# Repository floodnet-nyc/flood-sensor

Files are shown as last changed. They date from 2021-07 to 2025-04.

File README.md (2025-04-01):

<p align="center">
    <a href="https://www.floodnet.nyc/">
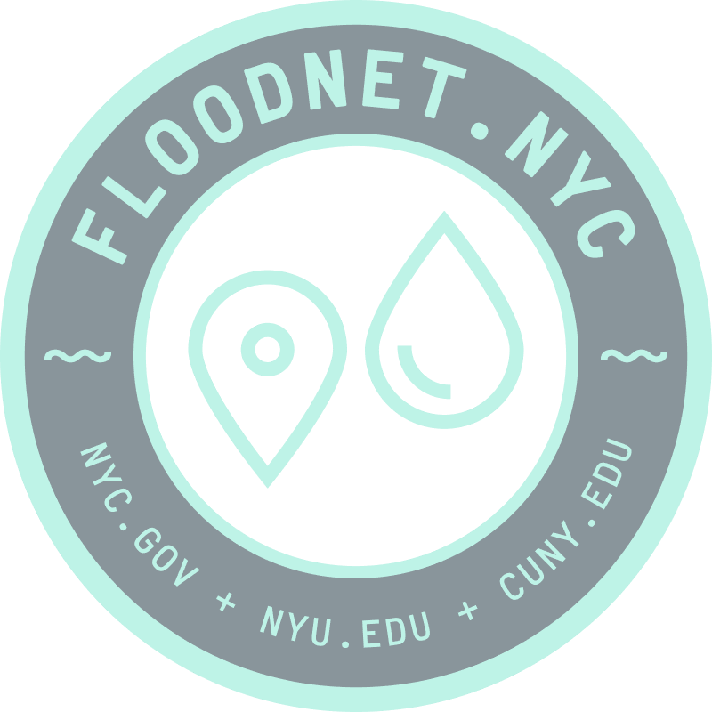
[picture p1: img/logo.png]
        
    </a>
</p>
<br>

<table class="center">
<thead>
  <tr>
    <td><a href="https://docs.google.com/forms/d/e/1FAIpQLScIM4Nu0z6l5HO8uzl9k4RGRSzU549LakNMNijnjGAHodFg9w/viewform" target="_blank" rel="noopener noreferrer">Suggest a sensor location</a><br></td>
    <td><a href="mailto:info@floodnet.nyc" target="_blank" rel="noopener noreferrer">@ Contact us</a></td>
  </tr>
</thead>
</table>

<br>
This repository houses information regarding the build, deployment, and maintenance of the FloodnNet project's flood sensor.

- [About FloodNet](#about-floodnet)
- [How to build a flood sensor](#how-to-build-a-flood-sensor)
- [How to deploy a flood sensor](#how-to-deploy-a-flood-sensor)
- [How to maintain a flood sensor](#how-to-maintain-a-flood-sensor)
- [How to submit an issue](#how-to-submit-an-issue)
- [Additional resources](#additional-resources)

If you make use of the hardware designs and firmware in this repository for any purpose, the project should be listed as “FloodNet (New York University and The City University of New York)”, and cited as the following:

Mydlarz, C., Sai Venkat Challagonda, P., Steers, B., Rucker, J., Brain, T., Branco, B., Burnett, H.E., Kaur, A., Fischman, R., Graziano, K., Krueger, K., Henaff, E., Ignace, V., Jozwiak, E., Palchuri, J., Pierone, P., Rothman, P., Toledo-Crow, R., Silverman, A.I. (2024) FloodNet: Low-cost ultrasonic sensors for real-time measurement of hyperlocal, street-level floods in New York City. Water Resources Research, 60, e2023WR036806. https://doi.org/10.1029/2023WR036806

Please note that the contents of this repository are subject to the Creative Commons Attribution-NonCommercial-ShareAlike 4.0 International License (see footer of page).

# About FloodNet
FloodNet is a partnership between academic researchers at New York University and the City University of New York, and NYC municipal agencies (NYC Mayor’s Office of Climate & Environmental Justice and Mayor’s Office of the Chief Technology Officer), working in consultation with community organizations.



**note:** This repository is relevant only to the flood sensors, i.e., the end-device sensing component within a larger sensor network infrastructure. For more details about the complete network infrastructure(figure below) refer to the FloodNet [documentation website](https://floodnet-nyc.github.io//real-time-data-pipeline/#31-data-flow-pipeline-overview). 

Further, [Gateway](https://github.com/floodnet-nyc/floodnet-gateway) and [NodeRED](https://github.com/floodnet-nyc/floodnet-nodered) repositiories are linked in the additional resources section for reference. 

<br>
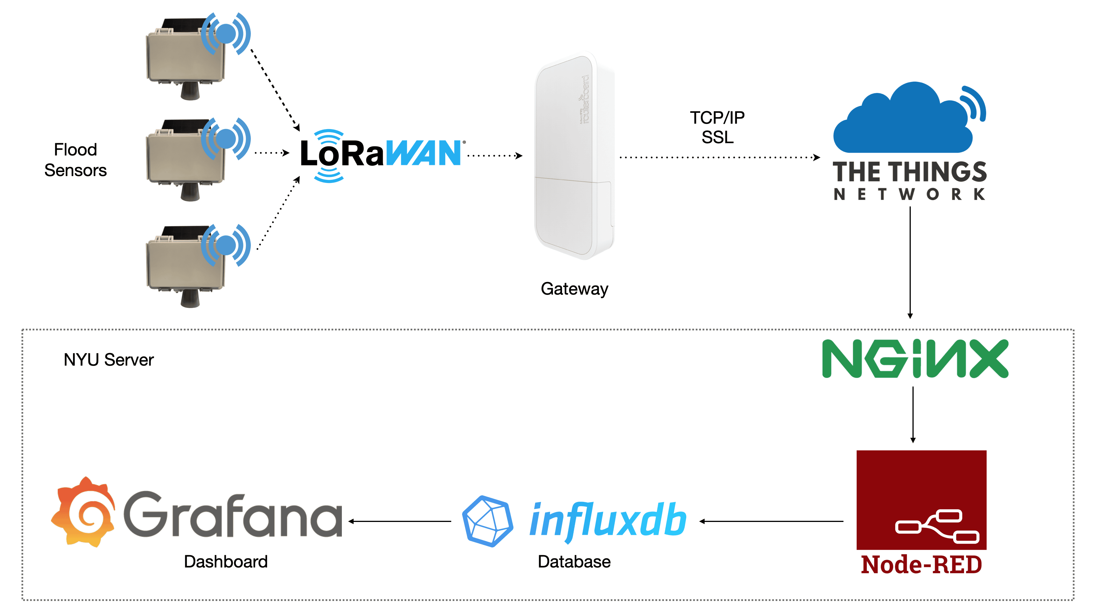
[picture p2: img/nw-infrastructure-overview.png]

<br>

# How to build a flood sensor
This section contains the necessary resources to build a flood sensor from the raw materials state to a final product. 

## BOM
  - The total sensor cost per unit is below $200. 
  - When mounting hardware is included the total cost of the sensor plus mounting hardware comes around $210. 
  - A list of complete bill of materials for the sensor and mounting hardware is available in the [BOM](https://github.com/floodnet-nyc/flood-sensor/tree/main/hardware/BOM.md) document.

## Sensor build instructions with Quality Assurance Procedures
  - The step-by-step sensor build instructions including images and quality assurance steps are detailed in the [Sensor build with Quality Assurance Procedures](https://floodnet-nyc.github.io//quality-management/sensor-assembly-qap/) page on the FloodNet's documentation website to ensure high quality sensor builds with consistency.

### Installing sensor software
  - After the sensor assembly stage is the installation of the sensor firmware. To install the sensor's firmware follow the steps detailed in the of the firmware folder's [README.md](https://github.com/floodnet-nyc/flood-sensor/tree/main/firmware#readme). 

## Quality Control and testing
  - After the production/assembly stage, quality control (QC) tests are performed on every sensor to validate the data quality. 
  - In-lab testing and Quality Control checks are detailed in the FloodNet's [Quality Control page](https://floodnet-nyc.github.io//quality-management/quality-control/) on the documentation website.

<br>

# How to deploy a flood sensor

The FloodNet's flood sensors are deployed on street sign posts, over the sidewalk, following the permission from NYC to do so. This section details instructions to identify a deployment location, choosing an optimal mounting option, and finally, deploying a flood sensor.

## Deployment location identification strategy
  - Sensor deployment locations are determined in consultation with government and community partners, using criteria that include estimated risks of flood hazard and impact, social vulnerability, and spatial coverage.
  - Further, multiple assessment strategies combined contribute to the sensor locations identification process, including but not limited to - community engagement, flood maps, historically flood-prone neighborhoods, and city agency recommendations.
  - The [Flood Hotspots Identifacation manual](https://github.com/floodnet-nyc/flood-sensor/blob/f238a23d92843cad2c458d202e6335a0c9118099/deployment/flood-hotspots-identification.md) details the strategies mentioned above.

## Flood sensor deployment steps

#### Choosing an optimal mounting option
The sensor is susceptable to noise in the following scenarios - mounted over grass, mounted over soil/bumpy sidewalk, and when sensor measuring area is of different heights for example is half sidewalk and half road. 

<p>
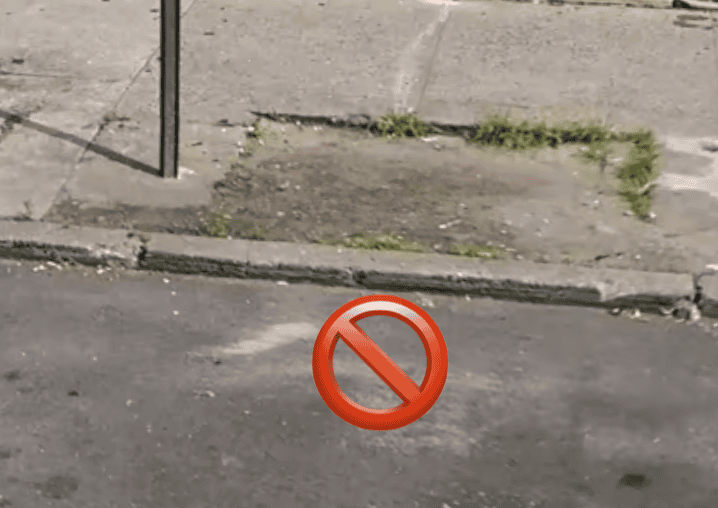
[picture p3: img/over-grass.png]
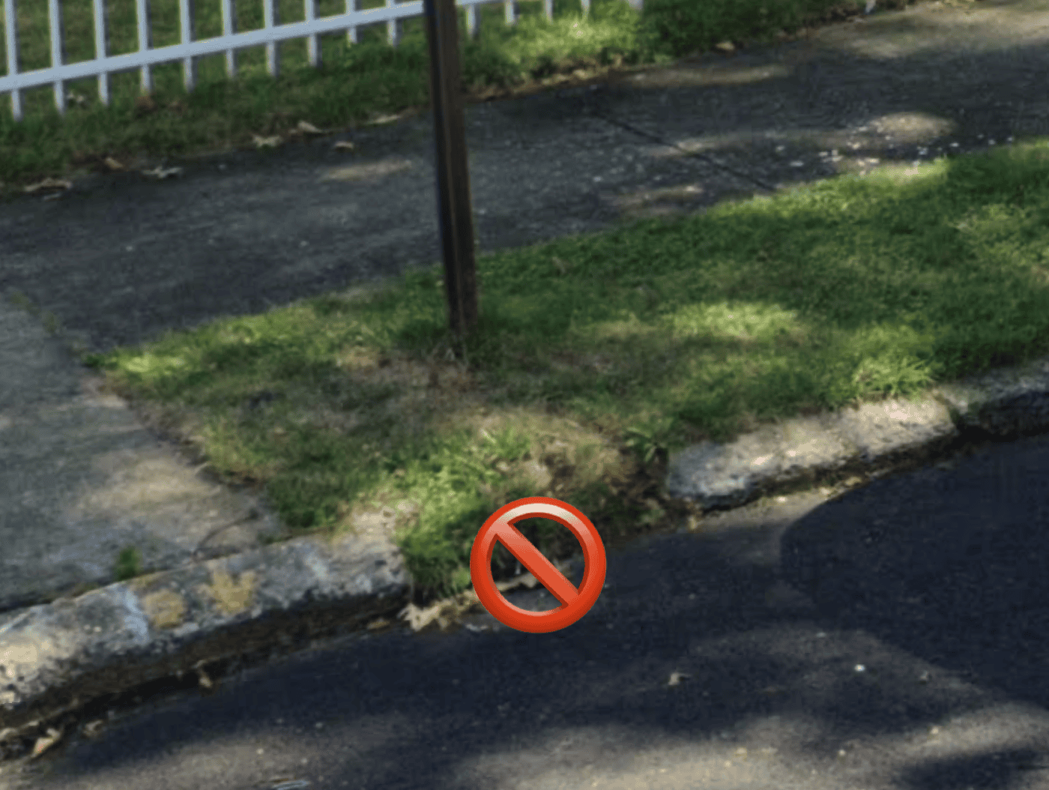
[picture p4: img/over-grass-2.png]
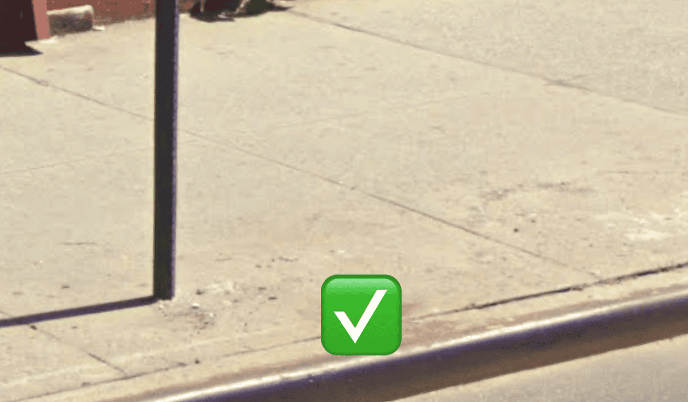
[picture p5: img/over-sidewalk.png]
   
</p>

#### Deployment steps
1. Sensor can be mounted in two ways: on the front side, and on the back side of the drive rail. 
    
    **Back Side:** If mounting on the back side (figure below), the mount needs to be wider and in this case use a [Slotted Flat Mending Plate](https://a.co/d/36uG9IK) and 4" hex bolts for mounting the whole assembly onto the drive rail.
  
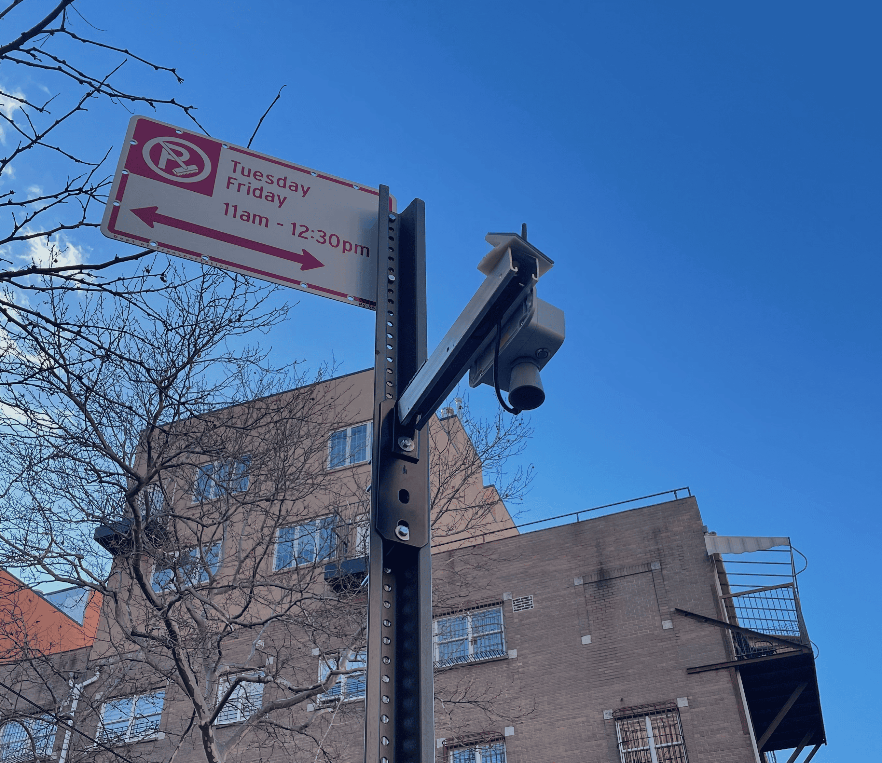
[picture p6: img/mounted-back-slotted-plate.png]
       
      <br>

    **Front side:** When mounting on the front side, the L-bracket can be direclty mounted onto the drive rail like shown below.
  
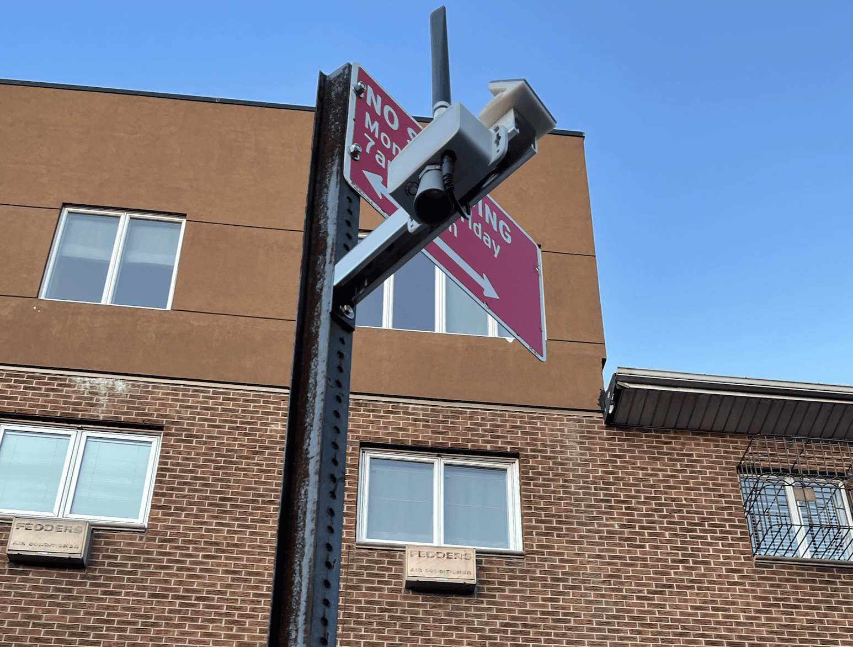
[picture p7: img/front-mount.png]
       
      <br>

2. Align the sensor horizontal to the ground, while avoiding too much tilt on any sides.

3. **Solar panel mount:** Mount the panel on the top of the struct channel mount with the panel facing the South direction.

4. Bundle the solar cable and ziptie it to secure it beneath the struct chanel and away from the sensor cone.

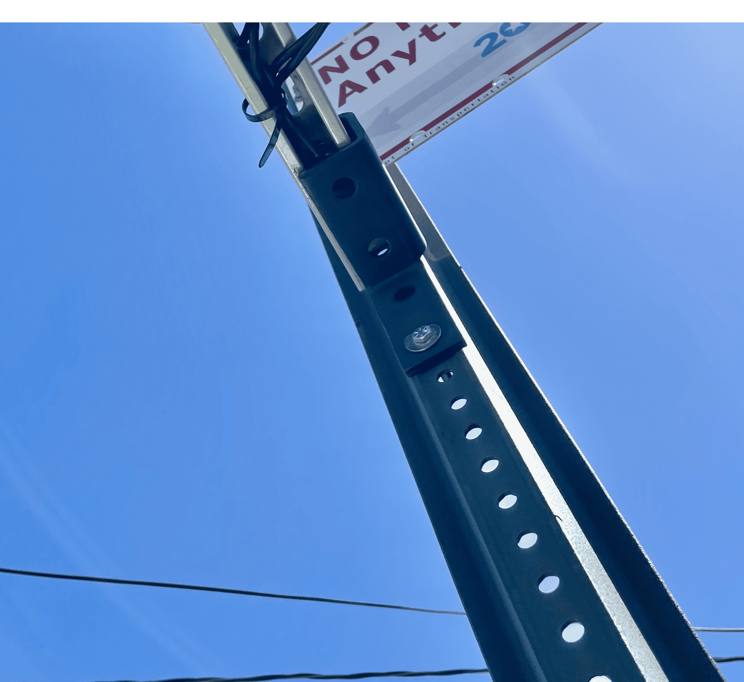
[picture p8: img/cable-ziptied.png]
     
    <br>

# How to maintain a flood sensor
The maintenance maual is the [README.md](https://github.com/floodnet-nyc/flood-sensor/tree/main/maintenance/README.md) document which contains the information needed for sensor maintenance runs and visits. Below are a list of common maintenance visit reasons listed and linked to the recommended fixes detailed on the manual. 

## Common maintenance visit reasons
  - Trending down battery profile due to:
    - Not enough sunlight 
    - Battery failure
  - Brownouts
  - Antenna Issues
  - Manual Firmware updates
  - Operational Issues:
    - Inaccurate or unexpected sensor measurements
    - No sensor measurements
  - Sensor swapouts in the case of critical damages or failures

# How to submit an issue
Any kind of issues or contributions are welcome! To submit an issues/bugs/fixes please use the github issues feature of this repo [here](https://github.com/floodnet-nyc/flood-sensor/issues/new/choose). Please use the templates below and tag the issue with its relevant label when opening a new issue. 

**For general issues:**
```
  ### Issue/Bug/Suggestion 
  - description here about the issue
  - any reasoning or observations

  ### Sensor version and firmware version 
  - version of the sensor hardware and/or firmware

```

**For issues related to sensor operations:**
```
  ### Issue/Bug/Suggestion 
  - description here about the issue
  - sensor up/down with date and time
  - any reasoning or observations

  ### Sensor version and firmware version 
  - version of the sensor hardware and/or firmware

  ### Metadata
  1. `deployment_id`
  2. `dev_id`
  3. deployed by information

  ### Fixes/Action
  - 

```

# Additional resources
1. [An excellent guide to soldering by Adafruit!](https://learn.adafruit.com/adafruit-guide-excellent-soldering/tools)
2. [Common soldering problems and fixes](https://learn.adafruit.com/adafruit-guide-excellent-soldering/common-problems)
3. [NYC Stormwater floodmaps](https://experience.arcgis.com/experience/6f4cc60710dc433585790cd2b4b5dd0e)

------------------------------------------------------------------------------------------------------------------------
Shield: [][cc-by-nc-sa]

This work is licensed under a
[Creative Commons Attribution-NonCommercial-ShareAlike 4.0 International License][cc-by-nc-sa].

[][cc-by-nc-sa]

[cc-by-nc-sa]: http://creativecommons.org/licenses/by-nc-sa/4.0/
[cc-by-nc-sa-image]: https://licensebuttons.net/l/by-nc-sa/4.0/88x31.png
[cc-by-nc-sa-shield]: https://img.shields.io/badge/License-CC%20BY--NC--SA%204.0-lightgrey.svg

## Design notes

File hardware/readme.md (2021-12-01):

# Mounting hardware
The FloodNet sensor uses readily available hardware for mounting to a variety of street infrastructure. The sensor alone weighs **0.5lb** and the complete assembly including mounting hardware weighs **3lbs**. The typical mounting condition consists of the sensor itself bolted to the underside of a 1 5/8" aluminum strut channel. Aluminum was chosen to reduce the overall load on the cantilever. The 3D printed solar panel is bolted to the top of the strut channel and can be rotated for optimizing sunlight pickup. The mounting hardware can adapt to various conditions.

<p align="center">
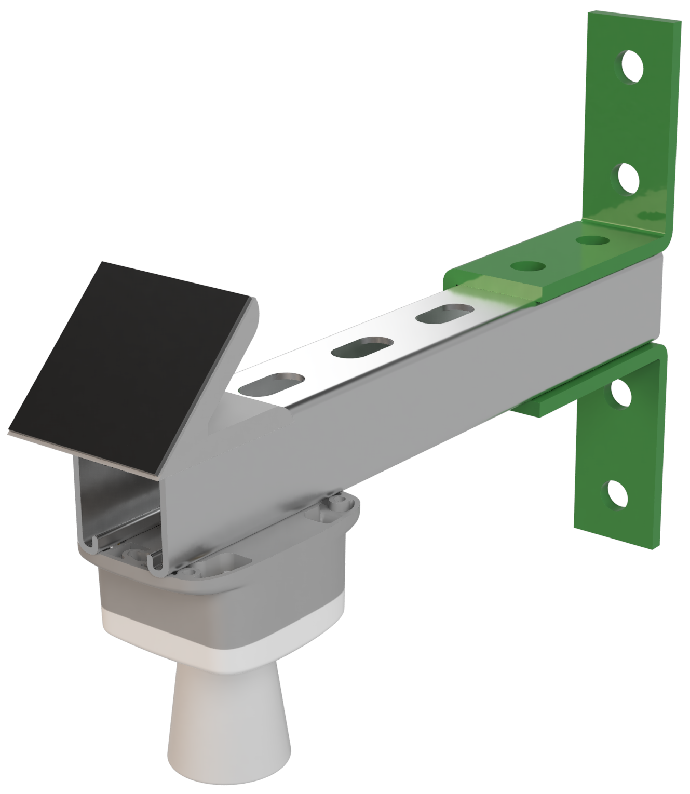
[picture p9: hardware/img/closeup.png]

</p>

The most common mounting option is bolted to a U-channel at **>10ft** from the ground. See image below.

<p align="center">
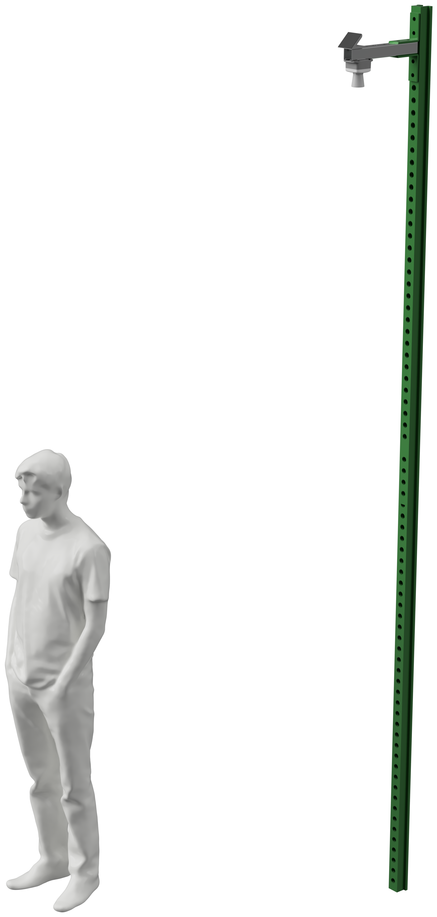
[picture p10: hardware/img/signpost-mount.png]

</p>

The sensor can be mounted to light poles of varying diameter using 300lb steel strapping. The ultrasonic sensors used to detect flood depth typically have a maximum range of 16ft but 32ft models can be added. Light pole mounting on the light overhang would likely require 32ft ultrasonic sensors. See image below for a vertical light mount scenario.

<p align="center">
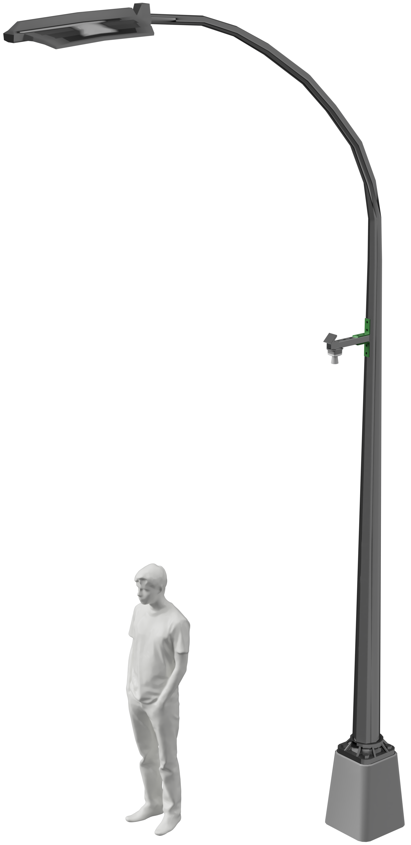
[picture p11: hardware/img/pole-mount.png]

</p>

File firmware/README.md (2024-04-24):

# Firmware technical documentation

- [Firmware technical documentation](#firmware-technical-documentation)
  - [Installation and setup](#installation-and-setup)
    - [Arduino IDE](#arduino-ide)
    - [Installing CubeCell Library](#installing-cubecell-library)
    - [Registering the device to The Things Network](#registering-the-device-to-the-things-network)
    - [Creating an end-device](#creating-an-end-device)
   
  - [Usage](#usage)
    - [Installing the device secrets](#installing-the-device-secrets)
    - [Compiling and Uploading the firmware to the sensor](#compiling-and-uploading-the-firmware-to-the-sensor)
    - [Uplink packet format](#uplink-packet-format)
    - [Downlink packet format](#downlink-packet-format)
    - [Modifying Sensor Configuration using Downlinks](#modifying-sensor-configuration-using-downlinks)
      - [Changing dutycycle](#changing-dutycycle)
      - [Changing sensor mode](#changing-sensor-mode)
      - [Changing sampling rate](#changing-sampling-rate)
      - [Changing number of sensor readings per measurement](#changing-number-of-sensor-readings-per-measurement)
      - [Changing multiple parameters via single downlink](#changing-multiple-parameters-via-single-downlink)
      - [Changing sensor state](#changing-sensor-state)

## Installation and setup

### Arduino IDE
For simplicity, Arduino IDE has been used in the documentation but other IDEs can also be used. Arduino IDE, can be downloaded from [Arduino's website](https://www.arduino.cc/en/software). The Arduino IDE is used for uploading the firmware to the microcontroller.

Add HelTec Boards to the IDE, there are two ways:
 - Using Arduino's Boards Manager.
     - Open Arduino IDE, and goto `File->Preferences->Settings`
      <br> 
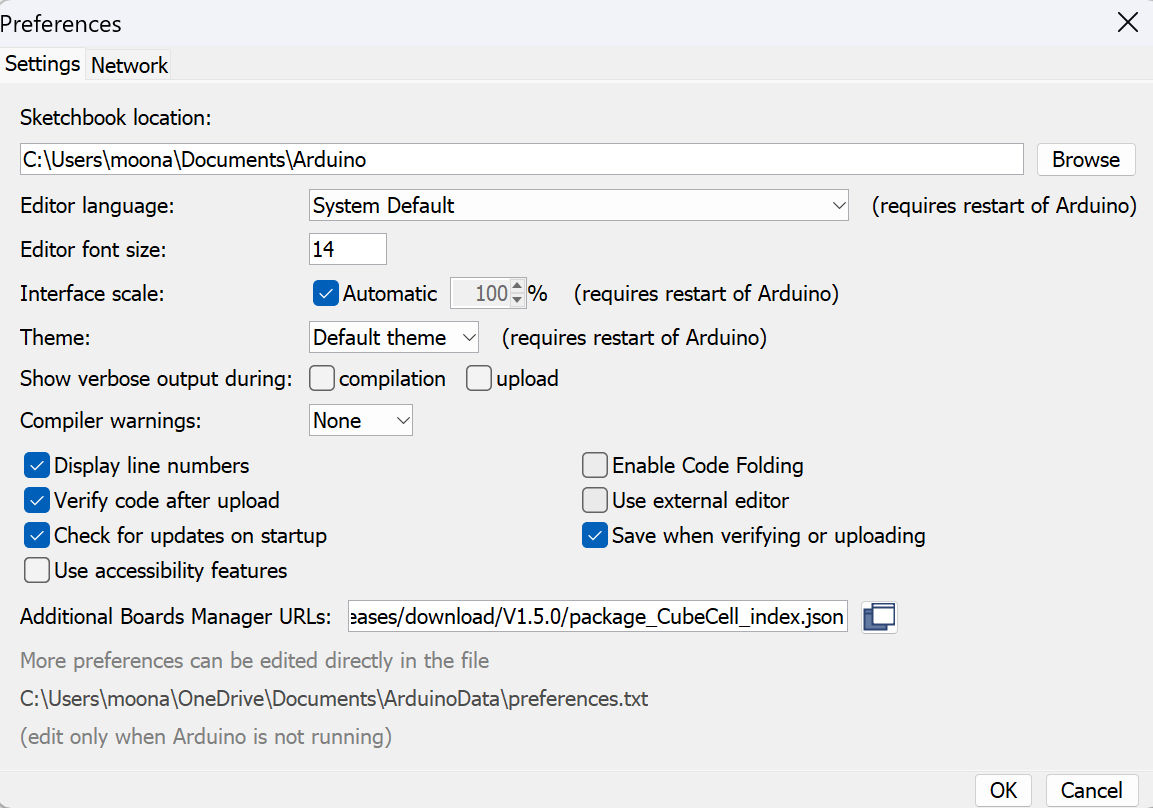
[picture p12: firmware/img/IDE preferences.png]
       
     
     - Enter this url `https://github.com/HelTecAutomation/CubeCell-Arduino/releases/download/V1.5.0/package_CubeCell_index.json` to board manager URLs. Then hit 		 ok.
     - After that goto `Tools->Board->Boards Manager`, and search CubeCell. In the new pop-up dialog, select the latest releases and click install. 
      <br>
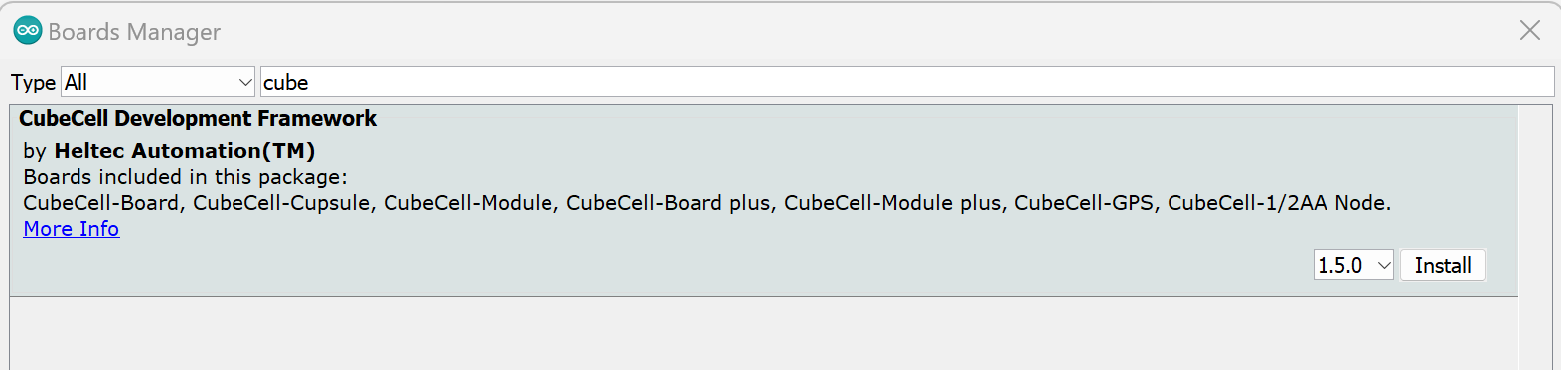
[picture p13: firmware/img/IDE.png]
      
 - Using Github.
     - Follow the instructions mentioned [here.](https://github.com/HelTecAutomation/CubeCell-Arduino/blob/master/InstallGuide/windows.md)
     </a>

### Installing CubeCell Library
This repo is built to run on CubeCell's example library. To install the CubeCell's library, follow the instructions on their repo [here](https://github.com/HelTecAutomation/CubeCell-Arduino/tree/master/InstallGuide)

### Registering the device to The Things Network
 Setting up The Things Network
  - Make an account on The Things Network at [here](https://www.thethingsnetwork.org/)
  - Now Login [here](https://nam1.cloud.thethings.network/console/) with your The Things ID credentials.
  - If the target application at which your device will be registered is not created yet, follow this step.
      - Goto Application-> Create application.
        <br>
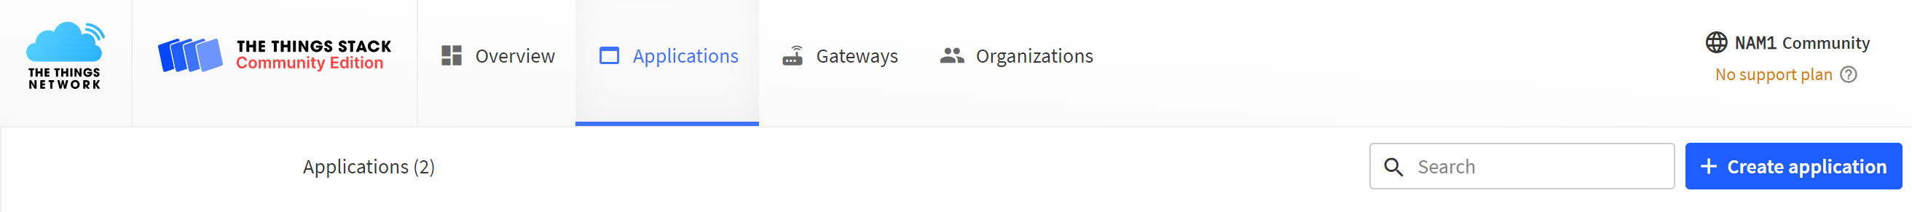
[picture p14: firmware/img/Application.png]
        
      - Enter Application ID(should be unique) and Application Name.

### Creating an end-device
 Registering End Device.
   - Goto the application then click on ‘Register end device’.
     <br> 
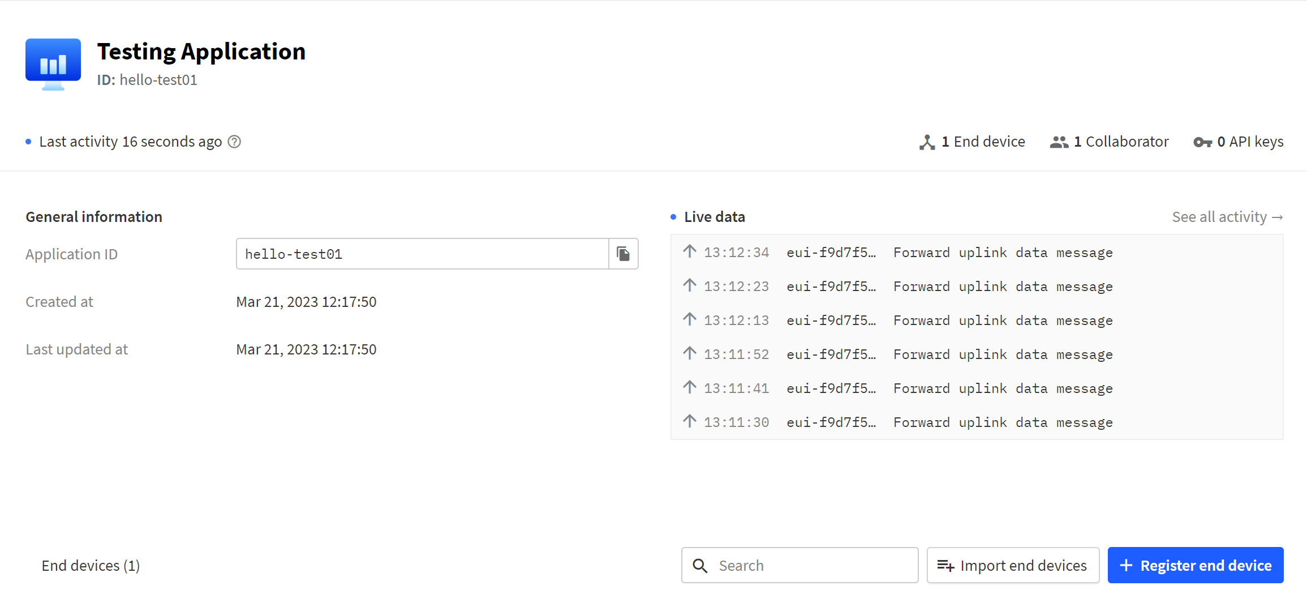
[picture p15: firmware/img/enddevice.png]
       
   - Select the end device in the LoRaWAN Device Repository. Refer the following image.
     <br> 
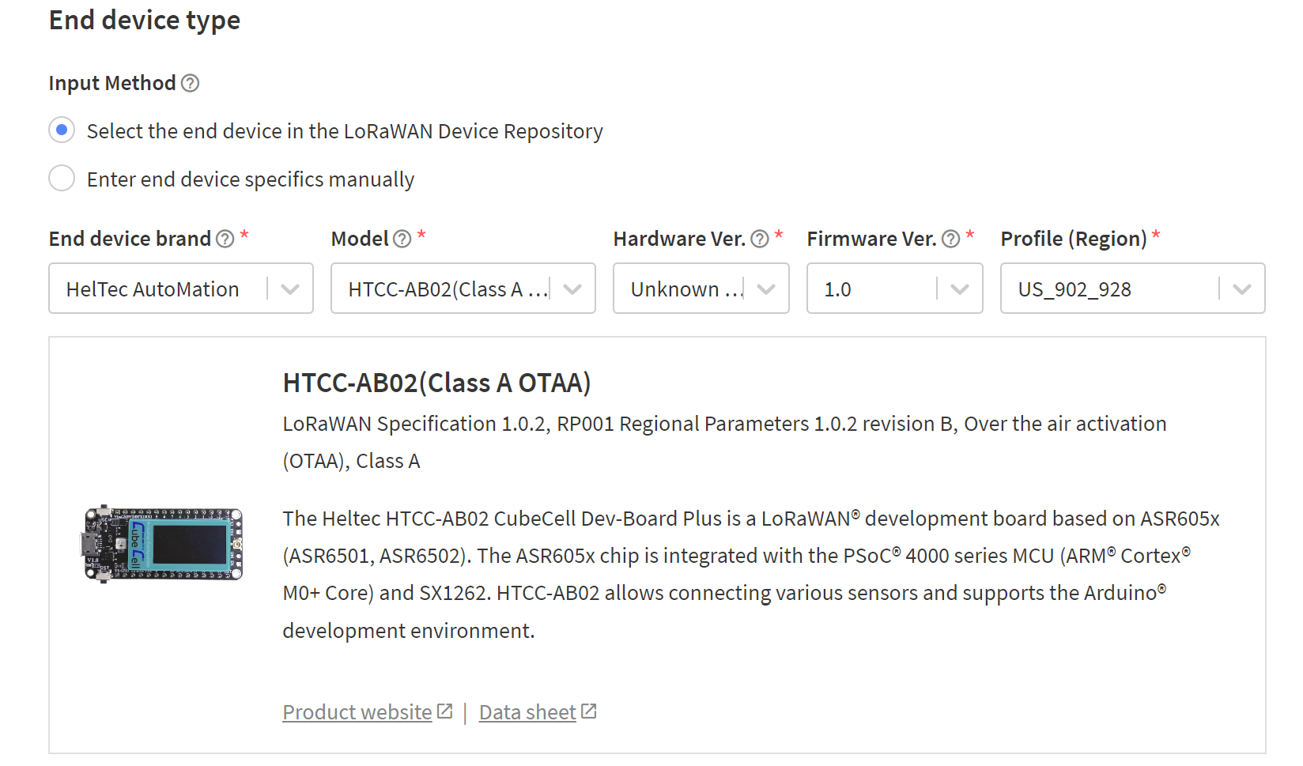
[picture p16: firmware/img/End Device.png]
      
   - For the `JoinEUI` field, an random ID can be used except all zeros (for example, `FA CD 67 98 HY 7J 54 00` can be used but not `00 00 00 00 00 00 00 00`). Next, the fields `DevEUI` and `AppKey`needs to be entered, which can be generated by clicking on generate. And then click on Register end Device. 

## Usage
 To use this library, user can simply open firmware.ino from the [firmware folder](https://github.com/floodnet-nyc/flood-sensor/tree/main/firmware).
### Installing the device secrets
 - Connecting CubeCell to the Arduino IDE.
    - Open Arduino IDE and goto `Tools>Board>CubeCell>HTTC(AB02)`. And set the configurations according to the image below.
      <br> 
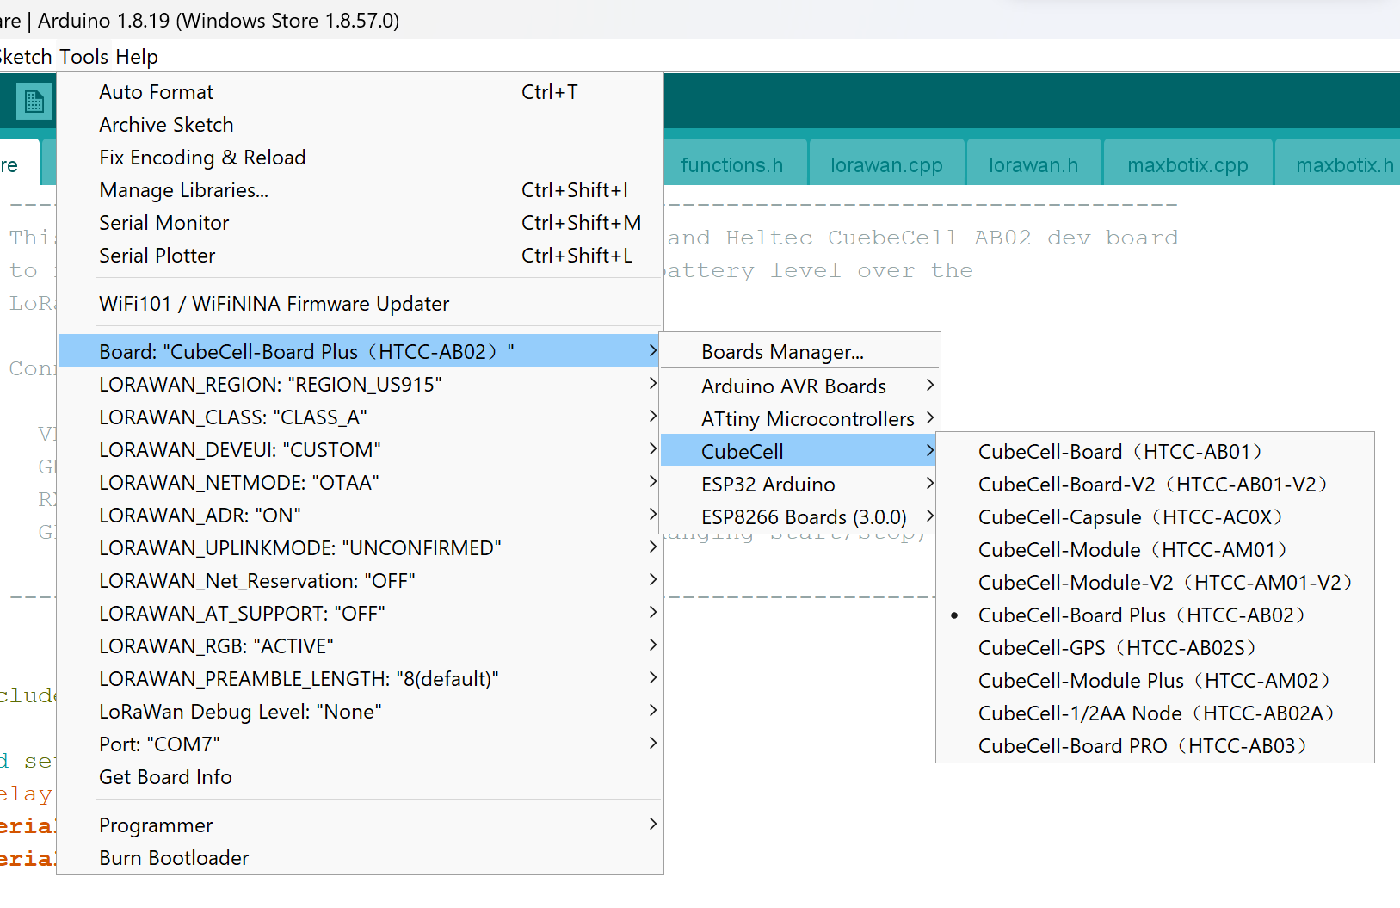
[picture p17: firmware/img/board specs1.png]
       
    - Connect the HelTec CubeCell board to the computer via a high quality Micro USB cable. CP2102 driver is required, most of the time it will install
      automatically and if didn't install automatically, please refer to this [document.](https://docs.heltec.cn/general/establish_serial_connection.html).
    - Select the port at which CubeCell is connected to computer by going to `Tools>Port`.
 - EEPROM should be cleared every time when changes are made to device secrets. Clear the EEPROM which you have to upload the following example.
      Goto `File->Examples->EEPROM->eeprom_clear` and upload the code by clicking on the right arrow symbol.
 - Adding device secerts in the firmware.
    - Open `firmware.ino`. This will open all the files reuired by the sensor to be working.
    - Open device_secrets.h file from the tab.
      <br> 
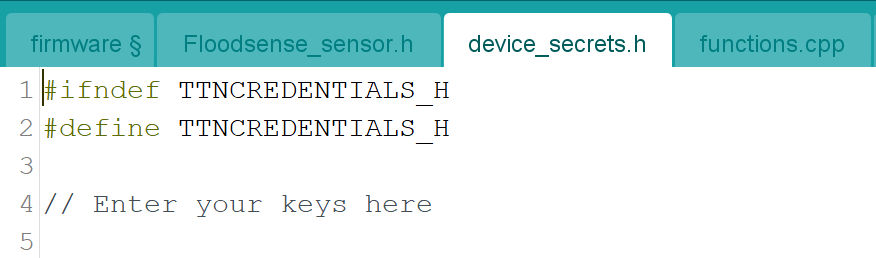
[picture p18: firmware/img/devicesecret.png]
       
    - Enter the `DevEUI`,`JoinEUI` and `AppKey` in `TTN_DEVEUI`, `TTN_APPEUI` AND `TTN_APPKEY` respectively like shown in the image below. 
      <br> 
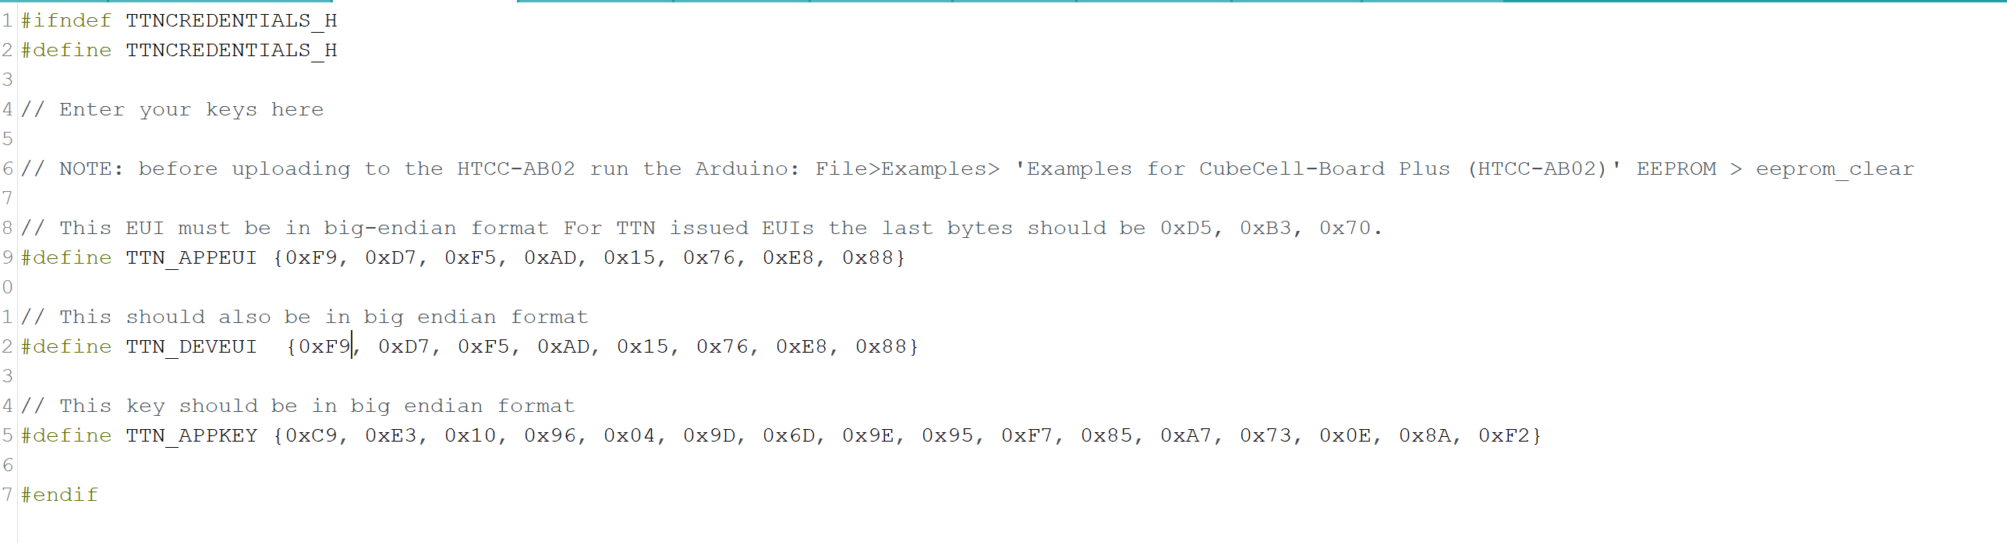
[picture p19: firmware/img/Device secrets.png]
       
    - Save the file but it's in read only mode so save it in another location. Goto File and click Save. A prompt will open then hit OK and then Save it to another    
      location. NOTE: Save the file each time you make changes in the sensor IDs.

### Compiling and Uploading the firmware to the sensor
  - After installing the device secerts. Goto firmware tab and compile the code by clicking on the tick symbol. Then upload it.
  - Verify if CubeCell is working correctly, by opening the Serial Monitor in Arduino IDE. Make sure CubeCell is still connected to the computer.
    - On clicking on the magnifying icon the serial monitor will open.
    - Set the Baud to 115200.
    </a>
    After setting the baud data will start showing on the serial monitor. Verify your `DevEUI`, `AppEUI` and `AppKey` in the window.
    <br>
    <br> 
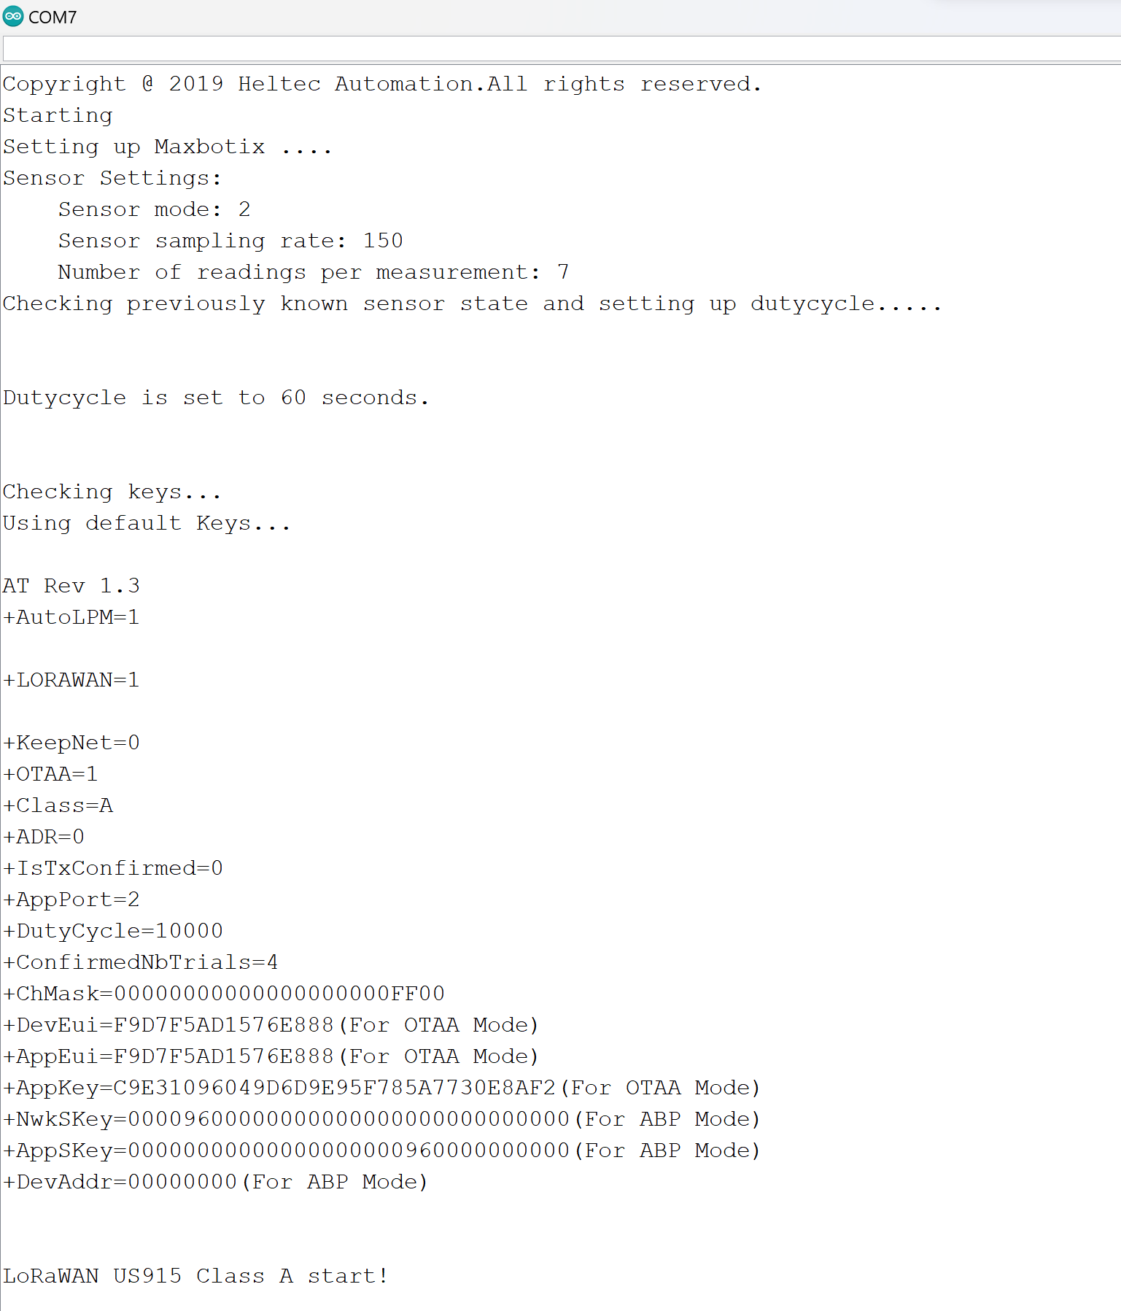
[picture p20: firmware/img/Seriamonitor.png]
     

### Uplink packet format

Measurement is the regular uplink packet format when the sensor is operational and in the sensing mode. In stop mode, the sensor sends its current configuration as the uplink payload information. 

**Measurement:**

| Error flags  | Battery Level | Ultrasonic reading  |
|---|---|---|
| 1 byte | 2 bytes | 2 bytes |

**Cfg packet format:**

| Error flags  | Sensor Mode | Sensor Sampling Rate | Sensor Number of Readings |
|---|---|---|---|
| 1 byte : 255 or 0xFF | 1 byte | 2 bytes | 1 bytes |

**Error Flags:**

| bit 7 | bit 6 | bit 5 | bit 4 | bit 3 | bit 2 | bit 1 | bit 0 |
| ---- | ---- | ---- | --- | --- | --- | --- | --- |
| Used only for CFG update (all other bits are high) | | | | | | | SD error flag|

^empty flags above - bits 1-6 are for future use.

### Downlink packet format

```<header> <command>```

| Header | Command            | Functionality                                                |
| ------ | ------------------ | ------------------------------------------------------------ |
| `0x4D` | Sensor Mode Change | Changes sensor aggregate, duty cycle, measuring delta, number of readings for averaging. |
| `0x41` | Application Change | Changes LoRaWAN Application                                  |
| `0x4F` | Sensor State       | `Start/Stop/Reset`. On a Reset the default sensor state is `Stop`, and it sends CFG packets as uplink. Starts sensing when changed to `Start` state. `Reset` resets the sensor using a watchdog timer. |

### Modifying Sensor Configuration using Downlinks

Following are types of downlinks available categorized based on their functionality.

#### Changing dutycycle

Uplink frequency at the end node is determined by the TX_INTERVAL. This TX_INTERVAL is used as a variable in this library to add the functionality of varying duty cycle. Few examples of changing duty cycle by updating `TX_INTERVAL` are mentioned below:

| Command| Explanation|
|---|---|
| `00 3C`| duty cycle = 60 seconds and 2 bytes are used for the downlink|
| `3C` |duty cycle = 60 seconds and lowest payload size |
| `01 68`| duty cycle = 360 seconds and 2 bytes are used for the downlink|
|`00 3C 00 00 00 00` | Only duty cycle is changed and rest are unchanged. 6 bytes used for the downlink |

#### Changing sensor mode
The sensor mode can be changed by adding non-zero values to the sensor mode byte in the downlink packet. Any invalid modes entered are discarded. Examples:

| Command | Explanation|
|---|---|
| `00 00 01` | changing sensor mode to 1. Consumes 3 bytes: minimal mode change|
| `00 00 01 00 00 00` |changing sensor mode to 1 and the rest are unchanged. Consumes 6 bytes |
| `00 00 06 00 00 00` |Discarded and no change since 6 is an invalid mode. Consumes 6 bytes |
| `01`| Valid packet format but doesn't change sensor mode, instead duty cycle is changed to 1 sec|

#### Changing sampling rate
The sensor sampling rate can be changed by adding non-zero values to the corresponding bytes in the downlink packet. Examples:

| Command | Explanation|
|---|---|
| `00 00 00 00 FA` | changing sensor sampling rate to 250ms. Consumes 5 bytes: minimal sampling rate change|
| `00 00 00 04 E2 00` |changing sensor sampling rate to 1250ms and the rest are unchanged. Consumes 6 bytes |
| `04 E2`| Valid packet format but doesn't change sensor sampling rate, instead duty cycle is changed to 1250 sec|

#### Changing number of sensor readings per measurement
Similarly, the number of sensor readings per measurement can be changed by adding non-zero values to the corresponding bytes in the downlink packet. A maximum of 20 is allowed. Examples:

| Command | Explanation|
|---|---|
| `00 00 00 00 00 05` | 5 readings per measurement. Consumes 5 bytes: minimal sampling rate change|
| `00 00 00 00 00 22` | invalid, maximum of 20 readings are allowed and the configuration is unchanged.|

#### Changing multiple parameters via single downlink
Multiple sensor parameters can be changed via downlink and below are such examples:

| Command | Explanation|
|---|---|
| `00 78 02 00 00 05` | Change duty cycle to 120 seconds, sensor mode to 2 (Median) and 5 readings per measurement|
| `00 78 03 00 FA 12` | Change duty cycle to 120 seconds, sensor mode to 1(Mode), 250ms sampling rate and 18 readings per measurement|

**Note:** the above downlink payload formats must be implemented with caution, else there is a danger of sleeping the MCU for unwanted periods of time or indefinitely or even a possible crash!  

#### Changing sensor state

| Operation | Command             |
| --------- | ------------------- |
| Start     | `73 74 61 72 74`    |
| Stop      | `73 74 6f 70`       |
| Reset     | `72 65 73 65 74`    |

## TTN Decoder 
```
// decoder variable contains Error Flags followed by Battery and sensor data.
function Decoder(b, port) {
  var decoded = {};

  // Error Flags
  /*
  Format:
    |--------------------------------------------- Error Flags  -----------------------------------------------------------------------------------------------------------|
    |     bit 7                                                    |     bit 6   |     bit 5    |     bit 4    |     bit 3    |     bit 2    |     bit 1    |     bit 0    |
    |     Used only for CFG update (all other bits are high)       |             |              |              |              |              |              | SD error flag|
  255 or FF is a CFG update
  */
  var errorFlag = b[0];

  if (errorFlag == 255) {
    // Payload is Sensor cfg update
    /*
      CFG update uplink Format:
      | Error Flag  |   sensor_sleep   |    sensor_agg     |   sensor_meas_delta     | sensor_reading_count   |    sensor_state   |    fw_ver       |
      |    255 (FF) |     2 bytes      |      1 byte       |          2 bytes        |          1 byte        |        1 byte     |    6 bytes      |
                 
      Sensor State:
      |  Start  |   Stop  |  Reset  |
      |   's'   |   'x'   |   'r'   |

    */

    // Duty cycle
    var sensor_sleep = (b[2]<< 8) | b[1];
    decoded.sensor_sleep = sensor_sleep;

    // Sensor Mode
    var sensor_agg = b[3];
    decoded.sensor_agg = sensor_agg;

    // Sensor Sampling Rate
    var sensor_meas_delta = (b[5] << 8) | b[4];
    decoded.sensor_meas_delta = sensor_meas_delta;

    // Sensor number of readings per measurement
    var sensor_reading_count = b[6];
    decoded.sensor_reading_count = sensor_reading_count;

    // Sensor State
    var sensor_state = b[7].toString();
    if (sensor_state == "115"){
      sensor_state = "Sensing";
    } else if (sensor_state == "120"){
      sensor_state = "CFG Update";
    } else if (sensor_state == "114"){
      sensor_state = "Reset";
    }
    decoded.sensor_state = sensor_state;

    // Firmware Version
    let major = b[8].toString();
    let minor = b[9].toString();
    let patch = b[10].toString();
    let v = "v";
    let dot = ".";
    let fw_ver = v.concat(major,dot,minor,dot,patch);
    decoded.fw_ver = fw_ver;

  } else {
    
    // Regular Payload
      var sdError, battery, distance;
      // Converting Error Flag bits
      sdError = errorFlag % 2;
      decoded.sdError = sdError;
  
      // battery
      battery = (b[2] << 8) | b[1]; // battery in centi Volts
      battery = battery / 1000; // Convert to Volts
      decoded.battery = battery;
  
      // distance
      distance = (b[4] << 8) | b[3];
      decoded.distance = distance;
      
      // // Regular Payload
      // var acc_mm, event_acc_mm, total_acc_mm, r_int_hr_mm, tips;
      
      // decoded.acc_mm = (b[0]|(b[1]<<8)|(b[2]<<16)|(b[3]<<32))/100;
      // decoded.event_acc_mm = (b[4]|(b[5]<<8)|(b[6]<<16)|(b[7]<<32))/100;
      // decoded.total_acc_mm = (b[8]|(b[9]<<8)|(b[10]<<16)|(b[11]<<32))/100;
      // decoded.r_int_hr_mm = (b[12]|(b[13]<<8)|(b[14]<<16)|(b[15]<<32))/100;
      // decoded.tipping_bucket_mm_per_min = (b[17]|(b[18]<<8));
      // decoded.tipping_bucket_mm_per_min = decoded.tipping_bucket_mm_per_min/1000;
    }
    
    return decoded; 
}
```

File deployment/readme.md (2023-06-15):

# Deployment playbook

## For the impatient

  -  [Flood Sensor Deployment Manual](https://github.com/floodnet-nyc/flood-sensor/blob/main/deployment/flood-sensor-deployment-manual.md) for sensors
  -  [Gateway guide](https://github.com/floodnet-nyc/floodnet-gateway) for gateways

## Priority neighborhood
1. Add suggested sensor locations to the ["**Sensor inbox**"](https://docs.google.com/spreadsheets/d/1PHg1eIUd0UxAiTazykVBoy64rBAW5rRA5NoZ6fUNqqc/edit#gid=1479948156) sheet, ensuring you've filled in all the required columns marked with an asterisk.
2. Identify the next priority neighborhood (this process is TBD) and use the filter on the "**Neighborhood**" column to isolate the suggested sensors located in that neighborhood.

## Gateway scouting and outreach
1. Using the [TTN Mapper](https://ttnmapper.org/heatmap), locate any blue icon-ed Things Network gateways within ~0.5 miles of the proposed deployment neighborhood and add them to the ["**Gateway inbox**"](https://docs.google.com/spreadsheets/d/1PHg1eIUd0UxAiTazykVBoy64rBAW5rRA5NoZ6fUNqqc/edit#gid=1479948156) sheet.
2. Using the [NYCHA building map](https://www.arcgis.com/apps/webappviewer/index.html?id=41c6ff5e73ec459092e982060b7cf1a1), [City facilities map](https://cmydlarz.carto.com/builder/e06a8892-1836-4241-9514-2b02cae1ac7b/embed), and [Google Maps](https://www.google.com/maps) - locate buildings that could potentially host a gateway and add them to the ["**Gateway inbox**"](https://docs.google.com/spreadsheets/d/1PHg1eIUd0UxAiTazykVBoy64rBAW5rRA5NoZ6fUNqqc/edit#gid=1479948156) sheet, prioritizing the following criteria:
   * Tall with un-occluded views of the area where sensors will be deployed
   * Central to and within ~1 mile of potential sensor locations
   * City owned preferably by: DEP, DOT, NYCHA, DCAS
3. Start outreach to each agency/building owner for blanket gateway mounting permissions.
4. Identify building managers and facilities personnel who can provide roof access.
5. Update the ["**Gateway inbox**"](https://docs.google.com/spreadsheets/d/1PHg1eIUd0UxAiTazykVBoy64rBAW5rRA5NoZ6fUNqqc/edit#gid=1479948156) sheet.

## Sensor scouting and deployment
1. To virtually scout sensor locations refer to [Flood Hotspot Identification Strategy](https://github.com/floodnet-nyc/flood-sensor/blob/main/deployment/flood-hotspots-identification.md) and follow the below steps:
   * Create new sheet for neighborhood by duplicating the ["**Template**"](https://docs.google.com/spreadsheets/d/1PHg1eIUd0UxAiTazykVBoy64rBAW5rRA5NoZ6fUNqqc/edit#gid=130763079) sheet and renaming
   * Complete all columns with as much information as possible.
   * Update the ["**Sensor Locations Planner**"](https://www.google.com/maps/d/u/3/edit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) map with proposed sensor locations.
2. Delete rows from ["**Sensor inbox**"](https://docs.google.com/spreadsheets/d/1PHg1eIUd0UxAiTazykVBoy64rBAW5rRA5NoZ6fUNqqc/edit#gid=1479948156) sheet for the sensors you have already migrated to their own neighborhood sheet.
3. Plan for deployment using [this guide for sensors](https://github.com/floodnet-nyc/flood-sensor/blob/main/deployment/flood-sensor-deployment-manual.md) and [this guide for gateways](https://github.com/floodnet-nyc/floodnet-gateway).
4. Deploy gateway and sensors!
5. Move deployed gateway row from ["**Gateway inbox**"](https://docs.google.com/spreadsheets/d/1PHg1eIUd0UxAiTazykVBoy64rBAW5rRA5NoZ6fUNqqc/edit#gid=1479948156) sheet to neighborhood sheet.
6. Update deployed date and any extra fields in the neighborhood sheet for deployed sensors.
7. Update the [Sensor Locations Directory](https://docs.google.com/spreadsheets/d/1NVvIKUWnidkvHxfQ3tJmftphjNo6dKeGr0YioP82oGE/edit#gid=0) with the newly deployed sensors.
8. Update the [Sensor Locations Directory - DOT](https://docs.google.com/spreadsheets/d/1ZReNvlH-R3MdetIZDS5ga3bWxmXC1i-LLoB1pRAIp6k/edit#gid=0) sheet and [Sensor Locations Directory - DOT](https://www.google.com/maps/d/edit?mid=1hVbk4Q3k9M8H7DdSSQZ9QwjQ_xt-dHmK&usp=sharing) map with the newly deployed sensors.
9. Migrate the newly deployed sensors from the "**Potential Sensors**" to the "**Deployed Sensors**" layer, adding the sensor's device ID to the "**name**" field.

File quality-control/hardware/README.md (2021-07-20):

# Hardware Quality Control
This folder contains Quality Control documents. These documents are meant to be a teaching tool and source of information to build a high quality hardware.

One of the hardware goals of FloodSense is to devise a community-buildable sensor design that meets industry standards - IP67 Waterproof, Weatherproof and is robust.

***The objectives of these manual are:***

- to provide a reference QC manual to quality inspectors
- to provide a reference QC manual to lab personnel/researchers/community members
- to reduce human error and improve the quality of the sensor by
  - providing detailed steps in order which are easy to follow
  - proper building instructions
  - notes on areas where things might go wrong

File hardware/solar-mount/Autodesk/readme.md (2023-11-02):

# Design That Was in Field 

<p align="center">
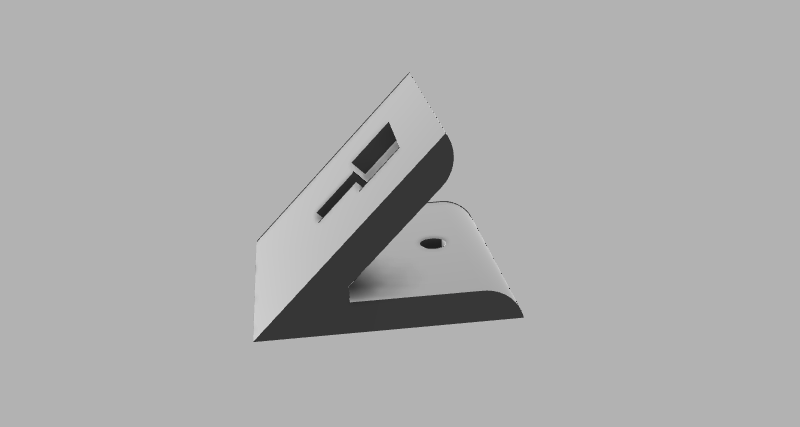
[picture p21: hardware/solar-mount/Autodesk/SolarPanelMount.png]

</p>

The design that was being utilized in the field offered great flexibility with it's compact size. However, repeated use in the field had exposed major shortcomings that had hindered sensor installations from going as smoothtly as possible. For starters, the overhang over the base of the sensor made it harder to screw in. This feat is difficult as it is due to it being done on a ladder 6 feet off the ground. Having to use an angled drill at the same time does very little to alleviate the difficulty level. In addition, several failure analyses performed on sensors that stopped working in the field revealed the root cause to be the solar panel becoming disconnected from the solar cable. When handling the solar panels during installation, it is very easy to tug on the cable more aggresively than intended, thus allowing for wires to become disconnected from the panel. 

# Version 1

<p align="center">
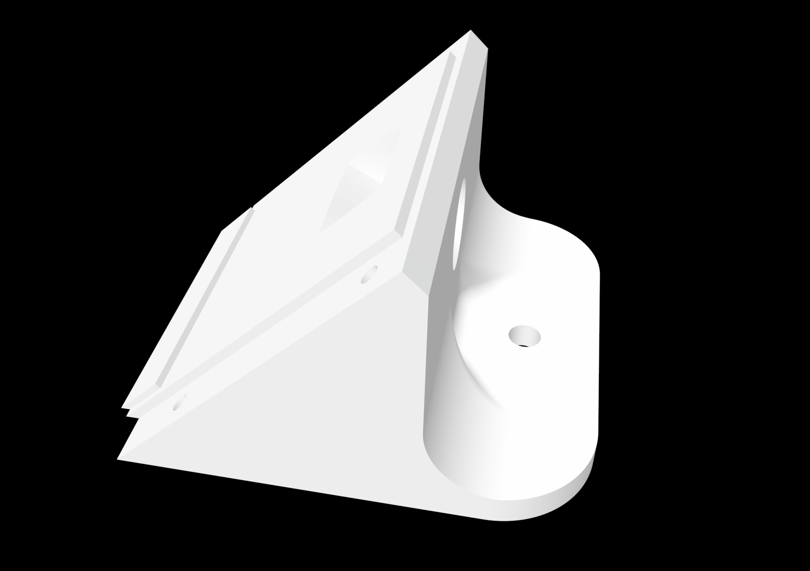
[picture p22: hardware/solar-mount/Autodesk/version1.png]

</p>

The first proposed revision of the original solar panel mount primarily addresses the concerns in screwing down the base. By extending the base of the solar panel mount out further, the electric drill can now be used straight down instead of at an angle. Although extending the base makes it easier to screw down the base, it also introduces an abundance of material to the design. When 3D printing, an important thing to keep in mind is how much material and support your design will need. The more you need, the longer it takes to complete a print and the less cost friendly it will be. 

Upon printing out the first version, the solar panel mount was noticeably more bulkier. Even putting aside the cost and time, a bulkier design would be more cumbersome to transport. Furthermore, there was still a lack of cable tension support for the strain behind the panel. 

Needless to say, there was alot more work to be done. 

# Version 2

<p align="center">
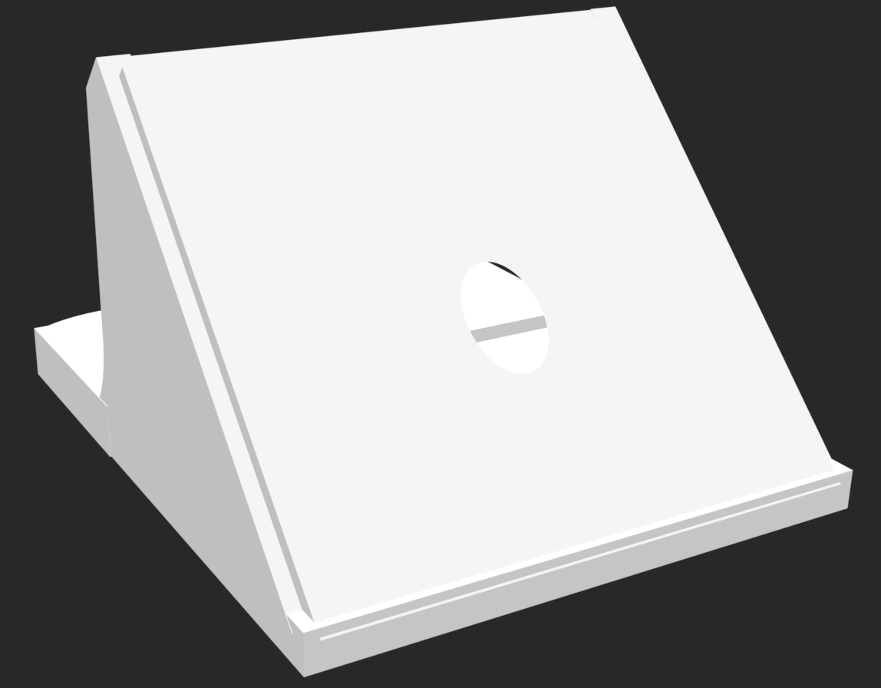
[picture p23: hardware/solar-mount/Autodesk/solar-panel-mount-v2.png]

</p>

The second version of the solar panel mount addresses the lack of cable tension support in the previous iterations. In an attempt to help ease the pull directly behind the solar panel, the hole through which the solar port cable is looped through was moved lower down towards the base. 

<p align="center">
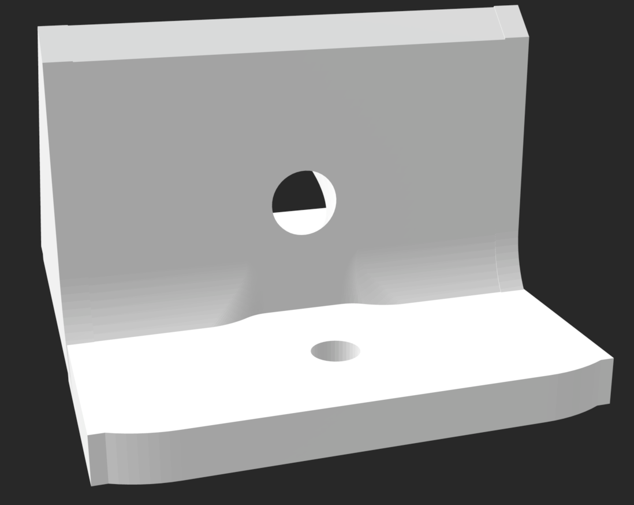
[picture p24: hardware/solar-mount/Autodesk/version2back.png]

</p>

In doing so, while there was less strain present directly behind the solar panel new strain was introduced elsewhere. Specifically, between the cable coming out of it's hole towards the base. Moreover, another issue that was becoming increasingly prevalent out in the field was how the cable coming out over the base of the mount often obstructed screwing down the base. If special attention wasn't paid to pushing the cable over to the side, it got caught up in the wingnut. 

<p align="center">
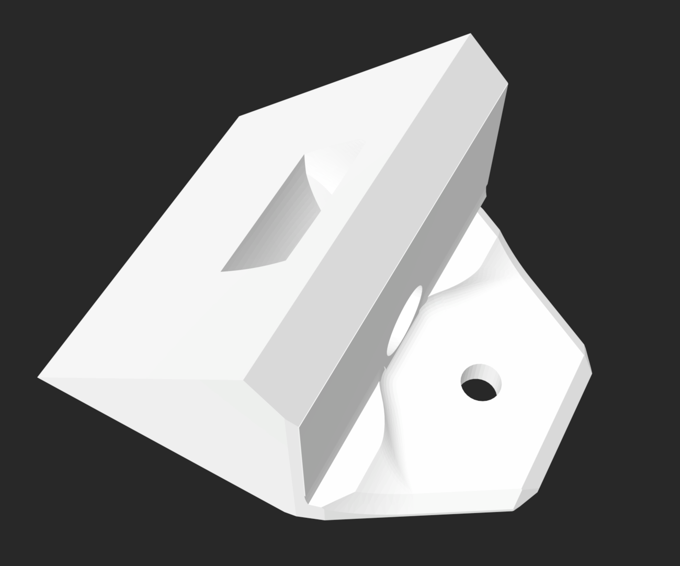
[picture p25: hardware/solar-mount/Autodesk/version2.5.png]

</p>

The solar panel mount was still considerably bulkier than necessary. Attempts to shave down the sides of the base were made using the chamfer function in Fusion360. Despite, making some difference the mount was still too heavy to be practical out in the field.  

# Potential Final Version

<p align="center">
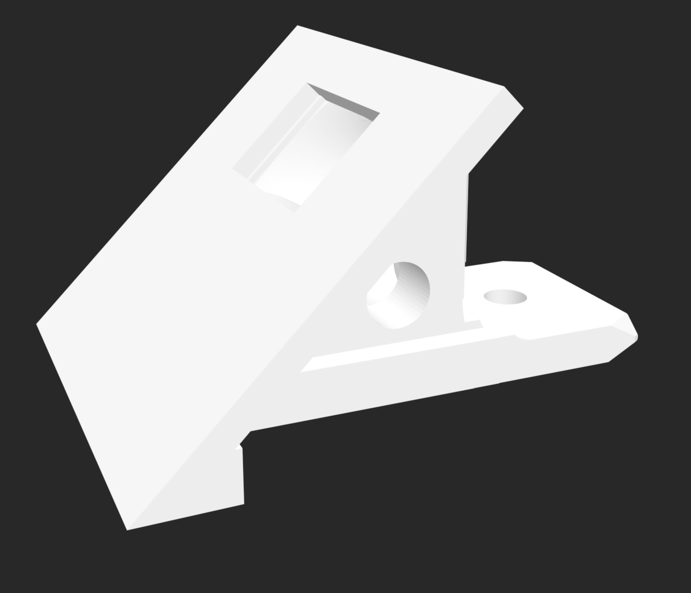
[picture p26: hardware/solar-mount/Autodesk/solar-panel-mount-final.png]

</p>

The potential final design of the solar panel mount takes a slightly different approach in addressing cable tension concerns. Instead of having the solar port cable come out from the back of the mount, it now comes out from the side. This in turn results in an almost 90 degree bend internally before the cable comes out, getting rid of the tension directly on the back of the solar panel. This also rectifies the issue of the solar port cable getting caught up on the wingnut at the base of the mount. 

Most importantly, however, is that the solar panel mount is signifcantly less heavy! Cutting out huge chunks from the sides of the mount leads to a more transportable and manageable design. The sturdiest component of the mount should be the base as that is the part that will undergo the most pressure out in the field. Other parts of the mount do not need to be as robust. 

As of right now, this version of the solar panel mount is undergoing lab testing. Final kinks still need to be worked out such as whether there should be two holes, one on each side for the solar port cable to be looped out from, and what the best orientation for 3D printing is. 

<p align="center">
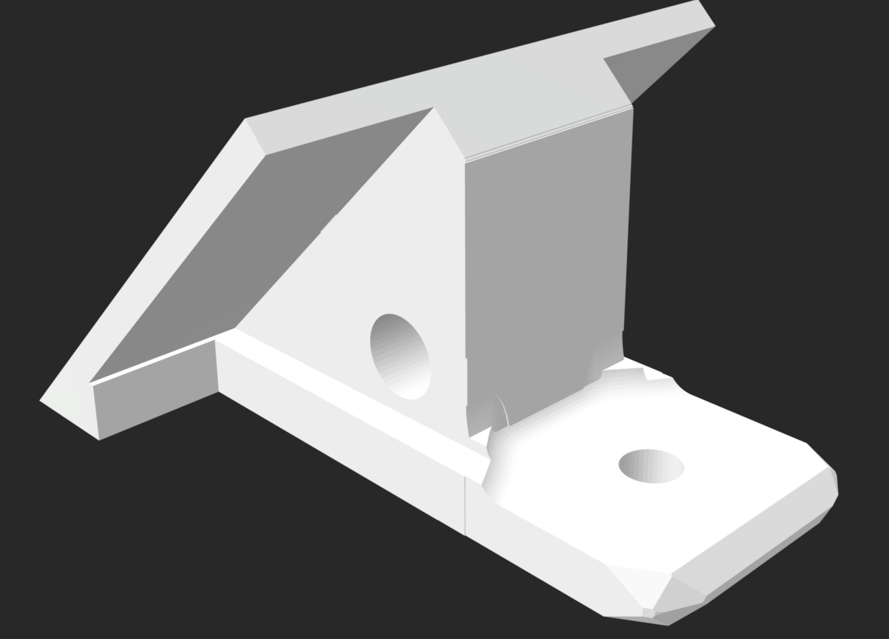
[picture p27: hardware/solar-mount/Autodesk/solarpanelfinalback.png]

</p>

# Final Version Post Testing 

<p align="center">
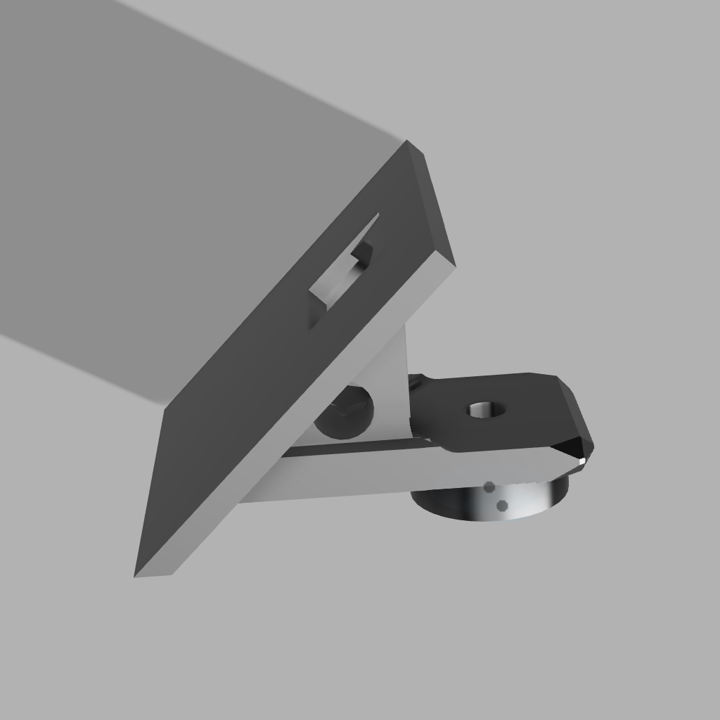
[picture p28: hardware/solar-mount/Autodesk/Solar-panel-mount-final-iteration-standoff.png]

</p>

The final design of the solar panel mount currently being deployed out in the field is shown above. From testing the mount out in the field, one alteration was made. A standoff was added to the bottom of the mount. The new mount is slightly longer to make it easier to drill it down in the field. While there is no longer an angle needed to drill the mount down, the slightly longer design kept getting in the way of the antenna.

As of now the panels are being printed out in batches of 6 on an Ultimaker S5 in the lab with an 80% infill of material PETG. Since Ultimakers aren't designed for bulk printing and are instead meant more for printing prototypes we have found quicker failures of the print core. In order to counter that the Ultimaker cleaning filament should be used to throughly clean out the core in between all print jobs.

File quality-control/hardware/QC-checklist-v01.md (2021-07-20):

| | **Quality Control** | **Comply** | **Comment/Action Taken** |
| --- | :--- | :--- | :--- |
| **1. Electrical Connections** | A. Maxbotix connections | | |
| | B. Solar Charger Board connections | | |
| | C. Battery plugged into the right terminal on the solar charger board | | |
| | D. Solarpanel connected to the Solar Board Charger | | |
| | E. **io1** connected to **pin 6** | | |
| | F. Antenna wire soldered onto the **ANT** pin | | |
| | G. No short-circuits - checked using a Multimeter | | |
| | H. SD Card inserted correctly | | |
| | I. Coin-cell battery inserted into the Feather Wing | | |
| **2. Connections Quality Control** | A. No exposed copper on the wires | | |
| | B. No loose connections | | |
| | C. No wrong connections | | |
| | D. All wire joints are heat-shrinked | | |
| | E. No melted wires | | |
| | F. No Cold Joints | | |
| | G. No excess solder | | |
| | H. No Insufficient wetting pads | | |
| | I. No distribuited solder joints/ Solder bridges | | |
| | J. Rigid and Good Quality Solar Panel connection | | |
| | J. Waterproofed Solar Panel connection | | |
| **3. Sensor Rigidity** | A. MCU firmly mounted onto the connector board | | |
| | B. Connector board mounted onto the perforated plastic panel of the housing using Headers and screws | | |
| | C. Ultrasonic Sensor firmly secured using the lock nut | | |
| | D. Solar Panel cable firmly secured using the PG Cable gland | | |
| | E. Solar board charger mounted/firmly secured using industrial tape | | |
| | F. Enough room for battery | | |
| | G. Solar Panel | | |
| **4. Sensor Operation** | A. Sensor pushing uplinks to **correct** The Things Network application | | |
| | B. First uplink is the CFG packet | | |
| | C. Sensor on correct duty cycle | | |
| | D. Correct distance readings | | |
| | E. Correct battery level when ***not*** connected via USB | | |
| **5. Sensor Accuracy** | A. Sensor readings accuracy <= 10 mm at 1 meter - Indoor conditions | | |
| | | | |

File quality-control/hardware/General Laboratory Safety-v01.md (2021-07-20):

## General Laboratory Safety

1. Always use safety goggles while performing drilling or sawing or any other activities where there is a potential danger to the eyes
2. Use care when waterproofing electrical components using liquid electrical tape. Thoroughly wash hands after use.
3. Use care when handling a solder iron. Never touch the element of soldering iron! Please use a cleaning wet sponge during use. Always put the soldering iron on the stand when not in use and never put it on the workbench. Turn it off and unplug when not in use.
4. Do not use a NiMH/NiCad/lead-acid charger while charging LiPo batteries
5. Always inspect batteries and surrounding circuitry for any damage, loose wiring, or possibility of short circuits

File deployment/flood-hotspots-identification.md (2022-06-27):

# Flood Hotspots Identification
This manual describes the parameters that inform sensor location selection. Once a location is selected, we deploy our sensor through a process described in the [Flood Sensor Deployment Manual](https://github.com/floodnet-nyc/flood-sensor/blob/main/deployment/manuals/flood-sensor-deployment-manual.md).

**Table of Contents:**
- [Flood Hotspots Identificantion](#flood-hotspots-identification)
  - [1. Community Engagement](#1-community-engagement)
    - [1.1. Sensor Suggestion Form](#11-sensor-suggestion-form)
    - [1.2. Stakeholder Relationships](#12-stakeholder-relationships)
    - [1.3. Fair Distribution of Sensors](#13-fair-distribution-of-sensors)
  - [2. Verification of Flooding](#2-verification-of-flooding)
  - [3. Identification of Gateway Location](#3-identification-of-gateway-location)
    - [3.1. Proximity to Existing Gateway](#31-proximity-to-existing-gateway)
    - [3.2. New Gateway Deployment](#32-new-gateway-deployment)
  - [4. Identification of Mounting Infrastructure](#4-identification-of-mounting-infrastructure)
    - [4.1. Acceptable DOT Infrastructure](#41-acceptable-dot-infrastructure)
    - [4.2. Ideal Sign Post Location](#42-ideal-sign-post-location)

## 1. Community Engagement
We want to make sure that those who are most impacted by severe flooding have a say in determining where sensors will be mounted.
### 1.1. Sensor Suggestion Form
This [Google Form](https://forms.gle/4kJpujo9pDt7hZmRA) allows NYC residents to suggest locations for deployment.
### 1.2. Stakeholder Relationships
We are partnered with NY Sea Grant and the Science and Resilience Institute of Jamaica Bay; these organizations, along with the NYC Mayor’s Office of Climate Resiliency and other partners, co-founded a [Community Flood Watch Project](https://www.srijb.org/jbfloodwatch/) that has helped to inform our outreach. We are continuing to seek out partnerships with other community organizations that can inform our hotspot identification process.
### 1.3. Fair Distribution of Sensors
The Mayor’s Office of Climate and Resiliency has also provided us with a list of flood-prone neighborhoods, to help us ensure that we are distributing our sensors throughout all five boroughs.

## 2. Verification of Flooding
Once a location is proposed, we consult the [NYC Stormwater Flood Maps](https://experience.arcgis.com/experience/4b290961cac34643a49b9002f165fad8/) to confirm that this location is likely to be impacted by flooding in a Moderate Stormwater Event. 

<p align="center">
  
</p>
<p align="center">
  An example of an area prone to deep and contiguous flooding, where a sensor has been deployed.
</p>

## 3. Identification of Gateway Location
Once we have a potential sensor location, we need to ensure that it is proximate to a LoRaWAN gateway.
### 3.1. Proximity to Existing Gateway
In this [Sensor Locations Planner](https://www.google.com/maps/d/edit?mid=1njszfj9XP9E2616GYRWTTzQ7gLllMuxZ&usp=sharing), we have mapped out existing locations of gateways that we have installed, or that are visible on this [TTN Mapper](https://ttnmapper.org/heatmap/).
### 3.2. New Gateway Deployment
If our potential sensor location is not close enough to one of these gateways, it will slow down the process a bit. In order to mount, we will have to seek out a location where we can mount a gateway. Typically, we can identify these locations by building relationships with organizations in the area. Our [Google Form](https://forms.gle/4kJpujo9pDt7hZmRA) provides an opportunity for community members to identify potential gateway sites. We mount gateways according to this [Floodnet Gateway setup](https://github.com/floodnet-nyc/floodnet-gateway) guide.

## 4. Identification of Mounting Infrastructure
After confirming that a location is flood-prone and proximate to a gateway, we need to determine where we will mount the sensors.
### 4.1. Acceptable DOT Infrastructure
Our sensors are designed to be mounted on U-Channel sign posts. We have permission from DOT to mount sensors on these poles, provided that we notify DOT whenever we install a new sensor. We have been instructed to avoid mounting on stop signs when possible
### 4.2. Ideal Sign Post Location
We use the street view feature in Google Maps to locate sign posts in the region we have chosen, and cross-reference these locations with the [NYC Stormwater Flood Maps](https://experience.arcgis.com/experience/4b290961cac34643a49b9002f165fad8/) to verify that the specific mounting location we have chosen is flood-prone. If there are tall buildings on the south side of the street, we try to select mounting locations on the north side. This ensures that our sensors will have plenty of sun exposure. It is also important to reconsider the proximity to the nearest gateway and ensure that the signpost is within a distance of about a mile or less. Once these conditions are satisfied, we compile street view and map images in a Google Sheet, which our technical team can reference in the field. Alongwith these images the Google sheet also includes the intersection where the sign post is located, a Google maps link to the location, the latitudinal and longitudinal coordinates of the sign post, the location of the closest gateway and the distance to it, and the flooding profile of the area. In addition, this sheet could also include details of more than one potential sign post that satisfies the above conditions in an area. Multiple sign post locations are identified in an area in case of unforeseen conditions in the field.

<p align = "center">
hoyt 5th
126th 7th

</p>
<p align = "center">
Deployed sensors on ideal sign post locations
</p>

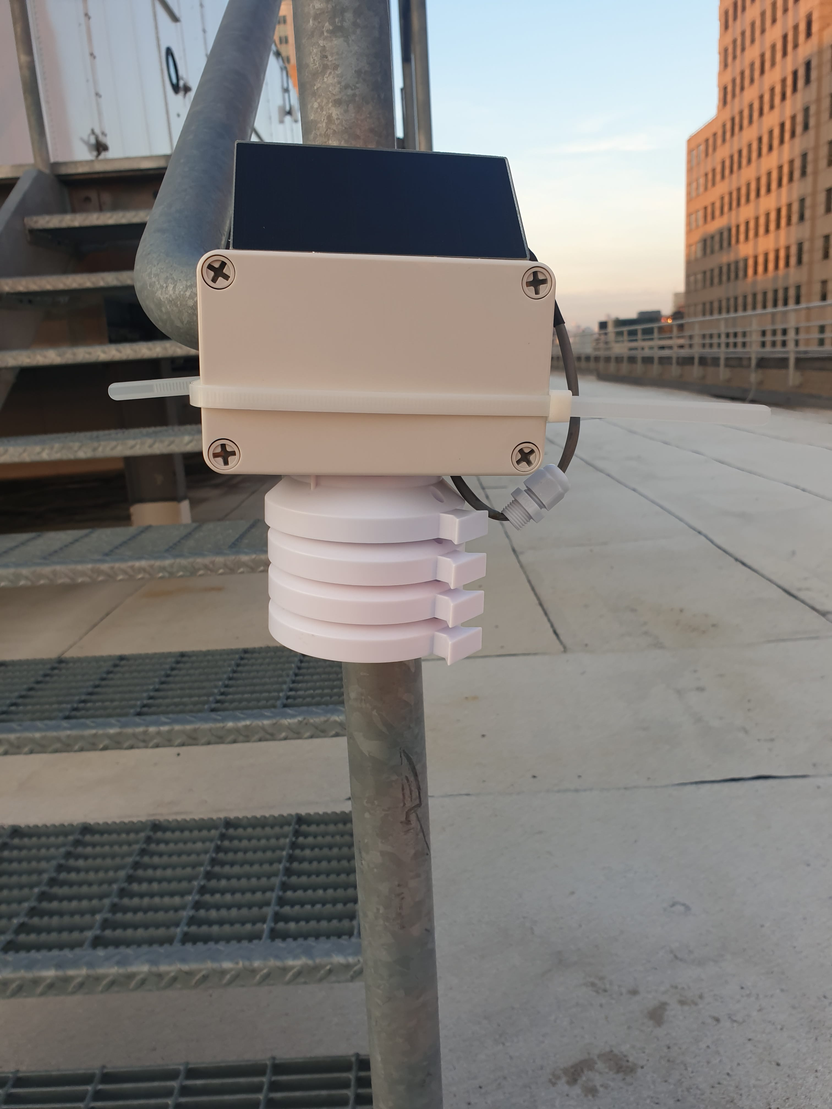
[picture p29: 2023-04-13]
img/solar-shield-design.jpg

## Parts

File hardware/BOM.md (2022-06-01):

|Item |Qty per sensor|Cost of each unit|Cost per sensor|
|---|---|---|---|
|[Heltec AB02](https://heltec.org/project/htcc-ab02/) |1|$14.40|$14.40| 
|[0.6W solar panel](https://voltaicsystems.com/0-6-watt-6-volt-solar-panel-etfe/)|1|$9.00|$9.00| 
|[0.6W panel gasket](https://voltaicsystems.com/gasket-0-6w/) |1|$1.50|$1.50| 
|[3D printer filament](https://www.amazon.com/Polymaker-Filament-1-75mm-Resistant-Cardboard/dp/B09DKP1TYK/)|1 |$2.75|$2.75|
|[Cable glands - PG7](https://www.amazon.com/mxuteuk-Connectors-Protectors-Waterproof-Adjustable/dp/B083K5PKYB/)|1|$0.45|$0.45|
|[uFl to SMA female](https://www.amazon.com/onelinkmore-Connector-Pigtail-Bulkhead-Extension/dp/B01AJQ33Y4/)|1|$6.28|$6.28|
|[Sign](https://www.bradyid.com/label-printers/laminators/rigid-sign-blanks-cps-2855744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)|1|$4.79|$4.79|
|[JST 1.25mm cables](https://www.digikey.com/en/products/detail/adafruit-industries-llc/3922/9685337)|1|$0.95|$0.95|
|[Switch](https://www.digikey.com/en/products/detail/c-k/OS102011MS2QN1/411602)|1|$0.51|$0.51|
|[Antenna](https://www.digikey.com/en/products/detail/linx-technologies-inc/ANT-916-CW-HWR-SMA/1139580)|1|$12.85|$12.85|
|[Maxbotix US range sensor](https://www.digikey.com/en/products/detail/maxbotix-inc/MB7389-100/7896781)|1|$99.95|$99.95|
|[US locknut with washers](https://www.digikey.com/en/products/detail/maxbotix-inc/MB7950-000/10279125)|1|$3.00|$3.00|
|[Screw terminals](https://www.digikey.com/en/products/detail/phoenix-contact/1984617/950849)|4|$0.55|$2.20|
|[MCU header](https://www.digikey.com/en/products/detail/sullins-connector-solutions/PPTC081LFBN-RC/810147)|2|$0.65|$1.30
|[JST socket for battery](https://www.digikey.com/en/products/detail/te-connectivity-amp-connectors/440055-2/2077946)|1|$0.20|$0.20|
|[Struct Channel - 1ft](https://www.mcmaster.com/3230T26/)|1|$9.57|$9.57|
|[Struct Channel nuts](https://www.mcmaster.com/3259T33/ )|3|$1.61|$4.82| 
|[Right angled mounting bracket](https://www.mcmaster.com/33125T33/)|1|$6.73|$6.73|
|[M6 - Socket Hex cap screws](https://www.mcmaster.com/91274A143/ )|2|$0.19|$0.37|
|[Oversized washers - 1/4"](https://www.mcmaster.com/91525A120/)|2|$0.32|$0.64| 
|[Hex screw nuts 1/4"-20](https://www.mcmaster.com/91819A110/)|2|$0.06|$0.13| 
|[Hex Head Screw 1/4"-20](https://www.mcmaster.com/92620A546/)|2|$0.35|$0.70| 
|[Oversized Clipped Washers](https://www.mcmaster.com/93409A136/)|2|$1.59|$3.19| 
|[Battery (400mAh)](https://www.mouser.com/ProductDetail/Adafruit/3898?qs=byeeYqUIh0NUfilp6w7tLA%3D%3D)|1|$6.95|$6.95|
|[Housing 2.63 x 2.63 x 1.63 in](https://www.polycase.com/ml-22f)|1|$10.64|$10.64|
|PCB fabricated (custom printed)|1|$0.50|$0.50|

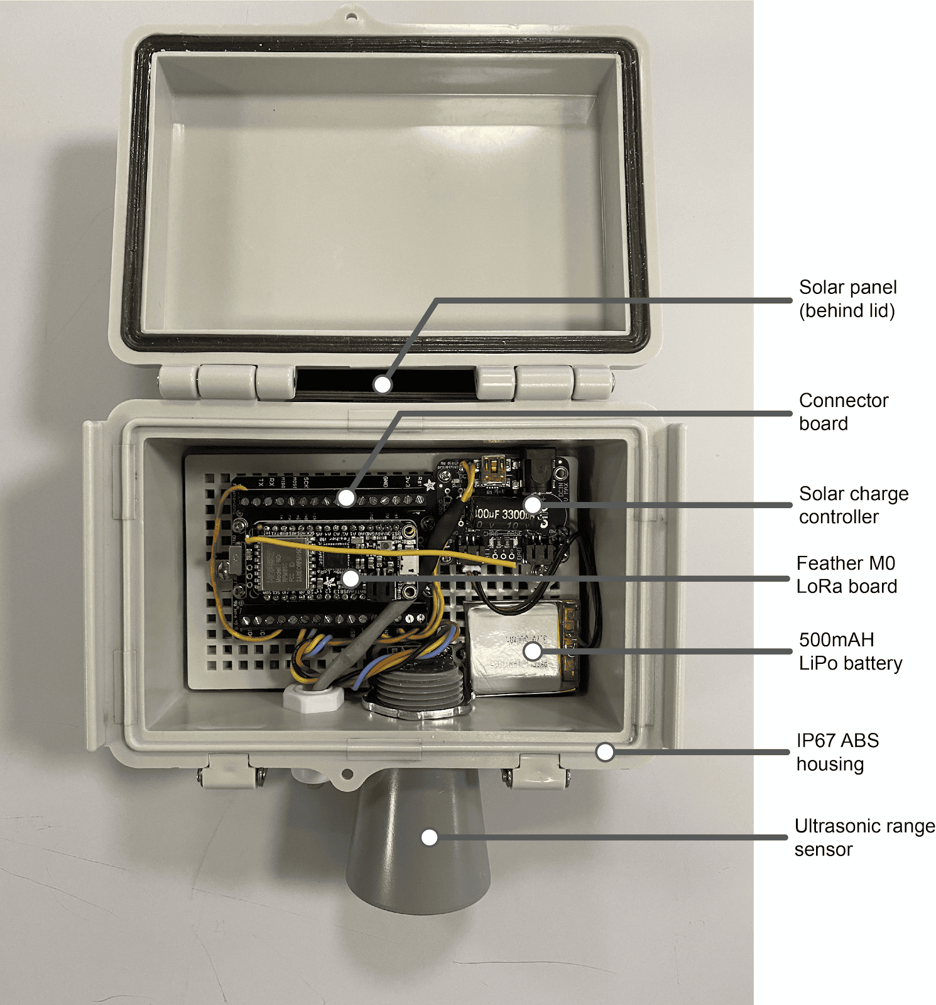
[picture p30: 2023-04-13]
img/components.png

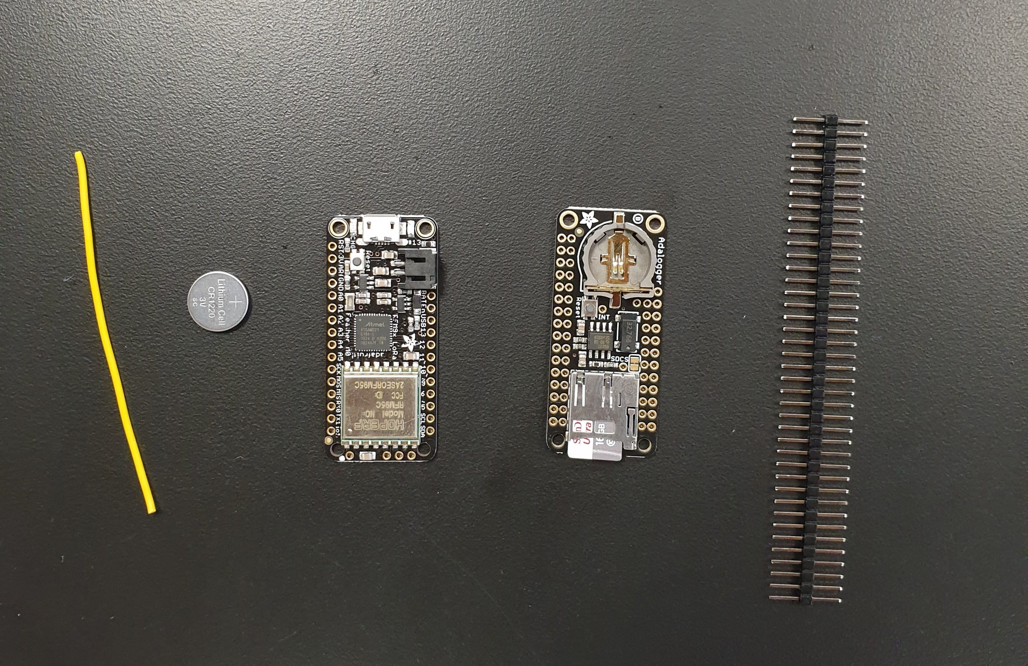
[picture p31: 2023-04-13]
img/mcu-components-2.jpg

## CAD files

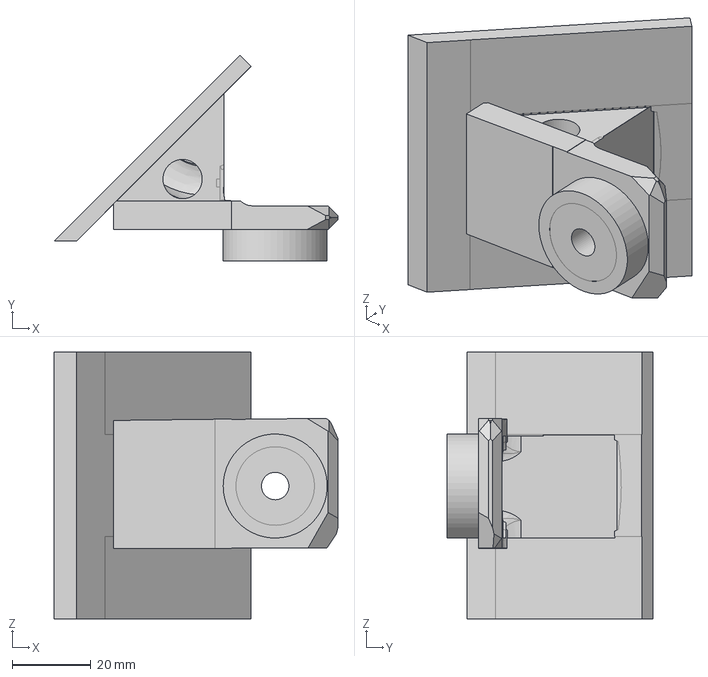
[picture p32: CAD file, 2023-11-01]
hardware/solar-mount/Autodesk/Solar-panel-mount-final-iteration-standoff.step
72.4 x 52.4 x 68.0 mm

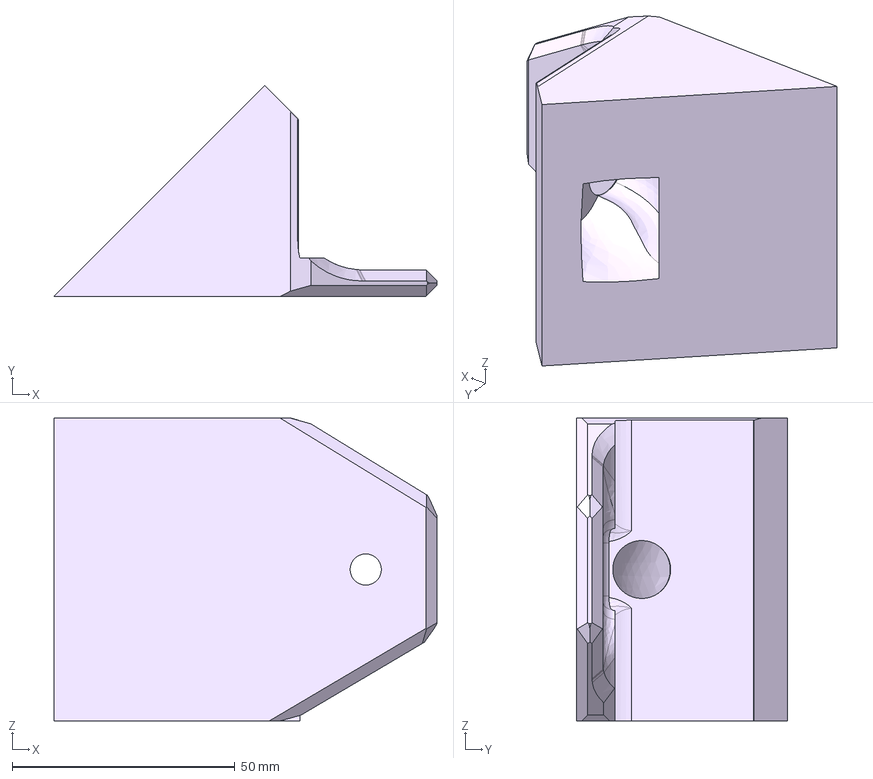
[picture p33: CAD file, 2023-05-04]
hardware/solar-mount/Autodesk/solar-panel-mount-v2.5.step
86.0 x 47.4 x 68.0 mm

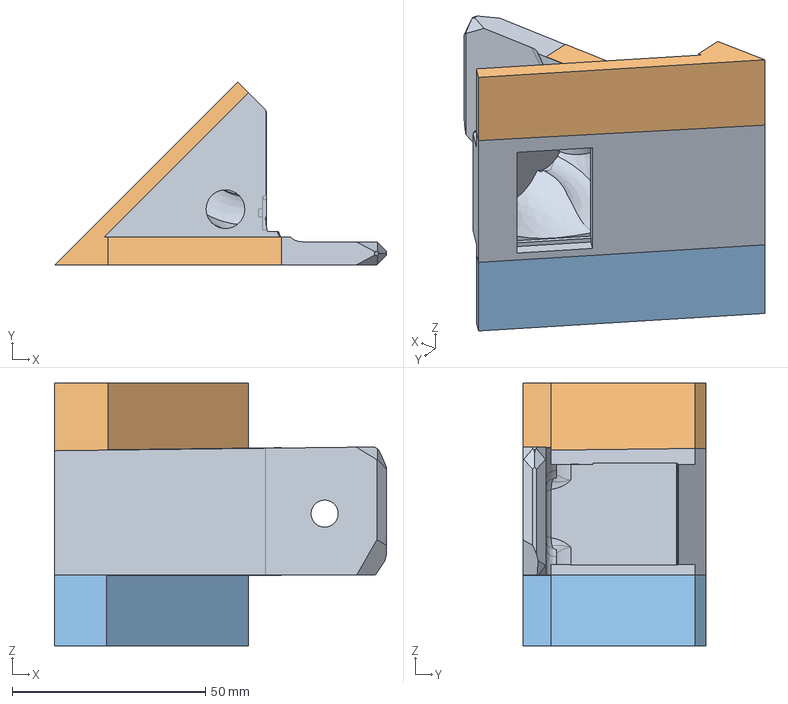
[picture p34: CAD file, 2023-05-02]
hardware/solar-mount/Autodesk/solar-panel-mount-final.step
85.9 x 47.4 x 68.0 mm

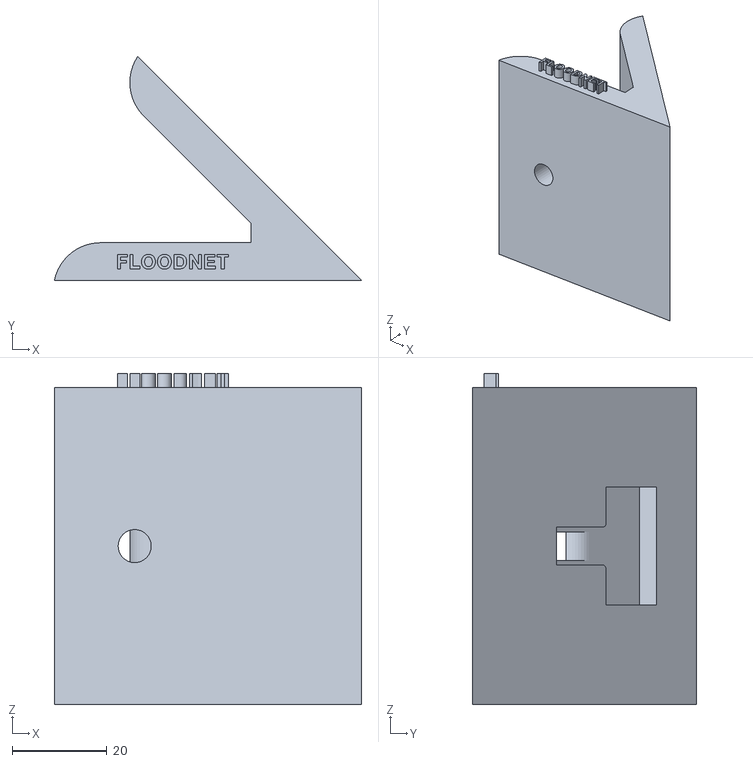
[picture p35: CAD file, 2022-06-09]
hardware/solar-mount/Autodesk/SolarPanelMount.stl
65.0 x 47.4 x 70.0

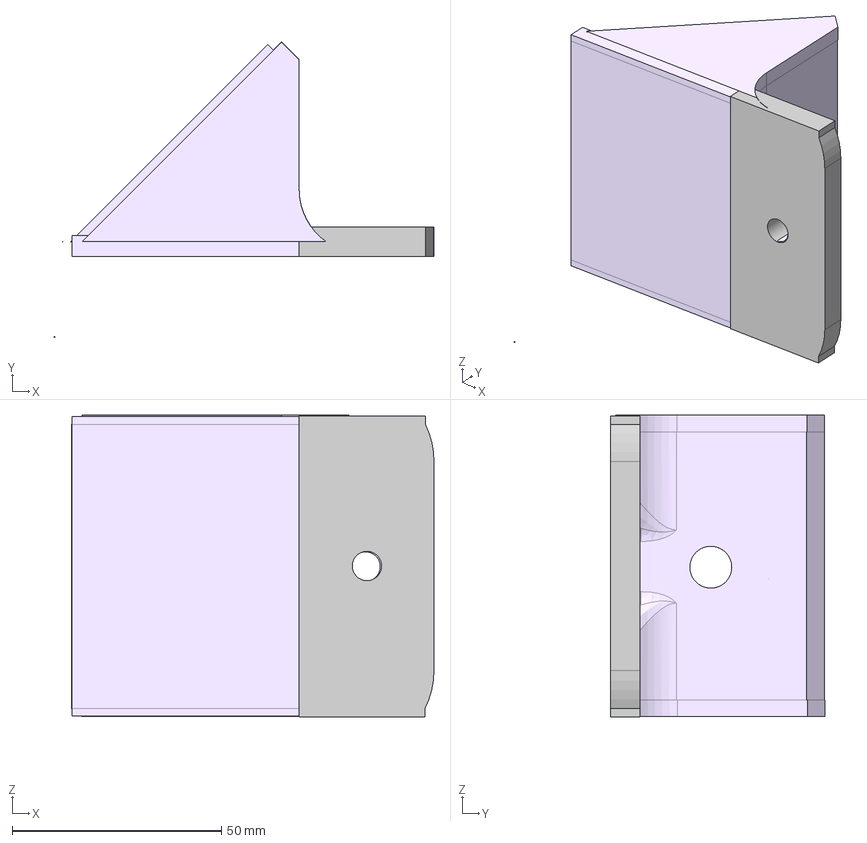
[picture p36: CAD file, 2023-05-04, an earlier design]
hardware/solar-mount/Autodesk/solar-panel-mount-v2.step
90.7 x 70.5 x 88.2 mm

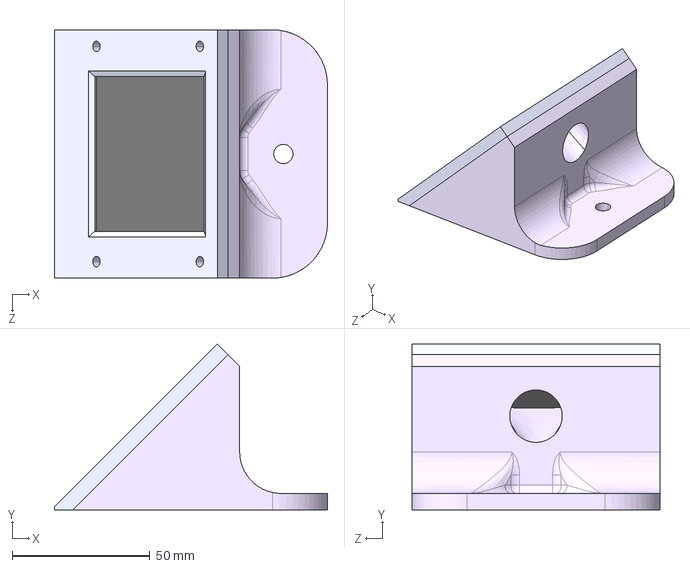
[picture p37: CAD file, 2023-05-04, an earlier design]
hardware/solar-mount/Autodesk/solar-panel-mount-v1.STEP
98.9 x 60.1 x 90.0 mm

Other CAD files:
hardware/solar-mount/Autodesk/Solar-panel-mount-final-iteration-standoff.f3d
hardware/solar-mount/Autodesk/Solar-panel-mount-final-iteration-standoff.stl
hardware/solar-mount/Autodesk/SolarPanelMount.f3d
hardware/solar-mount/Autodesk/solar-panel-mount-final.f3d
hardware/solar-mount/Autodesk/solar-panel-mount-final.stl
hardware/solar-mount/Autodesk/solar-panel-mount-v1.STL
hardware/solar-mount/Autodesk/solar-panel-mount-v2.5.f3d
hardware/solar-mount/Autodesk/solar-panel-mount-v2.5.stl
hardware/solar-mount/Autodesk/solar-panel-mount-v2.f3d
hardware/solar-mount/Autodesk/solar-panel-mount-v2.stl

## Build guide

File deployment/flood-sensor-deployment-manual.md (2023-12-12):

# Flood Sensor Deployment Manual
Once the sensor deployment location is identified, this manual explains the next steps to deploy a [FloodNet](https://www.floodnet.nyc) flood sensor. This is the second stage in deploying a flood sensor, and the first is detailed in the [Flood Hotspots Identification](https://github.com/floodnet-nyc/flood-sensor/blob/main/deployment/hotspot%20identification/flood-hotspots-identification.md) document.

**Table of Contents:**
- [Flood Sensor Deployment Manual](#flood-sensor-deployment-manual)
  - [1. Things to do - Before leaving the lab](#1-things-to-do---before-leaving-the-lab)
    - [1.1. Checklist](#11-checklist)
    - [1.2. Notes on Sensor mount preparation](#12-notes-on-sensor-mount-preparation)
    - [1.3. Registering sensor on TTN Application](#13-registering-sensor-on-ttn-application)
    - [1.4. Acquiring FloodNet approval](#14-acquiring-floodnet-approval)
    - [1.5. Acquiring Approval for Mounting Location](#15-acquiring-approval-for-mounting-location)
  - [2. Confirming Mounting Location on the Ground](#2-confirming-mounting-location-on-the-ground)
  - [3. Sensor Installation Process](#3-sensor-installation-process)
    - [3.1. Accessing the infrastructure](#31-accessing-the-infrastructure)
    - [3.2. Mount installation](#32-mount-installation)
    - [3.3. Solar Panel installation](#33-solar-panel-installation)
    - [3.4. Levelling](#34-levelling)
  - [4. Joining the FloodNet network](#4-joining-the-floodnet-network)
  - [5. Start Sensing](#5-start-sensing)
  - [6. Signage](#6-signage)
  - [7. Photo](#7-photo)
  - [8. Next Steps](#8-next-steps)
    - [8.1 Sensor Locations Logged in Database](#81-sensor-locations-logged-in-database)

## 1. Things to do - Before leaving the lab
This section details how we prepare for sensor deployment. Steps include compiling tools, preparing mounting equipment, and adding the sensor to the TTN app. 
### 1.1. Checklist
This section contains the checklist for necessary tools, hardware, and equipment needed for the sensor deployment process.
| No | Item | Count/sensor |
|----|---|---|
| 1  | [High leverage combination pliers](https://www.knipex.com/products/combination-and-multifunctional-pliers/high-leverage-combination-pliers/high-leverage-combination-pliers/0205200) | 1 |
| 2  | [Adjustable wrench](https://www.kleintools.com/catalog/adjustable-wrenches/adjustable-wrench-standard-capacity-18-inch) | 1 |
| 3  | [Phillips #2 screwdriver](https://www.kleintools.com/catalog/screwdrivers/2-phillips-screwdriver-4-round-shank) | 1 |
|  4  | [Oversized Clipped Washers](https://www.mcmaster.com/93409A136/) | 4 |
|  5  | [Green Powder-Coated Steel Strut Channel with Mounting Plate]() | 1 |
|  6  | [Stainless Steel Hex Head Screw - 7/16"-14 thread size](https://www.mcmaster.com/92800A393/) | 4 |
|  7  |  [Locknuts - 7/16"-14 thread size](https://www.mcmaster.com/90630A112/) | 4 |
|  8  | Ratchet Wrench - 7/16", 1/2", 9/16" and 13mm |1|
|  9  | Wire cutter |1|
| 10  | Plier |1|
| 11  | Zipties |5|
| 12  | Sockets - 12mm, 13mm and 14mm |1 |
| 13  | Power Drill |  1|
| 14  | Steel Straps and strapping tool |1|
| 15  | Circuler Bubble Level |  1 |
| 16  | 3" Hex head M8 bolts and 3" Hex head M6 bolts | 2+2 |
| 17  | M8 Lock nut and Lock washer | 4 |
| 18  | M6 Lock nut and Lock washer | 4 |
| 19  | 1.5" Hex head M8 bolts and 1.5" Hex head M6 bolts | 2+2 |
| 20  | Portable Foldable Ladder that can allow you to reach heights of upto 6 feet |1| 
| 21  | 3" mending plate |1|
### 1.2. Notes on Sensor mount preparation
After we have identified the ideal mounting infrastructure (see [Flood Hotspots Identification](https://github.com/floodnet-nyc/flood-sensor/blob/main/deployment/hotspot%20identification/flood-hotspots-identification.md) document), the next step is to identify the mounting position on the post/pole itself. 

Below are a few examples of different DOT signpost designs found across NYC, explaining optimal sensor placement scenarios.

*<insert_image_signpost_with_parking_sign>*

*<insert_image_signpost_with_stop_sign>*

*<insert_images_other_types>*

### 1.3. Registering sensor on TTN Application
Register the sensor on TTN by following these [steps.](https://github.com/floodnet-nyc/flood-sensor/tree/main/firmware)
### 1.4. Acquiring FloodNet approval
Sensor locations confirmed in weekly meeting prior to deployment

### 1.5. Acquiring Approval for Mounting Location
We have blanket approval from DOT to mount sensors on drive rails, also known as U-Channel posts. Each month, we update them on where new sensors have been installed. We have to obtain special approval to mount on other types of DOT infrastructure.

To mount on a utility pole, we have to obtain approval from the company that owns that pole. This process varies depending on the company.

## 2. Confirming Mounting Location on the Ground
Though we try to identify optimal sensor placement [before leaving the lab](https://github.com/floodnet-nyc/flood-sensor/blob/main/deployment/hotspot%20identification/flood-hotspots-identification.md), unexpected obstacles can arise once we arrive at the mounting site.
All the potential locations according to there priority is scouted and saved in the [FN Field Map](https://www.google.com/maps/d/u/1/edit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)
Potential obstacles include:
- Drive rail is slanted, or is not well secured. 
- Mounting location is overly shaded by a large building or aboveground train track or trees.
- Mounting location is in the path of a truck or bus, and sensor mounting arm would have to point into the street.
- Mounting location is on grass.

Sometimes, a new mounting location will have to be selected in the field. Helpful clues for selecting a flood-prone location include:
- Drive rail is close to a storm drain
- Street near drive rail is muddy and/or marked by the accumulation of trash
- Drive rail is located on the north side of the street, or has good sunlight exposure
- Drive rail is tall enough for sensor to be out of reach

## 3. Sensor Installation Process
To ensure the optimal sensor placement, we need to complete the following steps:

### 3.1. Accessing the infrastructure
- Finalize the location for sensor placement: Carefully select the ideal spots to position the sensors throughout the area.
- Securely position the ladder: Place the ladder on the ground firmly and securely to ensure stability while accessing higher areas for sensor installation.
- Determine the sensor height: Assess the appropriate height at which the sensors should be placed. Generally, a range of 2-3 meters is suitable for optimal data collection and accuracy.
- Mind the street signs: Take into consideration the street signs in the vicinity. Avoid obstructing them during sensor placement. If necessary, temporarily remove the signs to achieve the perfect sensor positioning, ensuring they are securely reinstated once the sensors are installed. *<insert_image>* 

### 3.2. Mount installation 
To ensure proper installation of the sensor mount, follow the appropriate method based on the specific conditions and types of U-posts, drive rails, and sign posts. There are three types of installation methods outlined below:

- **1. Mounting the sensor on the front side of the post:**<br>
 To mount the sensor on the front side of the post, follow these steps for a secure installation:
  - **Position the L plate on the post:** Take the L plate that is attached to the mount and carefully place it on the front side of the post, ensuring it is positioned at the desired height.
  - **Secure the sensor mount:** Using two M8 1.5" bolts, along with two M8 locknuts and four Oversized Clipped Washers, fasten the sensor mount firmly onto the U-post. Make sure the bolts are tightened securely to ensure stability.<br>

By properly positioning the L plate on the front side of the post and using the specified bolts, locknuts, and Oversized Clipped Washers to secure the sensor mount, you can achieve a robust and reliable installation for the sensor on the U-post. (Refer to the provided image for visual reference.)
  
  <br>
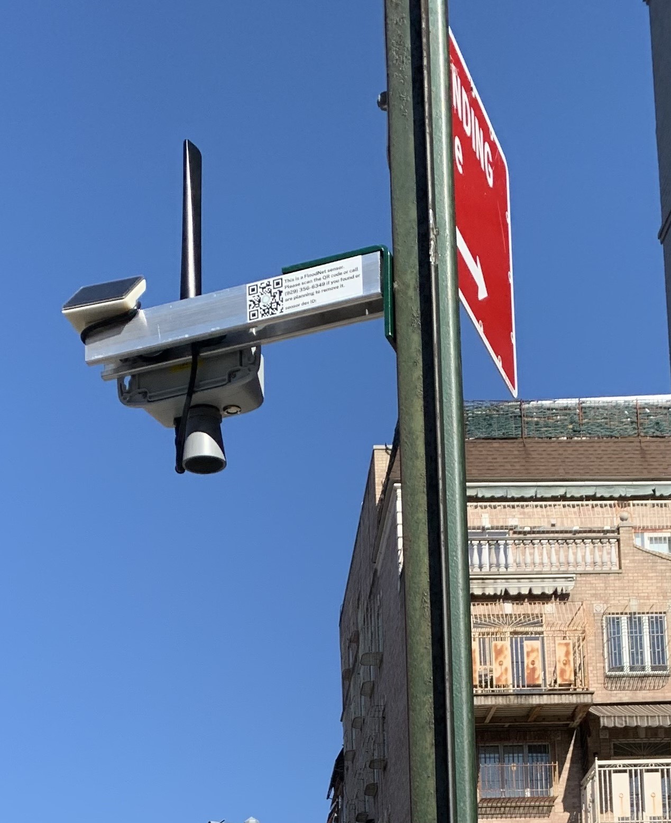
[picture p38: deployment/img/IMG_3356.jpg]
  
  <br>

- **2. Mounting the sensor on the back side of the post:**<br>
  To mount the sensor on the back side of the post, follow these steps for a secure installation:
   - **Position the L plate with a mending plate:** Take the L plate attached to the mount and place it on the back side of the post. Ensure that a mending plate is inserted between the L plate and the post. This additional plate provides reinforcement and stability.
   -  **Secure the sensor mount:** Use two M8 3" bolts, along with two M8 locknuts and four Oversized Clipped Washers, to firmly attach the sensor mount to the U-post. Fasten the bolts tightly to ensure a secure and stable mounting.<br>

By positioning the L plate with the mending plate on the back side of the post and using the specified M8 bolts, locknuts, and Oversized Clipped Washers, you can achieve a reliable and sturdy installation for the sensor on the U-post. (Refer to the provided image for visual reference.)
  
  <br>
  <img src="img/mounted-back-slotted-plate.png" "width="250" height="600">
  <br>

- **3. Mounting the sensor on the post with an obstacle such as a stop sign, parking sign, or do not enter sign:**<br>
  To mount the sensor on a post with an obstacle like a stop sign, parking sign, or do not enter sign, follow these steps for a successful installation:
  
  - **Prepare the area:** Begin by unbolting the sign from the bottom, allowing it to be rotated or temporarily moved to create sufficient space for installing the mount.
  - **Install the sensor mount:** Once the obstacle has been moved or rotated, proceed with the steps mentioned earlier to securely mount the sensor on the U-post. This involves using the appropriate mounting hardware and following the provided instructions.<br>

By carefully unbolting and repositioning the sign to create the necessary clearance, you can then proceed with the regular steps for mounting the sensor on the U-post. (Refer to the provided image for visual reference.)
  
  <br>
  <img src="img/Behind the signs.jpg" "width="300" height="500">
  <br>
  
- **4. Mounting on a direction or signage round pole:**<br>
To ensure secure placement of the sensor, we will employ steel straps and a strapping tool. Follow these steps for a successful installation:
  - **Determine the strap length:** Estimate the required length of the straps, ensuring they are long enough to securely fasten the sensor. Cut two pieces from the steel strap roll, matching the estimated length.
  - **Position the L plate on the round pole:** Attach the L plate to the mount and place it on the round pole at the desired location for sensor installation.
  - **Begin strapping the first strap:** Using the strapping tool, start securing the first strap around the round pole and the L plate. Apply tension to the strap using the tool and ensure it is tightly fastened.
  - **Repeat the process for the second strap:** Once the first strap is securely tightened, repeat the same procedure for the second strap. Apply tension to the strap using the strapping tool, ensuring a firm and stable attachment.<br>

By utilizing the steel straps and strapping tool, cutting the appropriate length of straps, and securely fastening the sensor to the round pole using the L plate, you can achieve a reliable and secure placement of the sensor.(Refer to the provided image for visual reference.)

  <br>
  <img src="img/Sensor on Round pole.jpeg" "width="280" height="500" >
  <br>

By carefully following these guidelines, you can ensure the proper and secure installation of the sensor mount, tailored to the specific conditions and post types involved.
### 3.3. Solar Panel installation
To maximize solar power harvesting, the solar panel should be south-facing and exposed to direct sunlight. This factors into location selection, as discussed in the [Flood Hotspots Identification](https://github.com/floodnet-nyc/flood-sensor/blob/main/deployment/hotspot%20identification/flood-hotspots-identification.md) document, but we also have to adjust the panel orientation as we are installing the sensor itself.
It is essential to ensure that the wing nut is securely tightened after making any adjustments.

### 3.4. Levelling
Though we try to avoid mounting on overly slanted drive rails, a bit of slant is almost unavoidable. Once the sensor is partially secured to the drive rail, we use a level to determine how the pitch of the drive rail is impacting the angle of the mounting infrastructure. We use washers, zip ties, or other spacers to adjust the angle at which the sensor is mounted to the drive rail.

*<insert_image_sensor_angle_adjusted_with_spacers>*
Furthermore, achieving parallel alignment of the sensor with the ground is crucial. To accomplish this, follow these steps:
- Place the circular bubble level at the bottom of the cone and observe the reading.
- Next, position the level on the ground directly beneath the sensor and take a reading. The bubble in the level should be in the opposite direction, indicating that the sensor is parallel to the ground. If not then adjust the mount little bit. *<insert the image*>

## 4. Joining the FloodNet network
Once the installation is complete, it is important to perform a final check to ensure the proper functioning of the sensor. Follow these steps:
- Verify the antenna tightness: Double-check that the antenna is securely tightened in place. This will help optimize the signal reception and transmission.
- Switch on the sensor: Power on the sensor, and you should observe a green light illuminating. This indicates that the sensor is receiving power and is operational.
- Establish connection to the gateway: Wait for a moment as the sensor establishes a connection with the gateway. The green light will turn off once the sensor successfully connects.
 
## 5. Start Sensing
Access data on The Things Network: With the sensor connected, the collected data will become visible on The Things Network platform. You can now monitor and analyze the data transmitted by the sensor.

## 6. Signage
When mounting signage on a drive rail, please follow these steps:
- Determine the appropriate height: Position the sign at a suitable height that allows accessibility for individuals sitting in a wheelchair. This ensures inclusivity and ease of access.
- Secure the sign to the drive rail: Utilize two 1.5" M6 bolts, along with two M8 lock washers and two M6 lock nuts, to firmly fasten the sign onto the drive rail. This ensures a secure attachment.
<br>
<img src="img/IMG_33191.jpg" "width="250" height="500" >
<br>

When mounting signage on a round pole:

## 7. Photo
Photos of sensor installed on location (for records and use in FieldKit dashboard). Photo should include surrounding area (from approx. 10 feet away).

## 8. Next Steps
After a successful installation, follow the below steps to complete the sensor deployment process:
### 8.1 Sensor Locations Logged in Database
New sensor locations should be recorded into master spreadsheet as well as deployment map

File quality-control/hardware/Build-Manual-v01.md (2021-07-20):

# Sensor Build Manual

The sensor build instructions are listed below in order and shall be followed in the same order to maintain QC pipeline, enable efficient testing, and easier debugging. These steps when followed are aimed to help inspectors/researchers/community members attain a good build-quality.

## A. Initial steps and preparation

### 1. Components check
All the components needed to build a sensor are listed below.

| Component name | Count |
|---|---|
| MCU - Adafruit Feather M0 LoRa | 1 |
| Maxbotix Ultrasonic sensor | 1 |
| Adafruit SD Feather Wing | 1 |
| 3V Lithium cell battery | 1 |
| SD Card | 1 |
| Male Headers Equal Length Long Centered 6.25mm on Both Sides, 15mm in total| 2|
| Connector board | 1 |
| Solid core wire for antenna | 1 (atleast 4 inches) |
| Mounting headers and screws | 4 pairs |
| Solar Charger board | 1 |
| Capacitor - 10V rating | 1 |
| Solar Panel | 1 |
| Lithium ion Battery - 2200mAh  | 1 |
| Alarm Cable | 1 (atleast 2ft) |
| Heat shrinks | na |
| loose wires | na |

### 2. Tools check
The following are lists of tools categorized into must-haves and nice-to-haves.

| Must-haves               |
|--------------------------|
| Solder iron              |
| Solder                   |   
| Drill and step drill bit |   
| Screw driver             |  
| Pliers                   |   

| Nice-to-haves  |
|----------------|
| Heat Gun       |
| Wire strippers |
| Scissors       |
| Razor files    |
| Tweezers       |

## B. MCU preparation

### 1. Setting up the MCU

The microcontroller unit(MCU) is the Adafruit Feather M0 RFM95 LoRa Radio - 900 MHz. Out of the box, the MCU comes with "through holes" or "PTH" or simply referred as pins and with no headers attached. The left and right sides of the MCU has 16 pins and 12 pins respectively. 

Prepare the header pins by cutting the long male headers so that they can accommodate all the pins like shown below.

*Note:* Use Headers that are Long Centered 6.25mm on Both Sides (15mm in total), not the 3.5mm pin headers.

Now mount the MCU ***upsidedown*** onto these stacking header pins and make sure the board sits comfortably without any gap. 

When done correctly, the MCU looks perfectly horizontal to the breadboard from the side like shown below. Note that the MCU is upside down since the SD Feather Wing goes on top of MCU.

#### 1.1 Soldering MCU

Now solder the header pins onto the MCU while following [good soldering practices](https://github.com/floodsense/floodsense_sensor/tree/main/quality-control/hardware/QC-build-quality.md).

The MCU after this step should look like the following figure, where the pins are longer on the top to accommodate the SD Feather wing. Be sure to solder all the pins for a reliable electrical contact. 

#### 1.2 Soldering SD Feather Wing

Now carefully mount the SD feather wing onto these pins as shown in the figure. Just to note, the Feather M0 LoRa board and SD Feather Wing have same number of through holes and there must be no through holes left unmounted/soldered after this step.

Now solder from the top as shown in the figure below.

:warning: Using a multimeter, any potential short circuits must be checked.

Potential short circuits at this step are due to improper soldering, refer to [QC-build-quality](https://github.com/floodsense/floodsense_sensor/tree/main/quality-control/hardware/QC-build-quality.md) document for some examples.

#### 1.3 Installing SD card and Coin cell battery onto SD Feather Wing
After the completion of above steps, carefully insert the coin cell with positive side up into the feather wing as shown in the figure.

Now insert SD card into the SD card slot and must hear a click when safely secured.

#### 1.4 MCU Antenna
The Feather m0 LoRa module ***does not*** come with a built-in antenna and needs one for LoRaWAN communication.

A simple single core standard wire can be used as an antenna when cut down to right lengths according to the desired frequencies in the below table. This project is located in Brooklyn, United States, the frequency used is 915 MHz.

| Frequency | Length (inches) | Length (cm) |
|---|---|---|
| 433 MHz | 6.5 | 16.5 |
| 868 MHz | 3.25 | 8.2 |
| 915 MHz | 3 | 7.8 cm |

Cut the single core wire to 3 inches and strip a mm or two just on one end. Now, tin and solder into the **ANT** pad on the very right hand edge of the Feather like shown below.

#### 1.5 Mounting the MCU
The MCU shall now be mounted onto the terminal block breakout board like shown below.

:white_check_mark: The MCU must be secured and feel tightly held onto the breakout board.

:warning: If the MCU pins do not completely fit into the female headers, excess solder on few pins might cause this issue. To fix it, remove the excess solder and male sure solder on the pins are clean and consistent.

### 2. Installing the latest firmware on the MCU

#### Necessary Software
For simplicity, Arduino IDE has been used in the documentation but other IDEs can also be used. Arduino IDE, can be downloaded from [Arduino's website](https://www.arduino.cc/en/software). The Arduino IDE is used for uploading the firmware to the microcontroller.

#### FloodSense Sensor Library
Download the FloodSense Sensor Library from [here](https://github.com/floodsense/floodsense_sensor) by clicking on the green code button and selecting "Download Zip" option. The downloaded file's name should be similar to `floodsense_sensor-main.zip` or `floodsense_sensor.zip`. Now to install this library on the Arduino IDE follow either of the following methods. 

**Method 1:**

1. Find Arduino libraries folder
2. Clone the FloodSense library folder into the Arduino>libraries

[**Method 2:**](https://www.arduino.cc/en/guide/libraries)
1. In Arduino IDE, go to: Sketch> Include Library> Add .ZIP Library..

2. Select the downloaded FloodSense ZIP folder

#### Additional Libraries
The following libraries are also required to be installed:
1. Arduino-Lmic library: https://github.com/mcci-catena/arduino-lmic
2. SDFat library: https://github.com/Praneethsvch/SdFat
3. Adafruit's sleepydog library: https://github.com/adafruit/Adafruit_SleepyDog
4. Adafruit's RTClib: https://github.com/adafruit/RTClib

**Restart the Arduino IDE** for the library to appear on the installed libraries.

#### Arduino IDE setup

After you have installed the libraries, navigate to the **Preferences** menu. You can access it from the **File** menu in *Windows* or *Linux*, or the **Arduino** menu on *macOS*.

In the pop-up dialogue, add the following URL to the **Additional Boards Manager URLs**. The list of URLs is comma separated, and *you will only have to add each URL once.*

```html
https://adafruit.github.io/arduino-board-index/package_adafruit_index.json
```

After the URL is added, Adafruit's packages will be available in the Board Manager. 

To install the boards with the **Board Manager**, navigate to Tools>Board>Boards Manager...

In the Boards Manager window, choose **Type: All**. 

By typing in the search bar, install the following packages:

- **Arduino SAMD**
- **Adafruit SAMD**

**Restart the Arduino IDE** to ensure that all of the boards are properly installed.

#### Flashing the MCU

**Enter the TTN secret keys** into the file `ttncredentials.h` file that can be found in the path Documents/Arduino/libraries/floodsense_sensor/src

In the Arduino IDE, navigate to File>Examples>Floodsense library and choose basic_sensormodes.

Choose the board **Adafruit Feather M0** by navigating to Tools>Board>Adafruit SAMD>Adafruit Feather M0.

Connect the MCU via micro-usb to your computer. Now, **double press the reset button** on the MCU to enter the **Bootloader Mode**.

On the Arduino IDE, navigate to Sketch>Upload to upload the firmware.

## C. Maxbotix Ultrasonic Sensor Preparation

### 1. Preparing the Maxbotix depth sensor

The GND, VCC, Pin 4 and Pin 5 are used for this application. Now choose 4 wires and prepare them for soldering. Tin all the wires on both sides like shown below

Tinning ensures all the fine wires are held together and making an electrical connection. If the wire is not tinned, the individual fine wires may cause short circuits/wrong connections.

Solder them carefully onto the required pins while following [good soldering practices](https://github.com/floodsense/floodsense_sensor/tree/main/quality-control/hardware/QC-build-quality.md).
Carefully holding the wires together with one hand, twist the wires using the other hand. Check for any loose connections or broken wire ends.

### 2. Drilling a hole in the housing to accommodate Maxbotix depth sensor

To accommodate the Maxbotix sensor, a hole shall be drilled on the bottom side of the housing as shown below, so that the sensor is facing the ground when mounted. This hole is centered on the side where the sensor would be mounted.

Carefully secure the housing before using the drill to prevent it from moving. Please be safe and make use of safety glasses to protect your eyes. 

Use a step drill bit and drill a hole just enough for the Maxbotix sensor's threading on it's top. For the model MB-7389, this threading diameter is 1.17”. A 1 $\frac{1}{4}$" hole should be enough to accommodate the sensor.    

## D. Solar Charger board preparation

### 1. Soldering the Capacitor
The negative pin of the capacitor is indicated by a "-" and/or a colored strip along the can. They might also have a longer positive leg.

Now place the capacitor legs into the corresponding through holes on the solar charger board and make sure there is enough room for it to bend sideways to save space as shown in the figure.

Now solder the capacitor and cut off the excess legs. Make sure these are discarded and not left out inside the sensor as they could short other components.

### 2. Wiring
Tin two wires and solder them onto the pins **B+** and GND as shown below. If the solar charger board is [Adafruit's Universal USB/DC/Solar Lithium Ion/Polymer Charger](https://www.adafruit.com/product/4755), the pins are **LIPO** and **GND** instead.

## E. Solarpanel preparation

### 1. Waterproofing the panel connection
The backside of the solar panel has positive and negative terminals. Use a high quality alarm cable and cut open the ends like shown below.

Strip the edges of the wire and tin them

Now heat shrink both the small wires as shown

Solder them onto the corresponding pins and do not apply heat for too long. This might damage and lift the pad on the solar panel.

Now use a bigger heat shrink to hold the both wires like shown below

Waterproof the electrical contact by using liquid electrical tape. Make sure it covers all around making a good seal.

Let it dry for a few minutes and a good quality seal and connection would like below

The following are the examples of a poor quality seal and connection

### 2. Drilling a hole to accommodate the Solar Panel's cable

The solar panel cable lies in the range of 3-6.5 mm, so drill a hole of diameter **12.6 mm** or simply just enough to thread the **PG-7 cable gland**. 

## F. Wiring

1. Connecting pin io1 to pin 6
2. Mounting the depth sensor
3. Connecting depth sensor to the MCU
4. Connecting Solar board with the Solar Charger board
5. Connecting the battery to the Solar Charger board
6. Connecting Solar Charger board with the MCU

## G. Battery
Plug in the battery into the Batt connector on the solar board charger. Now you should see the MCU powering up and the on board LED turns on after battery plug-in if everything goes right. Else recheck the connections once more.

## H. Final Steps

Double check the following connections and observe the serial monitor data to make sure the sensor is operational and is reading valid distance measurements. 

## I. Troubleshooting

## J. Mounting

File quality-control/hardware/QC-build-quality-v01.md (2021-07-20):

# Build Quality
The following practices shall be followed while building the sensor to ensure a good build quality.

## :white_check_mark: Waterproofing

Wire insulation is quite resistant to water. However, electrical connection is not. Every electrical connection that is outside the sensor housing shall be water proofed.

## :white_check_mark: No Loose Wirings

##### Two or more wires in the same Screw Terminal/ Connection

A common problem faced when making electrical connections is two or more wires held under a single screw terminal. This is an electrical hazard and possibly damages the circuitry. Building this sensor doesn't require two or more wires in a same connection and must be avoided.

##### Exposed Wires

It is quite common mistake to leave the wires exposed. When a wire is exposed too much, the wire has too much exposed copper wire which potentially leads to short circuits.

## :white_check_mark: No Short-circuits

##### Faulty wire insulation

Wire isulation is what protects the wire from being exposed to other wires. When this insulation is damaged due to applying excess heat/ incorrect stripping of the wire, this can lead to short-circuits.

##### Loose Wire Connections

Connections sometimes loosen/break allowing GND(Neutral) and VCC(Positive) wires to touch causing a short-circuit.

##### Faulty wiring and *Human error*

It is pretty humane to make mistakes, however double checking before making every single connection mitigates the chances of making errors.

## :white_check_mark: Good Soldering practices

### Soldering basics

:warning:_Caution:_ Never touch the tip of the solder iron, or the iron stand!! (often referred to as a cradle)

:heavy_exclamation_mark:_Potential Hazard:_ Leaving the solder iron unattended is a potential hazard: it could burn you or even burn your desk and start a fire. Always dock the solder iron in its stand and turn off after use.

First, plug and turn on the soldering iron to warm up. While the solder is warming up wet the sponge.

Apply a small amount of solder to the tip and then clean the tip using the wet sponge. You should have a shiny clean tip with a layer of molten solder on the tip of your iron.

Solder is a "joint" and to make a good electrical connection make sure that the through holes are clean. Oxidation and dirt can decrease the quality of the joints. Use a little isopropyl alcohol with a tissue/paper towel to clean the board.

Heat the through hole by placing the tip so that it is in contact with both the metal contact and the header pin.

:warning:_Caution:_ Be careful not to apply lot of heat to the board as it can damage the board.

Carefully put the solder on the joint either on the pin or the metal through hole, and it should melt into the through hole making a connection.

A good quality connection looks like the picture below:

### Common soldering problems

The following are some common problems encountered while soldering that makes an electric connection low quality. These shall be identified and rectified through out the sensor's hardware build procedure.

#### :x: Too much solder!
Applying too much solder onto a pin causes excessive buildup that looks like a rounded ball or a raised shape.

#### :x: Not enough solder/ Insufficient wetting (Pad)
Sometimes the solder wets the leads nicely but does not form a good connection with the pad. This can be caused by failing to apply heat to the pad as well as the pin while making the connection.

#### :x: Solder balling / Solder splashes
If not careful, excess solder while soldering

#### :x: Cold joint
Cold joints are the ones where the solder did not melt completely. These joints often are lumpy and look like they are falling off. These type of joints are unreliable over time.

#### :x: Overheated joint
Applying excessive heat at the joint may lift the pad or burn the board.

#### :x: Solder bridge
Excess solder on the pins or bent leads can cause unintended connections like shown below

## :white_check_mark: Good wire connection practices

##### No wire Connections Made With Electrical Tape

Electric tape is an unreliable wire connection method and shall be avoided. Instead soldering and heatshrinking(like shown below) the joint is a much better approach for a good electrical connection.

##### Soldering and Heat-shrinking the joints

All the solder joints shall be covered with heat shrink so that there is no exposed wire. Make sure the solder joint is not too big/sharp so that it cannot damage the heat shrink. The goal of using a heat shrink is used to prevent the exposure of a solder joint. 

##### No melted wires

It is pretty common mistake to over heat the wires while joing two wires using solder. Try not to apply too much heat. Tan them individually before joining. The melted wires can short-circuit and potentially damage the circuitry.

## References

1. Wire connection problems and solutions: https://www.thespruce.com/wire-connection-problems-and-solutions-1152877
2. Good Soldering Practices: https://learn.adafruit.com/adafruit-guide-excellent-soldering?view=all
3. How to Solder: Through-hole Soldering: https://learn.sparkfun.com/tutorials/how-to-solder-through-hole-soldering/all

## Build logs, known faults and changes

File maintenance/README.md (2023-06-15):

- [Maintenance playbook](#maintenance-playbook)
	- Section 0. Common visit reasons checklist **(Pre-visit)**	
	- Section 1. Assessment **(Pre-visit)**
	- Section 2. Planning **(Pre-visit)**
		* 2.1 Planning when the gateway is down?
		* 2.2 Planning for sensors with a down-trending battery profile
		* 2.3 Planning for sensors with a no charging trend profile
		* 2.4 Planning for sensors with wrong readings	
		* 2.5 Planning for sensors with high packet-loss	
		* 2.6 Planning for sensors that have abruptly stopped working	
	- Section 3. Packing necessary equipment and tools **(Pre-visit)**	
	- Section 4. Repair procedures **(On-site)**	
		* 4.1 Repair procedures if the gateway is down	
		* 4.2 Repair procedures for sensors that have abruptly stopped working	
		* 4.3 Repair procedures for sensors with a down-trending battery profile	
		* 4.4 Repair procedures for sensors with a no charging trend profile	
		* 4.5 Repair procedures for sensors with wrong readings
		* 4.6 Repair procedures for sensors with high packet-loss
	- Section 5. Check and validate the sensor operation
	- Section 6. Challenges in the field **(On-site)**
		* 6.1 No coverage/Sensor not joining the network
		* 6.2 Sensor joined the network but I don’t see any data on the dashboard
		* 6.3 Debugging in the field
		* 6.4 Vandalism

# Maintenance playbook

This playbook details the steps for in-person maintanance visits to perform quick, reliable, and quality sensor repairs.

Use the following thinker roadmap to understand the stages broken down into two categories based on the location of action to be taken
<br>
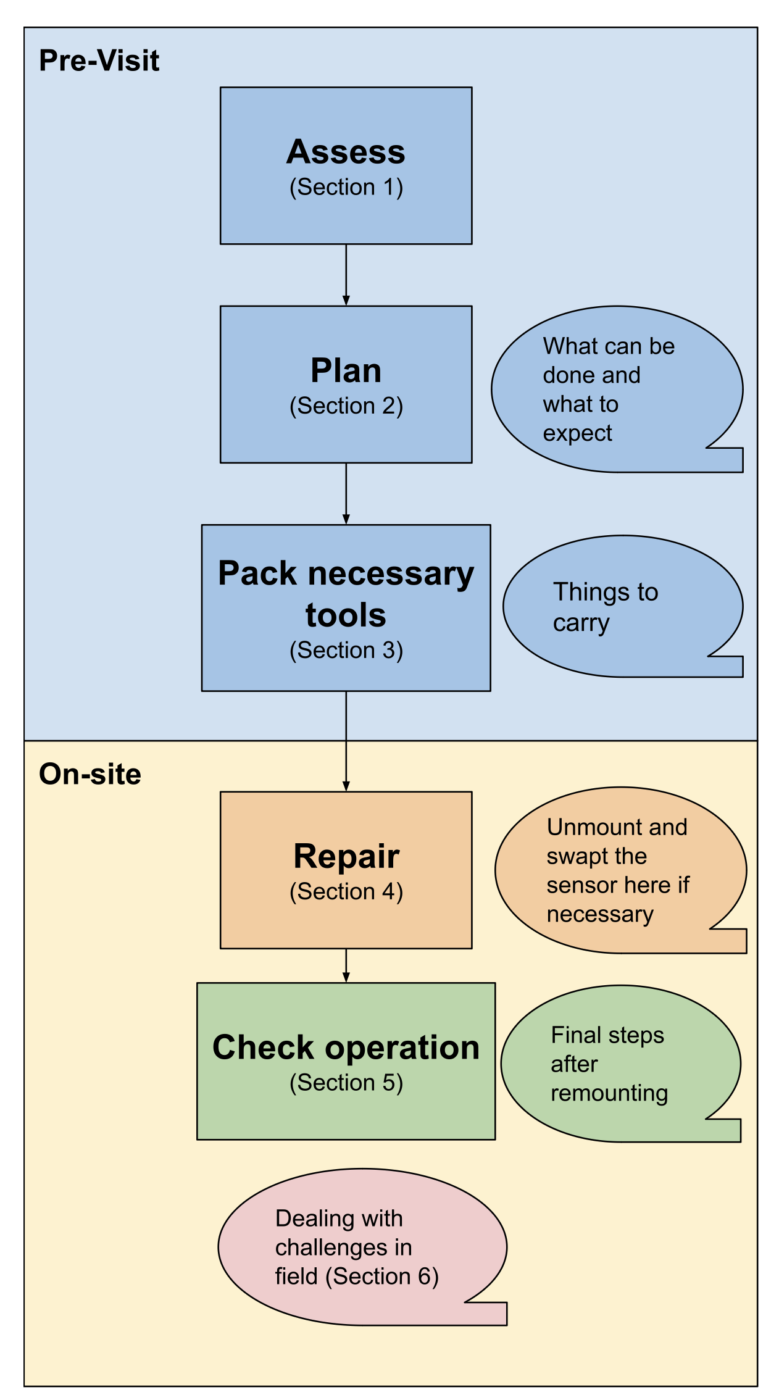
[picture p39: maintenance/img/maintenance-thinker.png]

<br>

## Section 0. Common visit reasons checklist (Pre-visit)	
Before a maintenance visit, speculation about the underlying problem deduced from each particular sensor's latest distance and battery data is very helpful for systematic planning of maintenance visits.

The following is a list of commonly observed scenarios causing a sensor to go offline:
- The nearest gateway is down
- The nearest gateway is operational but the sensor has abruptly stopped working
- Wrong readings 
-  Constantly reading a new inaccurate height
- Sensor readings jump between two values
- Erroneous sensor readings with unusual anomalies
- High Packet-loss; most of the sensor uplinks are missing; packet loss % > 20
- The sensor has stopped working due to a down-trending battery profile (battery charge-discharge cycles are observed but can't keep up)
- The sensor has stopped working due to no charge trend observed at all (no battery charge-discharge cycles observed)

## Section 1. Assessment (Pre-visit)
Check the [Data dashboard](https://dataviz.floodnet.nyc), for: 

1. **Intermittent data:**
	If only one sensor in the area has a problem, it likely has connectivity issues - fix is to replace the antenna or even swap it with a new sensor. Refer to section 2.2: Planning for sensors that have abruptly stopped working and section 2.6: Planning for sensors with high packet-loss.
	The below image shows the scenario with intermittent sensor data 
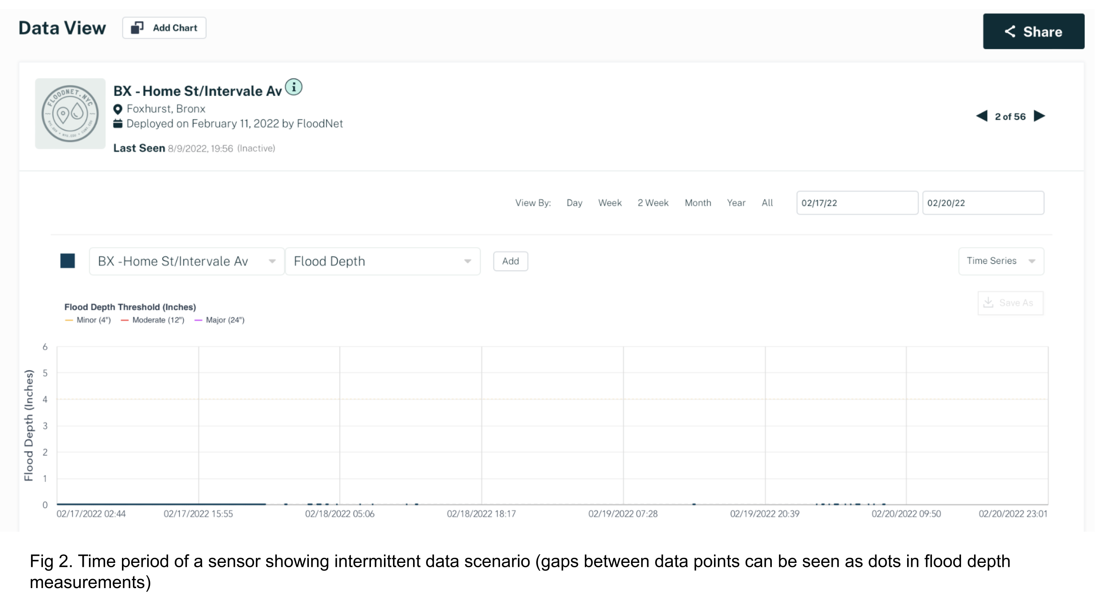
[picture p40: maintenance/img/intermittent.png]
	
	Below is an image, showing previously vandalized floodsensor with the antenna broken
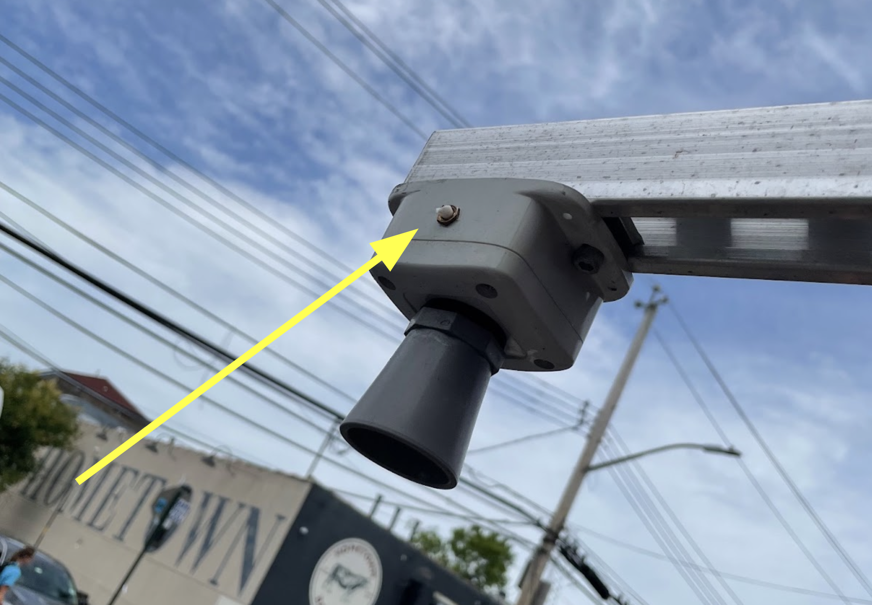
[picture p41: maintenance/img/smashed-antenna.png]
	
	Else, if all the sensors in the area have issues at the same time, the g/w needs some fixing. Refer to section 2.1: Planning when the gateway is down?

2. **Sensor last seen:**
	Date last seen. If time is greater than three hours it is likely that the sensor is down. Antenna could be totally damaged. To check the date last seen of a sensor click on its corresponding dot and a pop-up will show like the one in the figure below.
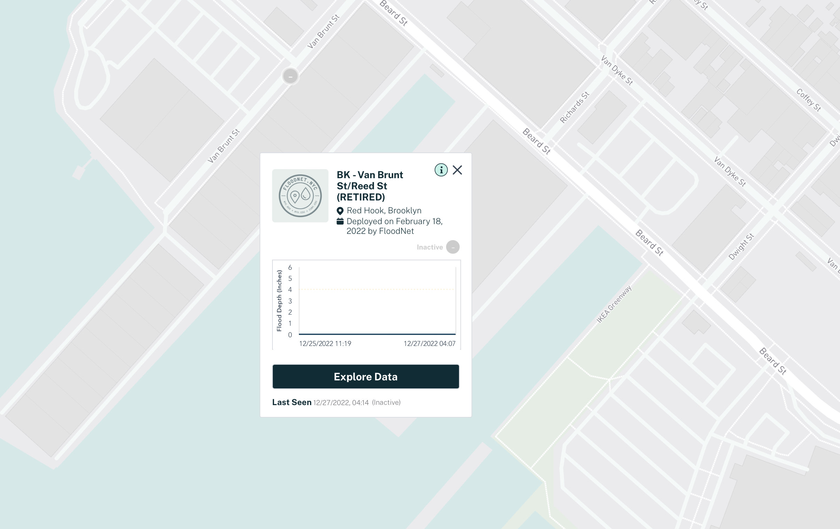
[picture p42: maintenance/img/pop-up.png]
	
	Refer to section 2.6: Planning for sensors that have abruptly stopped working and section 2.3: Planning for sensors with a down-trending battery profile. If the solar panel has been vandalized, FloodNet members can verify that the battery trend has been in the fall.
	Below image shows previously vandalized floodsensor with a missing solar panel.
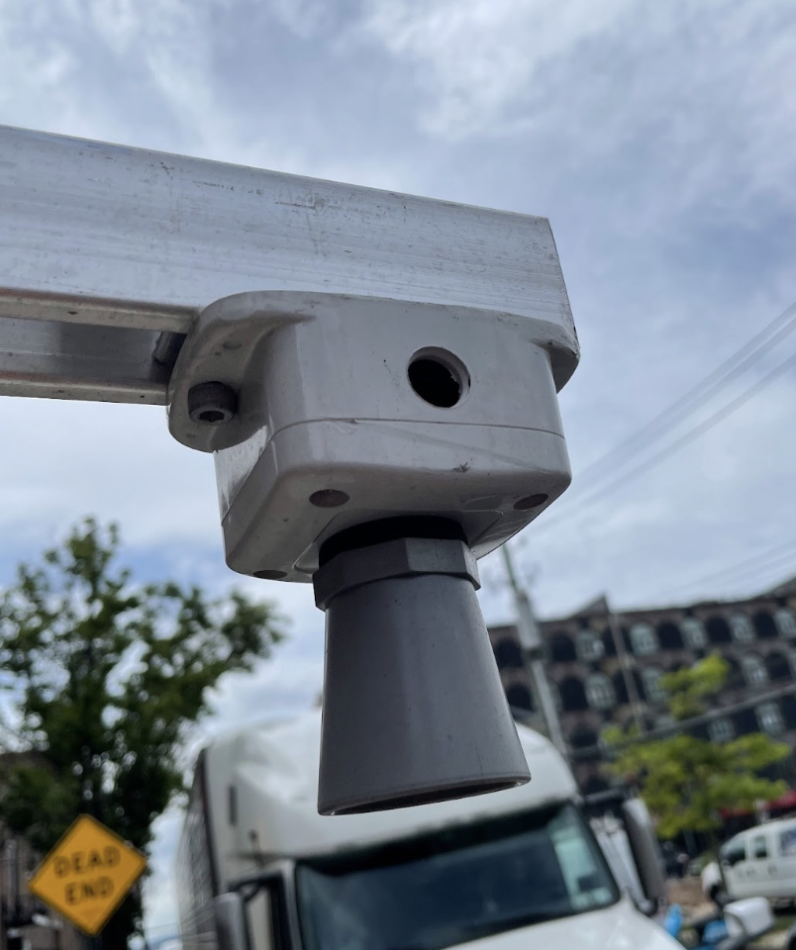
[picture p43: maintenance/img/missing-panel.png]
	

3. **Noisy data:**
	If the sensor data seems to be noisy or wrong, for planning refer to section 2.5: Planning for sensors with wrong readings

	For any other unidentified or abrupt issues Email FloodNet folks - [Charlie](mailto:cmydlarz@nyu.edu), [Bea](mailto:bs3639@nyu.edu), and [Praneeth](mailto:pc3305@nyu.edu) to check on sensor/server/status etc on the back-end internally.

## Section 2. Planning (Pre-visit)
The corresponding repair procedures for the below sections are listed in section 4: Repair procedures (On-site).

### 2.1 Planning when the gateway is down?
To conclude that the gateway seems offline, confirm that all the sensors within a mile radius to this gateway are offline. Contact the FloodNet team to confirm this and proceed with further steps.

Couple of reasons a gateway could go offline:
1. Disconnected power
2. Damaged gateway and/or antenna

### 2.2 Planning for sensors with a down-trending battery profile
The figure below shows a selected period of 8 days where the battery trends down but trends back up. 
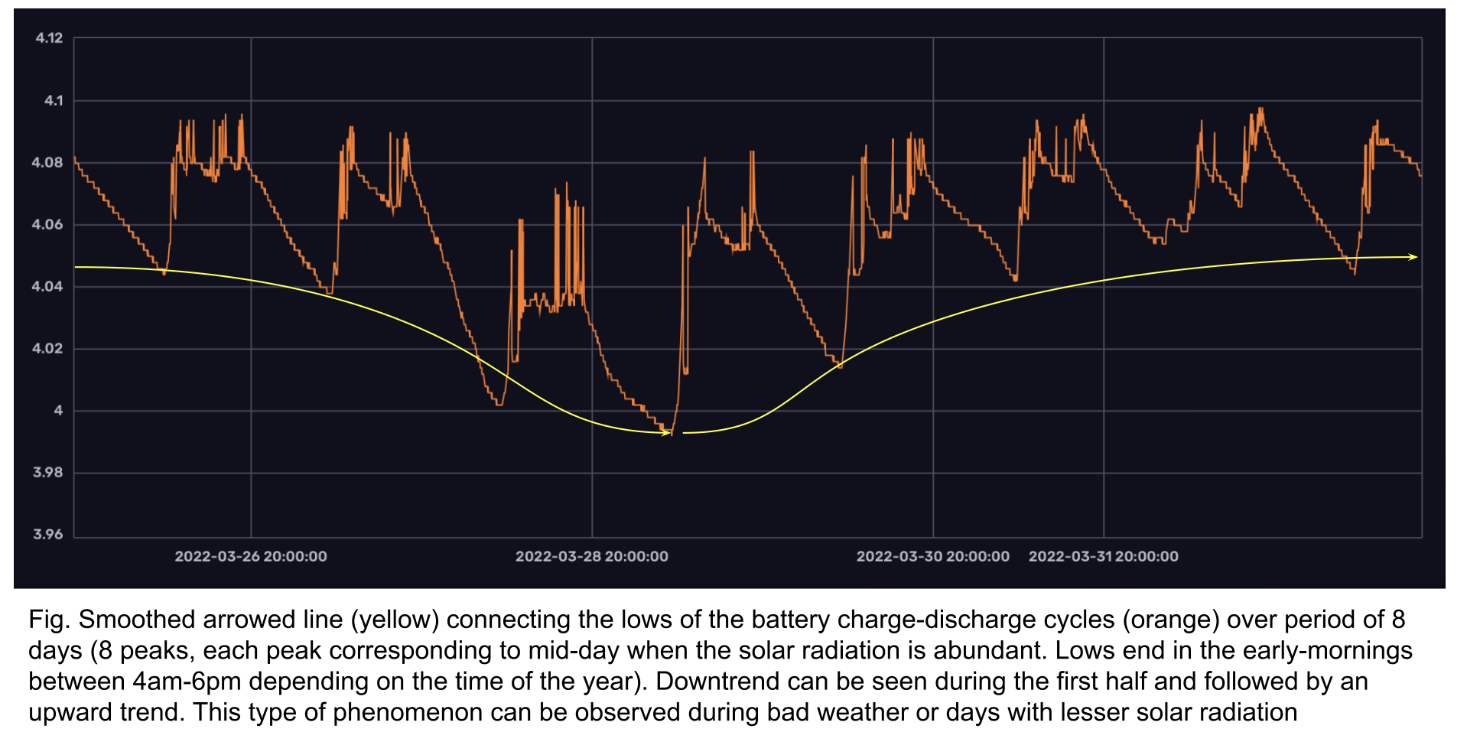
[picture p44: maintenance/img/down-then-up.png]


And, the figure below shows a comparison of a normal trend with downward battery trend.
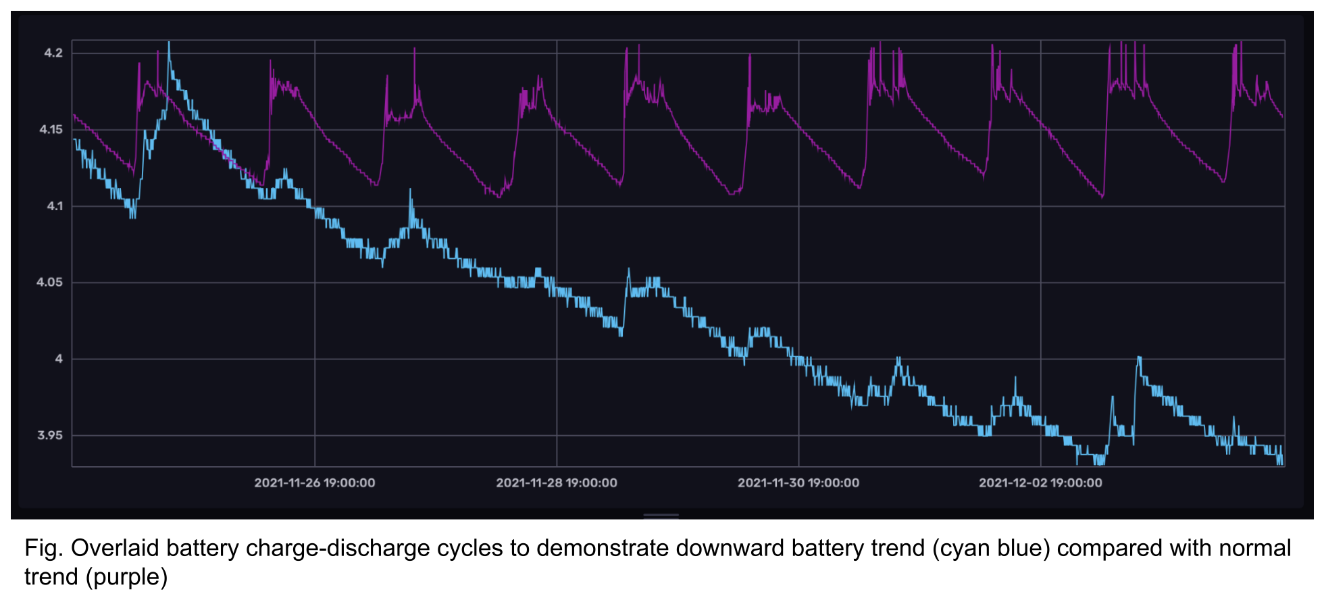
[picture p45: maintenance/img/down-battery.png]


One of the reasons for a down-trending battery profile is insufficient solar power being harvested, or introduction of a new obstacle that has been blocking the solar panel. If this seems to be the case upon inspection, the solar panel alone shall be shifted, if possible, to a different mounting location on the same post facing the direction South. And the sensor can be left in the same place for sensing operations.

Suppose none of the above options seem feasible. This particular sensor shall be relocated to the nearest possible mounting location, ideally in the same street or one that covers the same flooding hotspot. If the relocation of the solar panel is not possible, the duty cycle of the sensor can be reduced to conserve power and keep up with the battery-drain charge cycles. Contact FloodNet team members to perform the duty cycle change.

Upon in-person sensor inspection, an engineer can only deduce the actual cause of a down-trending battery profile. Hence for efficient use of on-ground time, if needed, a new potential deployment for relocation shall be scouted before the maintenance visit regardless of the speculation.

Engineer shall carry the following and swap wherever necessary:

- A sensor to swap
- Sensor spare parts 
- A battery
- An antenna
- Solar panel with mount and cable

### 2.3 Planning for sensors with a no charging trend profile
A no charging scenario has no observable highs or lows in the battery charge-discharge cycles but has a smooth overall battery trend down. This means that the sensor’s solar power harvesting system has failed. This can be due to:

1. Panel failure 
2. Failed electrical connections/components

Both the cases require laboratory debugging; hence a new spare sensor shall be used to swap the faulty sensor. The `deployment_id` shall be the same but the `dev_id` should be a new and a unique one for the spare sensor. Contact FloodNet team members to proceed with this step.

### 2.4 Planning for sensors with wrong readings
Inaccurate readings can be due to one or any combination of the following:

- Damaged ultrasonic sensor
- Parked bikes underneath
- Parked cars underneath
- Newsstand
- Parked Cars
- Spiderwebs
- Trash bags
- Obstacles
- Weeds and dirt
- Damaged or distorted signpost 

In the case of a damaged sensor or an electrical failure, the sensor distance readings would always be 0 mm. On the other hand, if the sensor distance reading is not a zero but 300 mm, this could be due to an obstacle within 30 centimeters of the sensor cone, which is obstructing the sensing pulse, for example, a spiderweb or a newly grown branch, etc. In the former case, if there is any physical damage, the whole unit shall be swapped with a new one as it needs further in-house repairs. If cleaning the insides of the cone is not sufficient, the sensor shall be swapped with a new unit.

Like in the image below, weeds that grow in the sidewalk cracks and the dirt accumulated directly beneath the sensor can lead to inaccurate or 5000 mm or 10000 mm (no return) distance measurements. Cleaning/re-working the surface beneath the sensor can solve this problem. For the sensor to perform its best, the surface underneath shall be concrete and a flat surface.

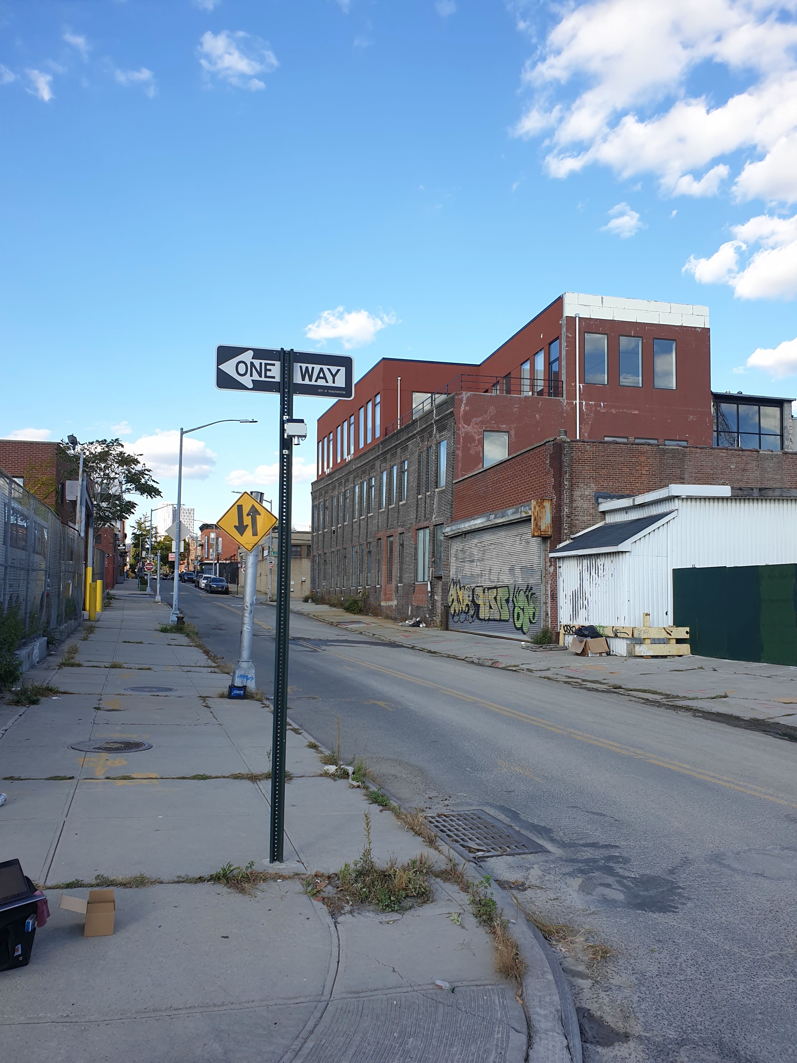
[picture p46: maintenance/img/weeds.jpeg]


Signpost damage or distortion after a sensor deployment changes the angle at which the sensor measures the distance to the surface beneath it. For a typical height of 2700 mm on a signpost, a change in 10° angle can alter the sensor measurements by mod|2700 - 2700*sec(10°)| mm, which is 41.7 mm (1.65 inches). To re-calibrate the sensor, the mounting hardware shall be readjusted using a spirit level to align the mount perfectly horizontally to the earth’s surface below(due to gravity, the water body's surface is horizontal). This can be performed by stacking spare washers between the mounting and its screws on the signpost. 

In some cases, the distortion of the pole might be beyond a significant angle which is impractical for the recalibration of the sensor; the sensor shall be relocated to the following closest optimal mounting location. Additionally, for maintenance, DOT can be informed about the damaged signpost.



### 2.5 Planning for sensors with high packet-loss	
The figure in section 1 shows a scenario of a sensor with high-packet loss percentage. Simply meaning the data is intermittent and missing(can be observed as dots or empty gray lines on the [dashboard](https://dataviz.floodnet.nyc)). Following are some reasons and fixes for sensors with high packet loss percentage:

- Upgrading/Replacing the antenna
- Nearest gateway not within ideal range - Consider new gateway options
- Swapping with a new unit boosted to the maximum radio power and optimal frequencies in compliance with FCC. Contact FloodNet for further assistance.

### 2.6 Planning for sensors that have abruptly stopped working
Reasons for a sensor to abruptly stop working are:

- Compromised waterproofing
- Sensor brownout
- Physical Damage
- Theft or Vandalism
- Sensor failure

Engineer shall carry the following and swap wherever necessary:

1. A sensor to swap because it is most likely that the sensor would need an in-laboratory inspection if none of the sections 2.1, 2.2, 2.3, 2.4, 2.5 and 2.6 applies.
2. Sensor spare parts comes in handy:
3. A battery
4. An antenna
5. A spare Solar panel with mount and cable

## Section 3. Packing necessary equipment and tools (Pre-visit)	
Using the information from section 2, an estimate of the number of sensor units needed for swapping can be made. Spare sensor parts such as antenna, solar panel, and batteries shall be carried as well. Below is a comprehensive and precise list of tools, spares, and everything needed for repairing sensors:

**Checklist:**

| No. | Part name | Qty needed per sensor |
|:---:|---|:---:|
|  1  | Electric screwdriver + attachments | - |
|  2  | Signage | 1 |
|  3  | Safety vests | - |
|  4  | Safety hats | - |
|  5  | Wire cutter | - |
|  6  | Pliers | - |
|  7  | Adjustable wrench | - |
|  8  | Socket adapters | - |
|  9  | Hex Head Screws M6 or 1/4"-20 (1½” long)  | 2 |
|  10 | Hex Head Screws M6 or 1/4"-20 (4” long) | 2 |
|  11 | Hex lock nuts M6 or 1/4"-20 | 2 |
|  12 | Hex Head Screw M8 or 5/16” (1½” long) | 2 |
|  13 | Hex Head Screw M8 or 5/16” (4” long) | 2 |
|  14 | Hex lock nuts M8 or 5/16” | 2 |
|  15 | M6 socket Head screws | 2 |
|  16 | Oversized Clipped Washers | 8 |
|  17 | Strut channel nuts | 1 |
|  18 | Strut channel 1 ft - Aluminum | 1 |
|  19 | Wing nuts - M6 | 1 |
|  20 | Oversized split washers | 4 |
|  21 | Fliers and/or post cards | - |
|  22 | Sandwich board | - |
|  23 | A-frame ladder | - |
|  24 | Spare batteries | 1 |
|  25 | Flash light | - |
|  26 | Long socket attachment - 1/4” | - |
|  27 | Long socket attachment - 5/16” | - |
|  28 | Long socket attachment - 7/16” | - |
|  29 | Long socket attachment - 9/16” | - |
|  30 | Long socket attachment - 1/2” | - |
|  31 | Wrench - 1/4” | - |
|  32 | Wrench - 5/16” | - |
|  33 | Wrench - 7/16” | - |
|  34 | Wrench - 9/16” | - |
|  35 | Wrench - 1/2” | - |
|  36 | Spare antennas | 1 |
|  37 | Flat mending plate | 1 |
|  38 | L-bracket | 1 |
|  39 | Zip Ties | 1 |
|  40 | Spare assembled solar panel with cable | 1 |
|  41 | Provisioned and tested flood sensor | 1 |
|  42 | Circular bubble level | - |

## Section 4. Repair procedures (On-site)	
### 4.1 Repair procedures if the gateway is down	
**Things to try:**

- Make sure that the power supply is present.
- Reset the power supply by unplugging and plugging back the g/w power cable.
- Checking internet connectivity. FloodNet gateways are cellular and/or ethernet connected. 
- Check the Antenna and/or it’s cable for any damages
- Try swapping the gateway and/or it’s antenna with new ones
- For Gateway maintenance, contact FloodNet team for further assistance.

### 4.2 Repair procedures for sensors with a down-trending battery profile	
**Things to try:**

- Swap the battery and solar panel. 
	
	To perform a battery swap, the sensor shall be taken down and opened using a philips screwdriver. To swap the solar panel, unplug the solar cable by twisting the connector anti-clockwise and replace it with a new one. Remount the sensor and zip tie the excess solar cable into the struct channel. Make sure the sensor power switch is turned ON after remounting the sensor on the signpost. 

### 4.3 Repair procedures for sensors with a no charging trend profile	
In this case, the sensor hardware requires laboratory debugging; hence a new spare sensor shall be used to swap the faulty sensor. Contact FloodNet for further assistance.

### 4.4 Repair procedures for sensors with wrong readings
**Things to try:**

- Cleaning the insides of the sensor cone using a soft dry cloth. 
- Clear any obstructions in the way, i.e. between the sensor and the surface it is mounted over. Make sure nothing is present within 2-3 ft. vicinity, on the side of the post that the sensor is mounted
- Removing any weeds or debris on the surface beneath the sensor
- Reworking the concrete surface beneath the sensor
- Check for any signpost damage - twisted or bent. To verify this, place a spirit level on the mounting of the FloodNet’s flood sensor and check for any deviation from the horizontal ground surface. This has been perfectly aligned parallel to the horizontal ground (earth’s surface, not the sidewalk) during the installation. Realign by stacking spare washers.

### 4.5 Repair procedures for sensors with high packet-loss
If the sensor data is patchy, most likely the network isn’t strong enough. Consider new gateway options nearby. 

If the sensor previously worked well but stopped, it must be the antenna (assuming gateway is operational).  

**Things to try:**

- Swap the antenna. To swap the antenna the sensor need not be taken down, the antenna can be replaced externally using a ladder by unscrewing the older antenna and screwing in a new antenna.

**Steps:**

1. For performing only the antenna swap, unmounting the sensor is not necessary. This can be done externally by undoing the older antenna using a ladder, and screwing a new one as a replacement.
2. Finally, check the dashboard for data if this worked
3. If this hasn’t worked, a sensor swap is needed
4. If you find that the interior antenna cable or the antenna socket of the MCU board is totally damaged, a laboratory repair is needed. Retrieve the sensor and contact FloodNet for in-house repair.

### 4.6 Repair procedures for sensors that have abruptly stopped working
**Things to try:**

- Reset the sensor by pressing the sensor push button to OFF position and ON again. ON position is when the push button is held in. There should be a green LED light visible when the sensor is turned on successfully. Wait for the Green LED to go away, which happens when the sensor successfully connects to the network and is online.
- Swap the battery. To perform a battery swap, the sensor shall be taken down and opened using a philips screwdriver. 
- Swap the antenna. To swap the antenna the sensor need not be taken down, but first turn the sensor OFF by pressing the push button. Then, the antenna can be replaced externally using a ladder by unscrewing the older antenna and screwing in a new antenna. When completed do not forget to turn ON the sensor back and wait for it to connect to the network.
- Swap the solar panel

## Section 5. Check and validate the sensor operation

**Steps:**

1. To check the sensor operation, turn ON the sensor by pressing the power button beneath the sensor. 
2. After turning on the sensor successfully, wait for the LED to turn green, which means the sensor is attempting to join the network. The LED goes off when the sensor joins the network and is online. If you see that the LED stays on, make sure the Antenna is screwed in properly and it feels secure.
3. If LED doesn’t turn green at all, check if Battery likely dead or disconnected from PCB socket and check whether the CubeCell power connector is connected to the screw terminals
4. Finally, check the [dashboard](https://dataviz.floodnet.nyc) for data
5. If none of the above worked, swap the sensor with a new one, retrieve the old sensor and contact FloodNet for further in-house repairs. 

## Section 6. Challenges in the field (On-site)
### 6.1 No coverage/Sensor not joining the network
Sometimes the sensor takes a while to pick up the gateway, usually a few minutes. If certain about the gateway being in range and online, the sensor can be turned on and deployed. 

If there seems to be no coverage, deployment in that particular flooding hotspot can be considered for relocation, or even better, a new gateway in the vicinity for better coverage. 

### 6.2 Sensor joined the network but I don’t see any data on the dashboard
This is the case where the sensor has joined the network after maintenance, i.e. after turning the sensor ON the green LED light has been observed and shortly it went off, however no new data has been seen on the dashboard, contact FloodNet to confirm the absence of the sensor traffic on the backend internally. Failed uplinks are due to low signal strength or higher noise levels. Allowing the sensor to settle for a few minutes can help. Make a note for further assessment of network coverage.

### 6.3 Debugging in the field
Debugging in the field is usually not efficient. Nevertheless if needed, the maintenance shall be done under the presence or guidance of an expert sensor technician. 

### 6.4 Vandalism
Community Engagement in that neighborhood and the signage installed along with the sensor can nurture a positive community comprehension by explaining the purpose, privacy concerns, and information about the project. 
Nevertheless, in the case of theft or vandalism, the sensor can be either replaced if the mounting location is not within reachable heights by a 6 feet person from the ground or considered for a relocation.

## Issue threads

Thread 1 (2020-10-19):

Downlink testing: TX interval

Praneethsvch, 2020-10-19:
Changing duty cycle using TX_INTERVAL as a variable:

- testing different duty cycles
- does accidental downlink of large numbers have a danger of sleeping the mcu indefinetly?
- downlink is only changed after an uplink. The following code will print out the downlink received in one of the RX windows.
```
if (LMIC.dataLen)
{
      // data received in rx slot after tx
      Serial.print(F("Received "));
      Serial.print(LMIC.dataLen);
      Serial.print(F(" bytes of payload: 0x"));
      for (int i = 0; i < LMIC.dataLen; i++) {
         if (LMIC.frame[LMIC.dataBeg + i] < 0x10) {
              Serial.print(F("0"));
           }
         Serial.print(LMIC.frame[LMIC.dataBeg + i], HEX);
       }
      Serial.println();
      receive_downlink();
}
```
- using node red to send the downlinks

Praneethsvch, 2020-10-21:
Queuing Multiple downlinks issue can be solved by using 'replace' option. The downlink will replace the currently scheduled downlink, if any. It is also possible to schedule the downlink as the first or last item in a the downlink queue : [reference](https://www.thethingsnetwork.org/docs/applications/mqtt/api.html)

Praneethsvch, 2020-10-21:
Using node-red to inject custom downlinks:

**Sample Flow:**
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

The Inject blocks are manual switches to change the downlink payload message. Using String option and sending bytes in Hexadecimal format.
**Inject block:**
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

Using 'replace' as scheduling option to prevent Multiple downlinks Queuing issue
**downlink node:**
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

Praneethsvch, 2020-10-26:
[TTN fair access policy](https://www.thethingsnetwork.org/docs/lorawan/duty-cycle.html#maximum-duty-cycle) allows a maximum of 10 downlinks, including the ACKs for confirmed uplinks. Exceeding this limit: [Can I avoid Fair Access Policy by implementing a private TTN network?](https://www.thethingsnetwork.org/forum/t/can-i-avoid-fair-access-policy-by-implementing-a-private-ttn-network/2986)

Closed 2020-10-26.

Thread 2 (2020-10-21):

Solar influence on distance data

Praneethsvch, 2020-10-21:
The solar influence on the Maxbotix ultrasonic sensor results in larger distance readings.

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

A flood captured using distance sensor is a decrease in readings when flooding followed by an increase in the readings due to evaporation. In a post-flood scenario, due to the solar influence ultrasonic might read larger distances indicating flood leaving, which is not true.

Possible solution: Using additional external Temperature compensation to negate the solar effects: [HR-Maxtemp](https://www.maxbotix.com/Ultrasonic_Sensors/MB7955.htm)

Praneethsvch, 2020-11-04:
The following is a graph which compares the solar influence on the ultrasonic readings of two sensors: The one on the left uses internal compensation only and the one on the right uses HR-Maxtemp, an additional temperature compensation which is installed outside the housing in addition to the internal compensation.

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

**Observation:**

The standard deviation of the sensor readings is larger when the HR-Maxtemp is used. Also under-compensation has been observed during the day which was not an issue when HR-Maxtemp was not used.

The temperature couldn't be directly correlated with the noise. We suspect that the solar board or the wind could be contributing to the sensor's noise. Thus, the solar board has been disconnected and and a new test has been running on the battery power only, comparing the effectiveness of HR-Maxtemp.

Praneethsvch, 2020-11-06:
Solar board has been disconnected and the two sensors are run on battery for 2 days and here is the data:

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

The solar influence has been reduced slightly, however the sensor data on the right with HR-MaxTemp has more unwanted noise and under-compensation.

Praneethsvch, 2020-11-11:
A new experiment is carried out using a solar shield around the Maxbotix sensor in quest of stable readings and here below is the setup:
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
Inside view:
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
The shield has been mounter carefully over the ultrasonic sensor symmetrically and sealed using liquid tape. The following is the sensor data comparing with and without HR-Maxtemp (left is without and right is with MaxTemp):

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

**Observation:**
- The noise range due to solar is almost the same compared to when the shield is not used.

Praneethsvch, 2021-03-12:
Currently, the input to the Maxbotix sensor is from Feather m0's 3.3V VCC. According to the datasheet, this VCC is regulated by the AK2112 voltage regulator on the board and has an output accuracy of +-1.5%. This is equivalent to a +-49.5mV difference in the Maxbotix's VCC input. Wondering if an additional Cap and a Resistor circuit can be designed to smooth this noise further.

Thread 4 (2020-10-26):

Dealing with sensor reading anomalies by Changing Ultrasonic Sensor Modes via downlink

Praneethsvch, 2020-10-26:
To reduce the sensor reading anomalies, statistical methods such as mean, median and mode are implemented.

Adding mean, median and modes as sensorModes 1, 2 and 3 respectively.

The ultrasonic sensor uses the variable `unsigned int sensorMode` and switches the mode based on the downlink. The default is a single Read without any averaging.

More on averaging can be found on the [sensor's website](https://www.maxbotix.com/tutorials2/129-data-averaging.htm).

Closed 2020-10-27.

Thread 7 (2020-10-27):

Send current config settings with uplink at startup and when changed

Praneethsvch, 2020-10-27:
Add to uplink config settings only on startup and when changed

Praneethsvch, 2021-02-05:
Sensor cfg is sent via uplink at start and when is updated. However this is not stored anywhere. Need to devise a functionality using the backend where user can see the current sensor cfg

Praneethsvch, 2021-07-08:
Sensor cfg change validation server-side and node side need to be implemented in the software

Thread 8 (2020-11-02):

battery vs power supply - sensor noise

Praneethsvch, 2020-11-02:
In laboratory testing, When plugged into a constant DC power supply, the Maxbotix sensor is very accurate almost a 100% of the time:
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
But when on the battery, the sensor readings are noisy with some anomalies:
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

Praneethsvch, 2020-11-09:
This noise is due to interference of the two sensor pulses since they are placed side by side. This is tested and confirmed by carrying out an experiment on battery where there is no possibility of interference of the ultrasonic pulses.

Closed 2020-11-09.

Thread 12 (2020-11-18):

Wrong TimeStamps

Praneethsvch, 2020-11-18:
When used this block of code which was used to develop the library, wrong timestamps are observed:

```
void setup_featherWing(void) {

  //RTC init
//  if (! rtc.begin()) {
//    Serial.println("Couldn't find RTC");
//    Serial.flush();
//    abort();
//  }

  if (! rtc.initialized() || rtc.lostPower()) {
    Serial.println("RTC is NOT initialized, let's set the time!");
    // When time needs to be set on a new device, or after a power loss, the
    // following line sets the RTC to the date & time this sketch was compiled
    rtc.adjust(DateTime(F(__DATE__), F(__TIME__)));
    // This line sets the RTC with an explicit date & time, for example to set
    // January 21, 2014 at 3am you would call:
    // rtc.adjust(DateTime(2014, 1, 21, 3, 0, 0));
    //
    // Note: allow 2 seconds after inserting battery or applying external power
    // without battery before calling adjust(). This gives the PCF8523's
    // crystal oscillator time to stabilize. If you call adjust() very quickly
    // after the RTC is powered, lostPower() may still return true.
  }

  // When time needs to be re-set on a previously configured device, the
  // following line sets the RTC to the date & time this sketch was compiled
  rtc.adjust(DateTime(F(__DATE__), F(__TIME__)));
  // This line sets the RTC with an explicit date & time, for example to set
  // January 21, 2014 at 3am you would call:
  // rtc.adjust(DateTime(2014, 1, 21, 3, 0, 0));

}

String get_timestamp(void){
  DateTime now = rtc.now();
  String custom_timestamp_calibrated = String(now.year(), DEC) + String('-') + String(now.month(), DEC)+ String('-') + String(now.day(), DEC)+ String(' ') + String(now.hour(), DEC)+ String(':') + String(now.minute(), DEC) + String(':') + String(now.second(), DEC);
  return custom_timestamp_calibrated;
}

void writeToSDCard(String StringtobeWritten) {
  //add time stamp to every sd card write
  String timestamp = get_timestamp();
  StringtobeWritten = timestamp + String(',') +StringtobeWritten ;
  char buffchar[StringtobeWritten.length() + 1];
  StringtobeWritten.toCharArray(buffchar, StringtobeWritten.length() + 1);
  digitalWrite(8, HIGH);
  if (!sd.begin(chipSelect, SPI_HALF_SPEED)) {
    // set the SD_ERROR flag high;
    SD_ERROR = 1;
    Serial.println("SD Initialization Failed.");
  }
  else
  {
    ofstream sdout(name, ios::out | ios::app);
    if (!sdout)
    {
      Serial.println("SD Card Open Failed.");
      SD_ERROR = 1;
    }
    else {
      sdout << buffchar << endl;
      // close the stream
      sdout.close();
      SD_ERROR = 0;
    }
  }
  digitalWrite(8, LOW);
}
```
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

Praneethsvch, 2021-01-19:
same issue found here but unresolved: https://forums.adafruit.com/viewtopic.php?f=31&t=134309&p=666320#p666320

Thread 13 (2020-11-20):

Variable LoRa Packet sizes on node as well as server side

Praneethsvch, 2020-11-20:
Currently the LoRa packet size is a fixed size. Addition of sensors would need extra bytes. Need to add new enhancement where the lora packet size depends on the number of sensors on the node. The idea is to send packet size as 1st byte and use this to format the packet on the server side.

Praneethsvch, 2020-11-20:
https://www.thethingsnetwork.org/forum/t/how-to-efficiently-assemble-and-extract-a-mix-of-integer-and-float-data-for-ttn/22908

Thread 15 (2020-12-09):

Library blocking when there is no Adalogger Featherwing

Praneethsvch, 2020-12-09:
The library is expected to work on basic feather M0 LoRa module

Praneethsvch, 2021-01-20:
Library currently is also blocking when no SD Card is inserted even though SdError flag is raised to 1 (Expected: SdError flag set to 1 followed by normal operations)

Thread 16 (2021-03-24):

Library blocking when there is no maxbotix

Praneethsvch, 2021-03-24:
In Serial mode, The library waits for sensor data. Need to fix it from waiting forever if there is a miss or if the sensor is down

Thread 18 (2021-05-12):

V3 packet dropping issue

jatinpalchuri, 2021-05-12:
## Problem
While using the code from the library and adding a device on TTN V3 every other packet is not being read by the TTN console and after receiving a packet exactly after 5 or 6 seconds there is a second packet with all values zero.
For example with a duty cycle of 30 seconds  below is the image with one packet
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
After 5 or 6 seconds there is another packet received with all the values as zero
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
Then the next packet is received after one minute (twice the duty cycle)
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
## Power profile
In the power profile shown below for  the MCU  there is a  transmission at every other duty cycle ,even when when the packets are not being transmitted there is a peak in current.
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
##  progress
 - Started out by changing the time to check for critical jobs in this line [https://github.com/floodsense/floodsense_sensor/blob/466827feb1332f2e8a1de03094b40199ac782f30/src/lorawan.cpp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](url) Since the Rx1+Rx2 for V3 changed to 6 seconds from 2 seconds in V2  , but changing this did not solve the problem.

jatinpalchuri, 2021-05-15:
When I tried with a basic example and looking at the serial monitor I found out that for every other packet that is not being transmitted the TXRXPEND flag being set.
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

jatinpalchuri, 2021-05-18:
The following is a comparison between V2 and V3  where I am waiting for OPTXRXPEND flag to be pulled low and then sending a packet.

In V2 the packets are being sent every 2 to 3 seconds which looks like the RX1+RX2 for V2

But for V3 the pending flag requires some random time as low as 6 seconds(Rx1+Rx2) to ~100 seconds.

For V2 the following is the serial monitor output

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

For V3 the following is the serial monitor output in the  image you can clearly see the random time intervals between two consequent packet upload.

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

jatinpalchuri, 2021-05-24:
Even with a simple example of sending packets continuously we can see from the previous examples that OPTXRXPEND flag is being set in V3.So instead of adding new values to stack the code below waits for this flag to be cleared indicating no pending transactions and then schedules a new packet.
 * Find the updated code in this branch [maxbotix-serial-v3](https://github.com/floodsense/floodsense_sensor/tree/maxbotix-serial-v3) .
 * Before using the code change the lmic library in Arduino to the updated one from [here](https://github.com/mcci-catena/arduino-lmic)

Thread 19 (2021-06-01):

Remote app change for deployed devices

cmydlarz, 2021-06-01:
Each device is setup with a default appkey pointing to our dev application. On first boot, device receives onJoin downlink containing deployment apppkey. We catch this first onJoin event and inject the new appKey. The appkey to send is decided by deveui. We maintain database of devEUIs to AppKeys.

jatinpalchuri, 2021-06-07:
So as soon as we receive a  downlink we have to update  the key values  and  lmic library should be reset thereby making the mcu point to a different app.([code]( https://github.com/floodsense/floodsense_sensor/blob/v3-Appkey-change/src/lorawan.cpp))
While implementing this there is an error assertion  in lmic library here [Assertion error ]( https://github.com/mcci-catena/arduino-lmic/blob/48f04f1413a7f10bf52d979fe01c4d00911100d8/src/lmic/radio.c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)
Is there a better way to stop or check for completion of all tasks in lmic library?

jatinpalchuri, 2021-07-19:
The downlink is not always received by the micro controller  we are facing a similar issue to  [this](https://github.com/TheThingsNetwork/lorawan-stack/issues/1228)

Praneethsvch, 2021-11-16:
bac3104c23c4484a1277ef45b0ecec923dfcc22a Latest remote app change commit - Verified

Closed 2021-11-16.

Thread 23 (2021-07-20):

Make sure measurements are taken in free run mode

cmydlarz, 2021-07-20:
Based on the datasheet its best we dont use triggered mode: https://www.maxbotix.com/documents/HRXL-MaxSonar-WR_Datasheet.pdf

Could gain 5mm accuracy.

Comment out trigger pin lines and test

Praneethsvch, 2021-07-21:
Free Run-mode:
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

Setting up Free Run-mode:
Simply pull Pin 4 - Read Pin High in the setup!

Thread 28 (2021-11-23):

Antenna Issues

Praneethsvch, 2021-11-23:

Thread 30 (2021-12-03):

Add support for easy integration of sensors - RG-15 and US,  Debugging mode and Deployment mode

Praneethsvch, 2021-12-03:
1. In setup detect the type of sensor connected, then code shall automatically switch to the corresponding sensor type.
2. Debugging mode vs Deployment mode: Add Trace support to debugging mode and optimize the code for deployment code by disabling options that are not needed.

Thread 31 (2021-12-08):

Solar Power Harvesting

Praneethsvch, 2021-12-08:
Need help with locations where direct sunlight is not available, one of our sensors on Smith and 2nd Ave is right next to a big building and the battery charging curve is trending down. Any suggestions/ideas on how to deal with such locations would be helpful!

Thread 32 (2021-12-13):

Sensor reverts to CFG mode on power cycle

cmydlarz, 2021-12-13:
It seems that on a hard power cycle a sensor reverts to the `CFG` state. We should store the last state locally and have it resume where it left off as gateway rainfall sensors will likely power cycle and cant be left in the `CFG` state.

Praneethsvch, 2022-04-21:
fixed a1d7071789cf7c05d9f0e98657d7d2f1241fa464

Closed 2022-04-21.

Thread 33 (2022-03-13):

Sensor data looks like its being filtered on free run mode

cmydlarz, 2022-03-13:
After running the Maxbotix vs teh Adafruir US sensors on the roof for >24hours, I see that the Maxbotix looks like it is filtering the distance data and jumps between discrete 10mm values as we saw when the filtered mode was switched on.

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

This code was pulled from the main branch so I think is current.

Can we confirm what is going on?

Praneethsvch, 2022-03-15:
The mode we currently use is `Triggered - Real-time Range Data`, in which we pull the `Pin 4` High for 20us before each sensor reading.

From the datasheet,
- "When pin 4 is low and then brought high, the sensor will operate in real-time and the first reading output will be the range measured from this first commanded range reading. When the sensor tracks that the RX pin is low after each range reading, and then the RX pin is brought high, unfiltered real-time range information can be obtained."
- "Users can enter and remain in the real-time or triggered operation by making sure that before the end each range cycle, the voltage level on pin 4 is set low. After the sensor has completed the last reading, then Pin 4 is brought high. When Pin 4 is brought high, a brand new range cycle starts and the HRXL-MaxSonar-WR will output the most recent range data without filtering."

The same is implemented in the [sensor_singleread(void)](https://github.com/floodnet-nyc/flood-sensor/blob/cae1f3b738a08ccdb2f821b316072dfa37bfb746/firmware/src/maxbotix.cpp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) function.

In contrast, `Free-Run Operation` uses a filter for increased accuracy and this needs the `Pin 4` to be on all times.

From the datasheet,
- "On the HRXL-MaxSonar-WR sensors, when pin 4 is left high, the sensor will continue to range, the data output includes a filter for increased accuracy in environments with acoustic noise."

Praneethsvch, 2022-03-15:
Prior to using the serial output, Pulse-width output has an inaccuracy of 0.5% of serial output plus a different 1uS/mm resolution compared to serial, which is simply 1mm. In the latter, the microcontroller calculates the `distance` based on the duration or width of the incoming pulse which could further add inaccuracies from the clock.

Praneethsvch, 2022-03-16:
This is the change of sensor reads from the beginning, just leaving here for reference:
1. old v2 sensors - Always ON, Trigger every 20us and digitalRead(PulseIn Output)

_Hoyt and 5th sensor data:_
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

2. April 5 2021     - Always ON, Trigger every 20us and Serial Read

_Carroll and 4th using feather:_
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

_Carroll and 4th using Heltec:_
3. Nov 15, 2021    - Low-Power using Vext, Trigger every 20us, and Serial Read
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

From the above series of events, this has been the case since the sensors completely shutdown every sleep cycle using Vext pin.

_Further comments:_ You are right and I still can't comprehend this bug as it is counterintuitive. As the sensor is completely shut off from power, isn't it expected to reset and boot every time giving non-filtered readings? I speculate whether there is an internal memory that keeps track of filtering parameters that are saved beyond power cycles. However, this theory wouldn't hold as we are not running this on filtered-mode, unless something changed in their design since we started using them

Praneethsvch, 2022-03-18:
Confirming that the **_Serial read using Trigger mode_** from the latest branch is giving filtered output. The resolution drops from `1 mm` to `1 cm` and the readings end with `2`.

Observations after testing:
- Picked a random sensor and with every combination of VEXT and  **_Serial read using Trigger mode_**, the output is same `1 cm` resolution with `2` at the end.
- The same sensor when rewired and operated without Serial pin, using Pulse width mode, the resolution is back to `1 mm` (the first deployments are with this configuration).

Praneethsvch, 2022-04-20:
while loop at: https://github.com/floodnet-nyc/flood-sensor/blob/020fa2d212e8227fcd903d61b33d0e0d5af1e035/firmware/src/maxbotix.cpp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 was only reading in 3 characters. As this logic has been overlooked, now that it is solved by changing it to 4, the drop in resolution is ruled out

Praneethsvch, 2022-04-21:
fixed a1d7071789cf7c05d9f0e98657d7d2f1241fa464

Closed 2022-04-21.

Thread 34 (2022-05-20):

Check battery voltage before join

cmydlarz, 2022-05-20:
Check battery voltage before join to reduce the chance of brownouts due to low battery voltage

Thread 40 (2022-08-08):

Channel Activity Detection(CAD) implementation to wake-up over the air

Praneethsvch, 2022-08-08:
Currently end-node listens only after TX, limiting their operational control over the air

SX12xx radios are capable of CAD [pg 42 in Datasheet](https://semtech.my.salesforce.com/sfc/p/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)

In this mode, implement Listen Before Talk (LBT) - to listen for commands pre-deployment, and post-deployment.

Periodically wakeup to check any activity; if seen trigger an interrupt and wake up to receive the message.

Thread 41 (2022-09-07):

ADC accuracy

Praneethsvch, 2022-09-07:
Seeing 0.05 to 0.1 Volts inaccuracy in ADC readings. Measurements are compared using true RMS Multimeter - mfg.no UT61E.
ST states factory read-only calibration value is available. ADC Calibration function is called but currently seems to be inaccurate by 0.05-0.1 Volts. Need further digging on this issue and verification
Todo:
- Check whether recalibration value is readable and present
- Verify upon recalibrating using this constant, reading matches with actual battery level
- Re-Re-calibrate the recalibration function to give correct readings

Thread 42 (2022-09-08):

Low power modes for new board - Sleep and Deep-sleep

Praneethsvch, 2022-09-08:
# 4 sensor operational mode types are available for use
## Run mode
- by default the sensor is in run mode after a system power-on or reset
## Sleep mode
- Several sleep modes are available: Sleep, LPRun, LPSleep, Stop0, Stop1, and Stop2 modes

### Sleep mode
- CPU clock is off
- All peripherals including CPU core peripherals (among them NVIC, SysTick) can run and wake up the CPU when an interrupt or an event occurs

### Low-power run mode (LPRun)
- System clock less than 2MHz
- Code is run from SRAM or FLash
- Regulator is in low-power mode
### Low-power sleep mode (LPSleep)
- entered from the LPRun mode

### Stop 0 and Stop 1 modes
- SRAM1, SRAM2 and _all_ registers values are retained
- PLL, MSI, HSI16, and HSE32 are disabled
- LSI and LSE running
- Sub-GHz radio may remain active independent from CPU
- Stop0 -> Power regulator is on for faster wakeup times but at the expense of higher power consumption
- Stop 1 -> Uses Low-power regulator instead
- Can exit into - MSI uptown 48MHz or HSI 16

### Stop 2 mode
- SRAM1, SRAM2 and _some_ registers values are retained
- rest almost similar to Stop0 and 1

## Standby mode
- VCORE is off
- LSI and LSE are running
- Only SRAM2 contents are possible to retain after wake-up
- RTC can be active
- Sub-GHz radio may remain active independent from CPU

## Shutdown mode
- VCORE is off
- only LSE can be kept running

## Future todo
Currently sensor is 1 min duty cycle with successive readings during on time just before RX, so a single best sleep-mode should do. But with more operations and interrupt/timer wake-ups the sleep modes should be carefully chosen to get lowest power consumptions
- Wakeup and Sleep Power overheads
- Tradeoffs using modes between sensor operations

## Reference
Full functionalities in [Datasheet on pg 29](https://www.st.com/resource/en/datasheet/stm32wle5jc.pdf)

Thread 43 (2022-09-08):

Solar Charger IC operation testing

Praneethsvch, 2022-09-08:
[BQ24210 datasheet link](https://www.ti.com/lit/ds/slusa76b/slusa76b.pdf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)

## Usage
To use Solar Charger IC in charge mode:
- Pin PG_bar = LOW (FET ON)
- Pin EN_bar = LOW (enable charge mode)

## To operate
MCU pin PB4 is PG. When this pin is:
- LOW  -> OFF
- HIGH -> ON

Closed 2023-03-20.

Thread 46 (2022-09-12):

Hardware connectors

Praneethsvch, 2022-09-12:
Solar Wire connector:
- Current connector used for solar cable has issues with being secured tightly. When the outer washer is tightened, the connector inside still moves

Praneethsvch, 2023-03-27:
Key'd housing solved this issue.

Closed 2023-03-27.

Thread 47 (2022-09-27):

Join reset timer disrupts Join procedure OTAA

Praneethsvch, 2022-09-27:
Join requests are on `DR_0` and `DR_4`, and 30 seconds for reset time is too soon to reset the sensor.

Todo:
- Implement 4 trails to go through all the channels. That would be approx 4x72 tries (64 `DR_0` channels and 8 `DR_4` channels)
- Sleep in between join tries
- Reset if failed after 4 trails.

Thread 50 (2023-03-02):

Sensor traffic not seen at TTN console after G/W is back online from being down for longer periods

Praneethsvch, 2023-03-02:
Sensors session on the end-device side is alive and the `F_Cnt` is  increasing.
The G/W also sees the sensor traffic.
TTN cannot see sensors.

Todo:
- Backend-heartbeat?
- Session reboots?

Praneethsvch, 2023-03-20:
- To get around this issue, end-device rejoins once every 10 days.
- The worst case scenario is that the G/w dies right after a sensor rejoin, and comes back up after 10 days. In this case the sensor data is missed until the next sensor re-join (10 days worst case).

Praneethsvch, 2023-03-20:
yes - this one 85882e0c7a5b7d82a4249a9181892bd18f0afbab

Closed 2023-03-20.

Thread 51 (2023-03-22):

Battery trend-down

Praneethsvch, 2023-03-22:
Here is a battery trend plot for a sensor in Hamilton Beach with the deployment_id `duly_pro_vervet `.

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

The battery was swapped on 3/17/23 but the trend still is the same. Need further investigation.

Speculation of possible causes:
- Failed Panel
- Damaged Solar Cable
- Fried board

Praneethsvch, 2023-04-12:
Moved to more relevant place, issue #28.

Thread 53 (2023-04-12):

Saving joined OTAA session

Praneethsvch, 2023-04-12:
# Saving joined OTAA session v3 sensor

## Todo
- Retrieve previously joined OTAA session upon reboot, if exists.
- Save all necessary LoRaWAN stack parameters needed to restore a session

## Reference:
1. [TR007 Developing LoRaWAN® Devices v1.0.0](https://hz137b.p3cdn1.secureserver.net/wp-content/uploads/2021/05/TR007_Developing_LoRaWAN_Devices-v1.0.0.pdf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) - Section 3.13: OTAA Required Persistent Values

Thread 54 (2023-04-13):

Downlink issues - Missing downlinks

Praneethsvch, 2023-04-13:
# Issue
When queuing a downlink, it has been observed that some sensors in the field need multiple tries to successfully hear one.

## Potential Fixes
1. Increasing `RECEIVE_DELAY1` and `RECEIVE_DELAY2`. Refer to pg 27 on [Regional Parameters 1.0.4](https://resources.lora-alliance.org/technical-specifications/rp002-1-0-4-regional-parameters) document.
2. Try existing LoRaMac procedures that are implemented in the middleware - `RXTimingSetupReq` and `RXTimingSetupAns`

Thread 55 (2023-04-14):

DevNonce has been reused - LoRaWAN® L2 1.0.4 Specification

Praneethsvch, 2023-04-14:
# `DevNonce` Overview
According to [LoRaWAN® L2 1.0.4 Specification](https://lora-alliance.org/wp-content/uploads/2021/11/LoRaWAN-Link-Layer-Specification-v1.0.4.pdf) pg 45, for each transmission of a join-request by the end-device, the `DevNonce` value shall be incremented and stored in non-volatile memory.

```
"DevNonce is a counter starting at 0 when the end-device is initially powered up and
incremented with every Join-Request. A DevNonce value SHALL never be reused for a given
JoinEUI value. If the end-device can be power-cycled, then DevNonce SHALL be
persistent (e.g., stored in a non-volatile memory). Resetting DevNonce without changing
JoinEUI will cause the Join Server to discard the Join-Requests of the end-device. For each
end-device, the Join Server keeps track of the last DevNonce value used by the end-device
and ignores Join-Requests if DevNonce is not incremented."
```

## Fix/Improvements todo:

- Increment by 1 for every join-request on the end-deive
- Store `DevNonce` in non-volatile memory

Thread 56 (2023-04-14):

Brownout Detection

ak6492, 2023-04-14:
Carroll and Garfield sensor went down in the field. Battery was fully charged and once reprogrammed, the heltec appeared to be functional. Conclusion is that the heltec got caught up in field and never recovered

Praneethsvch, 2023-04-14:
### Issue
- Brownout

### Firmware version
- [v4.3.1](https://github.com/floodnet-nyc/flood-sensor/tree/4.3.1)

### Metadata: Location, dep_id
- Carroll and Garfield
- `daily_gentle_beetle`

### Fix
- Brownout detection strategy

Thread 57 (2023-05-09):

Roll-back to default application

Praneethsvch, 2023-05-09:
### Issue
- Current logic -> If a join procedure is failed, roll-back to default application.
- This logic fails when a sensor is deployed and upon a reset there is no n/w connection i.e., a join failure causes the sensor to roll back to the default application
- Can trigger a roll-back in the case of any sensor that fails to join within `joinTimeOut` duration

### Firmware version
[v4.3.1](https://github.com/floodnet-nyc/flood-sensor/tree/4.3.1)

### Potential Fix
Update deployment and app change strategy

Praneethsvch, 2023-12-14:
Added ADV_DEP_MODE as an optional, defaulted to EASY_DEP_MODE defined in this commit notes [3207409](https://github.com/floodnet-nyc/flood-sensor/commit/32074090ad07cdc7a972c6ce96447420c3d4c40c)

Closed 2023-12-14.

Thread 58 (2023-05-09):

RCA - sensor at Lorraine and Henry

Praneethsvch, 2023-05-09:
### Issue
- Sensor is down since 4/14/2023, 23:09 EST
- Reason unknown

### Sensor version and firmware version
- v2

### Metadata
1. `deployment_id` - early_still_frog

### Action
- Root cause analysis needed

ak6492, 2023-09-11:
linked to a newer version issue for this sensor

Closed 2023-09-11.

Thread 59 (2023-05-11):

RCA - 4th Ave & Garfield

Praneethsvch, 2023-05-11:
### Issue/Bug/Suggestion
  - Sensor stopped working on 5/6/2023, 12:12

  ### Sensor version and firmware version
  - v2 , firmware version: [4.3.1](https://github.com/floodnet-nyc/flood-sensor/tree/4.3.1)

  ### Metadata
  1. `deployment_id` - daily_gentle_beetle
  2. `dev_id` - fs-00002
  3. deployed by - FloodNet

  ### Fixes/Action
  - RCA needed

ak6492, 2023-09-11:
linked to more recently open 4th Ave and Garfield issue

Closed 2023-09-11.

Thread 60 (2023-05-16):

antenna n-type connector sheathing with heat-shrink

rictolcrow, 2023-05-16:
To prevent corrosion, put a heat-shrink sheath over the base of the antenna before installing
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

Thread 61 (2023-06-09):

RCA - Russell St 2

ak6492, 2023-06-09:
**Sensor Deployed:**
- March 5, 2021 by FloodNet

**Sensor Version:**
- v2.0.

**Firmware Version:**

**Sensor Down:**
- April 3, 2023 19:23

**Solution Implemented:**
- whole sensor replaced on June 7, 2023 with another v2.0.

**In Lab RCA:**
- antenna was perfectly intact
- no visible rusting or corrosion both internally and externally
- battery in sensor completely drained and dead
- solar panel outputting voltage and increases it's output voltage when light is shined on it thus proving it is functioning correctly
- sensor booted back up when new battery was inserted into it

**deployment_id:** easily_dear_mouse

**dev_id:** fs-00023

**Fixes/Action:**
In conclusion, sensor appears to have gone down due to the battery dying completely and being unable to retain charge from solar panel. The reason behind this seems to be the battery just being out in the field for about two years and going through its natural battery life cycle. Need to track about how long after being out in the field, batteries stop being functional to try to get ahead of sensors going down due to faulty old batteries.

mprafull1, 2023-06-09:
In Lab RCA:
Battery didn't got charged even when connected to the charger.

ak6492, 2023-07-10:
Sensor replaced on 06/07, went down again on 06/09, data analysis shows the following:

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

Signal Strength looks good, battery is trending down rapidly and not charging

ak6492, 2023-07-12:
**07/11 On Site Analysis:**

battery was visibly puffed up. ended up replacing battery and solar panel.

mprafull1, 2023-07-13:
Battery was dead also but it charged in the lab.

ak6492, 2023-11-10:
Sensor data has repeatedly been noisy. On site visit on 11/09 did not reveal any visible sign of what might be causing the noise. Nothing was obstructing the sensor and there was no grass or spiderwebs inside the pipe. Need to observe and understand this issue further.

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

ak6492, 2024-02-16:
sensor removed on 02/15

Closed 2024-02-16.

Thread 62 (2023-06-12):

Buswick Troubleshooting

mprafull1, 2023-06-12:
2 sensors were deployed on 06/02/2023.
Dev_ids -
fs-00056 - Knibocker ave/Hart st
fs-00090 - Morgan ave/ Johnson ave

fs-00090 :
 Issue-
Missing lots of data packets but getting uplinks and downlinks.

Analysis-
Low network coverage
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
Battery is okay.
loss packet percentage - 94.4%
Surrounded by warehouses and its 0.904 mile from the  gateway that is placed at 303 Vernon.

fs-00056:
Issue- Missing comparatively less packets but not getting downlinks.

Analysis-
Network coverage is comparatively better but still low
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
loss packet percentage - 56%
Surrounded by buildings and its 0.975 mile from the  gateway that is placed at 303 Vernon.

ak6492, 2023-10-06:
New Gateway in Bushwick and use of the remote gateway has helped bring these two sensors up

Closed 2023-10-06.

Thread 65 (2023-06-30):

Gateway - 303 Vernon

ak6492, 2023-06-30:

mprafull1, 2023-07-12:
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

SNR and RSSI value of additional sensor (fs-00085) and glamos at Knickerbocker Ave/Hart St

mprafull1, 2023-07-12:
No RSSI and SNR at Morgan Ave/Johnson Ave as they were not joining at all.

mprafull1, 2023-07-12:
SNR and RSSI at Vernon 303

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

At 0.2 mile from gateway

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

At 0.4 mile from gateway

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

At 0.6 mile from gateway

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

At 0.8 mile from gateway

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

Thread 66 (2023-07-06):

v3 sensor PCB - silk screen update

Praneethsvch, 2023-07-06:
On the latest board spin, on J7 and J8 JST-PH 2-pin connectors, the ground is marked with a dot on the wrong pins.

Todo: Modify silk screen marking to match the correct GND pins for connectors J7 and J8

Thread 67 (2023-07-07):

RCA - Russell St 1

ak6492, 2023-07-07:
Sensor Deployed:

March 5, 2021 by FloodNet
Sensor Version:

v2.0.
Firmware Version:

Sensor Down:
June 22, 2023 20:16

deployment_id: duly_pro_vervet

Fixes/Action:
Sensor went down on 06/22, in the past has gone down because it's antenna was smashed

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

Praneethsvch, 2023-10-19:
Issues:
1. Keeps switching back to config mode
2. When is sensing mode - 9999

ak6492, 2024-02-16:
updated to firmware with no config mode 02/15

Closed 2024-02-16.

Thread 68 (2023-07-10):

RCA - Beach 66th St and Thursby Ave

ak6492, 2023-07-10:
Sensor Deployed:
March 17, 2023 by FloodNet

Sensor Version:
v2.5.

Firmware Version:

Sensor Down:
June 29, 2023 8:57

deployment_id: small_red_chicken

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

ak6492, 2023-07-12:
**07/11 On Site Analysis:**

Nothing visibly wrong with the sensor. Tree in full bloom over solar so want to observe if battery charging is being affected by lack of coverage in warmer months. But switching out battery did not bring up sensor, ended up replacing sensor completely

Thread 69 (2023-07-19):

RCA - BK: Pioneer St/ Conover St

ak6492, 2023-07-19:
Sensor Deployed:
February 18, 2022 by FloodNet

Sensor Version:

Firmware Version:

Sensor Down:
July 12, 2023 15:33

deployment_id: gladly_mint_snail

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

ak6492, 2023-07-24:
On Site RCA and in lab RCA:
Antenna appeared to be broken - not connecting when tested in lab
Solar mount is completely falling apart and solar cable connection to PCB board is loose

Hypothesis: Wear and tear from being out in field

ak6492, 2023-10-06:
Sensor is up and working fine as of 10/06

Closed 2023-10-06.

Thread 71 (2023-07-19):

RCA - BK: Lorraine St/ Henry St

ak6492, 2023-07-19:
Sensor Deployed:
February 18, 2022 by FloodNet

Sensor Version:

Firmware Version:

Sensor Down:
April 14, 2023 23:09

deployment_id: early_still_frog

ak6492, 2023-07-25:
In Lab RCA:
visibly fine in field, battery and solar panel functioning. Antenna is good. When we connect the tiny 2-point JST cable to the heltec, the heltec does not get powered up. We think that the power connector on the back of the heltec is not working properly. The heltec is also not working correctly because even when powered up with jumper cables, the heltec still doesn't connect.  Ended up replacing sensor with v2.5 on July 20, 2023.

ak6492, 2023-09-11:
#58

ak6492, 2023-10-06:
Sensor seems to be working fine as of 10/06

ak6492, 2023-10-06:
Sensor seems to be up and working as of 10/06

Closed 2023-10-06.

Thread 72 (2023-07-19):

RCA - BK: 4th Ave/ Garfield Pl

ak6492, 2023-07-19:
Sensor Deployed:
July 15, 2021 by FloodNet

Sensor Version:

Firmware Version:

Sensor Down:
June 15, 2023 15:24

deployment_id: daily_gentle_beetle

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

ak6492, 2023-07-25:
In Lab RCA:
Visibly fine. Battery is shorted and below operational voltage. Ended up replacing v2 with v2.5 on July 20, 2023.

ak6492, 2023-09-11:
#59

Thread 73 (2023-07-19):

RCA - BK: Kingston Ave/ Rutland Rd

ak6492, 2023-07-19:
Sensor Deployed:
May 24, 2023 by FloodNet

Sensor Version:

Firmware Version:

Sensor Down:
June 26, 2023 19:56

deployment_id: mainly_kind_boxer

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

ak6492, 2023-08-25:
08/25: Sensor is sending up data in lab, but is not receiving downlink to switch into live

ak6492, 2023-09-01:
08/31 Maintenance Trip: Potential firmware of live devices going back into lab mode. issue that might have been fixed with reprogramming it with latest firmware.

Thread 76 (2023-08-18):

RCA - BK: Junius St/ Sutter Ave

ak6492, 2023-08-18:

ak6492, 2023-09-01:
Maintenance Trip on 08/17. Replaced heltec and battery was shorting. Went down again 08/28. Sensor was working fine but was back into config mode. Went back out on 08/31 and reprogrammed the sensor. We think the config issue might be do to some error in firmware. Downloaded and uploaded the latest firmware. This sensor is also noisy. Might be do it being mounted at 3meters which is relatively higher than usual sensors. As distance increases the maxbotix has more room for error. Need to observe this sensor a little more and might need to change its mounting distance.

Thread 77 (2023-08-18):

RCA - Q: 1st St/ 104th St

ak6492, 2023-08-18:

ak6492, 2023-08-18:
In Lab RCA:
heltec is shorted, battery is shorted. This heltec was a used heltec found in lab

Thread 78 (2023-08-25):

RCA - BK:  Winthrop Street/ E 94th

ak6492, 2023-08-25:
Sensor Deployed:
May 24th, 2023 by FloodNet

Sensor Version: 2.5.

Firmware Version:

Sensor Down:
August 24th, 2023

deployment_id: slowly_key_husky

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

Battery Charge Capacity started to trend downwards from August 8th

ak6492, 2023-09-01:
Maintenance Trip 08/31: Solar port was unplugged. Replugged the port in and replaced with a charged battery.

ak6492, 2023-11-10:
The battery drained again towards the end of September, had to go back on 11/09 to replace solar panel. Will RCA panel in lab. Observe battery trend, if battery drains again, will need to replace sensor/heltec

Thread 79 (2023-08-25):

RCA - BK: Wallabout/ Harrison Ave

ak6492, 2023-08-25:
Sensor Deployed:
March 9, 2023 by FloodNet

Sensor Version: 2.5.

Firmware Version:

Sensor Down:
August 18, 2023

deployment_id: simply_half_monkey

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

ak6492, 2023-08-25:
#78

ak6492, 2023-09-01:
Maintenance Trip 08/31: replaced battery with a new charged battery. Battery recovered from field was puffy, need to perform in lab RCA on it. Solar panel/port were working fine.

ak6492, 2023-09-15:
09/15: Battery was continuing to trend downwards despite a new battery being put into the sensor on 09/08 and the solar panel/port seemingly doing fine with multimeter. Ended up replacing entire sensor with another sensor because the heltecs were not soldered correctly and a simple heltec replacement could not be done in field. Will perform RCA in lab on retrieved sensor and need to monitor whether or not the battery in the new sensor charges now.

ak6492, 2023-10-06:
10/05: Have been seeing higher volume of no returns. Upon on site inspection revealed barricades placed underneath the sensor. Hoping that they are temporary placements.

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

ak6492, 2023-11-10:
Battery was not charging because of faulty heltec. Replacing the heltec has remedied the situation of the battery not charging in the field.

Closed 2023-11-10.

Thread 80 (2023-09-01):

RCA - BK: Wallabout/ Throop Ave

ak6492, 2023-09-01:
Sensor Deployed:
March 9, 2023 by FloodNet

Sensor Version: 2.5.

Firmware Version:

deployment_id: mean_flying_fish

Sensor has been very noisy since deployment. Upon inspecting the sensor on 08/31 it was seen that the sensor was very crooked and not leveled at all on the drive rail. The antenna was also damaged, and looked barely operational. The sensor was remounted to be more leveled on 08/31. Need to see if this will fix the noise issue for this particular sensor

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

cmydlarz, 2023-09-05:
Sensor is being observed before we close the issue. New label assigned for possible fix

ak6492, 2023-09-08:
Observed on 09/08, seems to no longer be getting no returns but may still be noisy

ak6492, 2023-09-15:
Observed on grafana on 09/15, seems to be doing a lot better. At most one no return value a day. Closing issue for now

Closed 2023-09-15.

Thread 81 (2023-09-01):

RCA - BK: Marcy Ave/ Flushing Ave

ak6492, 2023-09-01:
Sensor Deployed:
March 9, 2023 by FloodNet

Sensor Version: 2.5.

Firmware Version:

Sensor has been very noisy since deployment. Upon inspecting the sensor on 08/31 it was seen that the sensor was inside of a tree. When sensor was deployed in the winter there was no tree bloom, but trees have encapsulated the sensor since then. Possible solutions include moving the sensor to another location or cutting down tree branches.

deployment_id: closed_wagon_snail

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

ak6492, 2023-09-15:
09/15: Went and cut off a few branches of the tree that were immediately surrounding the sensor specifically where the maxbotix on the sensor was. Need to monitor the sensor for a bit to see if that fixes the no returns, also not a permanent solution as tree will bloom again every year.

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

ak6492, 2023-10-06:
10/05: Battery has been trending downwards since August 22nd. Suspecting that this is due to this sensor being inside a dense tree. Replaced with new battery, hoping that in the upcoming weeks leaves will start falling and the sensor will be able to recover. Long term solution is to double check solar panel, heltec, and then move the sensor slightly down to drive rail closer to subway entrance.

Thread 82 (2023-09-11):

RCA - Q: Beach 43rd Street

ak6492, 2023-09-11:
Sensor Deployed:
December 21, 2022 by FloodNet

Sensor Version:

Firmware Version:

Sensor Down:
August 26, 2023 04:12

deployment_id: bored_blue_fish

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

Battery Level starts dropping drastically and sensor stops holding charge 08/24 onwards

ak6492, 2023-10-06:
10/05: Battery was replaced. Assumption that maybe being in the field for over a year near salt water has caused the battery to stop retaining charge. Solar Panel was working fine. Looking at graph today on 10/06, shows that battery is still not charging. If this trend continues over next few days is to replace sensor with a new 2.5.

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

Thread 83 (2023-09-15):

RCA - BK: Kent Ave/ Wallabout St

ak6492, 2023-09-15:
Sensor Deployed:
March 9, 2023 by FloodNet

Sensor Version: 2.5.

Firmware Version:

Sensor has been hitting no return values since March

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

deployment_id: light_maroon_penguin

ak6492, 2023-09-15:
09/15: The sensor was not mounted vertically and also the nuts/bolts of all the components were extra loose. Maybe someone messed with it? There was also a school bus parked right next to it that was also there the other few times the sensor was listed. Observe to see if the remounting of the sensor to be pointed more inwards toward the sidewalk rather the road fixed the issue.

Closed 2023-10-06.

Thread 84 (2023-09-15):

RCA - SI: Rector St/ Richmond Terrace

ak6492, 2023-09-15:
Sensor Deployed:
March 24, 2023 by FloodNet

Sensor Version: 2.5.

Firmware Version:

Sensor has been down since 15:37 on August 14th. It is up and running in lab, but is not receiving downlinks to switch into live. Sensor was visited on September 7th. Even after reprogramming the sensor, it did not take the downlinks. Need to go back with mobile gateway.

ak6492, 2024-02-12:
updated with new firmware on 12/02

Closed 2024-02-12.

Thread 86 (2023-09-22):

RCA - BK: Brinkerhoff Ave / 157th St

ak6492, 2023-09-22:
Sensor Deployed:
September 27, 2022 by FloodNet

Sensor Version: 2.0.

Firmware Version:

Sensor has been hitting no return values pretty much since deployment.

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

ak6492, 2023-09-22:
09/21: This sensor is known to be an illegal dumping ground. Would recommend moving the sensor to another location.

mprafull1, 2023-09-22:
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

ak6492, 2024-04-01:
03/28: somehow more trash present now. very noisy and consistently shows up wrong data on dataviz. strongly recommend replacing it

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

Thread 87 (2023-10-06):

RCA - Q: Beach 84th Street

ak6492, 2023-10-06:

ak6492, 2024-02-12:
02/12: PSR has gotten worse since antenna replacement on 12/18.

Possible solutions:
1. change antenna
2. replace v2.0 with cell sensor v3.5

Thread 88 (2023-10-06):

Multiple deployment & dev ids for BK: 9th St/ Smith St

ak6492, 2023-10-06:
A sensor with the deployment_id: highly_equal_doe and dev_id: fs-00008 has been showing up in Grafana dashboard queries. Suspected to be one of three deployments at 9th St/ Smith St.

Right now this location is shown with the deployment_id of overly_heroic_squid but this is nowhere to be found in Grafana dashboard and Sensor Location Directory.

In TTN 9th and Smith has the dev_id of fs-00008, I suspect that highly_equal_doe is the correct deployment_id but need to verify this.

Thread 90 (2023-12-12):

RCA - Q: Kissena Blvd/ Rose Ave

ak6492, 2023-12-12:
Sensor Deployed:
November 16, 2023 by FloodNet

Sensor Version: v3.1. (cell)

Firmware Version:

Sensor Down:

deployment_id: doubtfully_popular_fawn

Sensor never charged since it had been deployed. Went down on November 25, 2023

ak6492, 2023-12-12:
12/12: In lab RCA that the solar IC had not been soldered properly. The solar IC was incapable of charging. Replaced sensor with new one.

ak6492, 2023-12-12:
follow up and check if sensor is charging correctly since replacement in a week

Praneethsvch, 2024-01-16:
### Issue
- Sensor failed due to water ingress
- When water creeps in the sensor still operated but in bad conditions
    - noisy data like battery data below from water damaged sensor
    - It starts trending down or doesn't charge as well as the other sensors

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

  ### Metadata
  1. `doubtfully_popular_fawn `
  2. `fsc-00008` is damaged and now replaced with `fsc-00015`

  ### Fixes/Action
  - swapped with a new sensor
  - To swap the plug with the n-type antenna ASAP

ak6492, 2024-02-12:
02/12: Down completely since plug was swapped out with n-type antenna on 01/24. Did struggle to connect via nodered on the ground

ak6492, 2024-03-05:
02/28: the switch was turned off physically. no other visible damage. up and running as of 03/05

Closed 2024-03-05.

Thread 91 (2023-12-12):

RCA - BK: Knickerbocker Ave/Palmetto St

ak6492, 2023-12-12:
Sensor Deployed:
November 16, 2023 by FloodNet

Sensor Version: v3.1. (cell)

Firmware Version:

Sensor Down: November 23, 2023

deployment_id: generally_enormous_panda

Sensor battery level was trending downwards and battery never charged since deployment.

ak6492, 2023-12-12:
12/12: Plug nut was not secured in correctly so water leaked into the sensor. Suspect that this is the reason why the sensor went down. Replaced sensor with a new one. Follow up and confirm in a week if the sensor is fine now.

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

ak6492, 2024-02-12:
sensor is very noisy right now. suspect that adc is messed up due to in lab board manufacturing.

ak6492, 2024-04-10:
03/28: Sensor was replaced. seems to be working fine now

Closed 2024-04-10.

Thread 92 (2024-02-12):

Brownsville Gateway

ak6492, 2024-02-12:
Gateway was replaced on November 9, 2023 only for it to go back down at the end of December. Construction was going on when we were there in November, suspect that something related to that has led to the gateway being down again.

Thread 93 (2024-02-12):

RCA - : Knickerbocker Ave/Palmetto St

ak6492, 2024-02-12:

ak6492, 2024-03-22:
03/22/24: Visited on March 24, 2024. Battery was fully charged for sensor. Suspect that the SIM card was expired, as replacing in with new SIM card revived the sensor. For good measure replaced the in house made solar cable and sensor. Old sensor at this location can be reused.

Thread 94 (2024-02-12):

RCA - SI: Hylan Blvd/Jefferson Blvd

ak6492, 2024-02-12:
down since 01/19. Struggled to charge 01/14 onwards. Potentially water damaged?

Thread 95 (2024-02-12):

RCA - BK: Hoyt St/5th St

ak6492, 2024-02-12:
replace battery. trended downward. been out in field for two years

ak6492, 2024-02-13:
02/13: Sensor has magically come back up recharged. Keep an eye out and monitor battery level

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

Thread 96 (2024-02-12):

RCA - Q: 184th/91st

ak6492, 2024-02-12:
died on 02/02. second time dying despite a replacement on 01/24. sensor cable might be at fault as sensor never charged

ak6492, 2024-03-05:
02/28: replaced entire sensor. I suspected that the solar panel was at fault as a part of the inner wiring was exposed. Tested solar panel in lab, and it seemed to be fine. Monitor sensor in field for a week more. If it goes down again, the location is not getting sufficient sunlight and needs to be moved.

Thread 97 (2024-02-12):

RCA - Q:  Beach 35 St/Beach Channel Dr

ak6492, 2024-02-12:
battery is still up and running. but this sensor has never gone live. it is struggling to calibrate because of noise?

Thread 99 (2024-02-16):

RCA -  Q - Brookville Blvd/ 147th Ave

ak6492, 2024-02-16:
Sensor Deployed:
August 17, 2023 by FloodNet

Sensor Version: v2.5.

Firmware Version: latest with no config mode

Sensor Down: January 13, 2024

deployment_id: vastly_select_guinea

Stuck in live sending join requests but not joining. Replaced antenna but still no luck.

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

 Future steps include:

1. going back with working mobile gateway
2. replacing with cell sensor

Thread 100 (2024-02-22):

Noise observed on sensor data

cmydlarz, 2024-02-22:
Q - 160th St and Brinkerhoff Ave
truly_pretty_calf
fs-00103

One possible cause is the possibility of increased noise on the 10m version of teh ultrasonic sensor. @rictolcrow has observed this in the lab. Any new findings on this?

@ak6492 and @mprafull1 do you know if this sensor has a 10m or 5m version of the ultrasonic sensor?

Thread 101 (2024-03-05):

RCA: Q - Utopia Pkwy/ 67th Ave

ak6492, 2024-03-05:
Sensor Deployed:
October 26, 2023 by FloodNet

Sensor Version: v3.1. (cell)

Firmware Version:

Sensor Down:

deployment_id: lively_wanted_louse

sensor had water damage from antenna plug. Replaced with new sensor

ak6492, 2024-03-05:
02/28: sensor was replaced with a new one, as of 03/05 the sensor is working as intended

Closed 2024-03-05.

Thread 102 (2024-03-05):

RCA: Q - 88th Street Alleyway/Astoria Blvd

ak6492, 2024-03-05:
Sensor Deployed:
January 12, 2024 by FloodNet

Sensor Version: v3.1. (cell)

Firmware Version:

Sensor Down: February 29, 2024

deployment_id: curly_furry_squirrel

down unclear yet as to why. Possible sources of failure:
1. connectivity issue
2. battery connection
3. water damage
4. physical damage to the sensor

ak6492, 2024-03-18:
suspected cause is sensor has been damaged or shut down

ak6492, 2024-03-22:
03/22/24: sensor was visited on March 21, 2024. Simple SIM card replacement fixed the issue. Suspect that the SIM card had been expired. Double check and confirm

cmydlarz, 2024-03-22:
Both SIMs that came back were working in the lab:

ak6492, 2024-03-25:
@cmydlarz we did reboot and checked battery level before swapping

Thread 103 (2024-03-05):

RCA: BK - Knickerbocker Ave/Palmetto St

ak6492, 2024-03-05:
Sensor Deployed:
November 16, 2023 by FloodNet

Sensor Version: v3.1. (cell)

Firmware Version:

Sensor Down: March 2, 2024

deployment_id: generally_enormous_panda

ADC is messed up on this one. Battery being reported back in meters

ak6492, 2024-04-01:
04/01: Sensor was taken down on 03/28 and after RCA in lab it was determined that the ADC was for sure messed up on this one. But the reason for why the sensor went down is that the battery modification made in the lab to accommodate non button top batteries was the culprit.

Closed 2024-04-01.

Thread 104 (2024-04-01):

Q - 159th St and 109th Ave

ak6492, 2024-04-01:
sensor has been tinkered with. needs to be reclamped and the solar panel needs to be replaced

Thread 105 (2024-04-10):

RCA - BK: Lee Ave/Middleton St

ak6492, 2024-04-10:
Sensor has been showing high volume of no returns. In field visit revealed that the sensor was tampered with. Had to remount and tighten sensor.

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

Remounting the sensor has made the value of no returns go down. This neighborhood needs community engagement.

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

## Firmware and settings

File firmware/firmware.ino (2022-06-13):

/*  --------------------------------------------------------------------------------
 *  This Example uses Maxbotix Ultrasonic Sensor and Heltec CuebeCell AB02 dev board
 *  to read the depth and send the distance and battery level over the
 *  LoRaWAN network.
 *
 *  Connections:
 * 
 *    VEXT       -> Maxbotix V+
 *    GND        -> Maxbotix GND
 *    RX2        -> Maxbotix Serial Pin (Pin 5: Serial output)
 *    GPIO 5     -> Maxbotix triggerPin (Pin 4: Ranging start/stop)
 *
 *  -------------------------------------------------------------------------------- */


#include "Floodsense_sensor.h"

void setup() {
  delay(3000);
  Serial.begin(115200);
  Serial.println("Starting");

  setup_maxbotix(2, 150, 7);     // sensor mode 2(Median), 150ms sampling rate (time between readings), 7 readings per measurement
  setup_lorawan(60);             // uplink frequency 60 seconds - controls duty cycle
}

void loop() {
  lorawan_runloop_once();
}

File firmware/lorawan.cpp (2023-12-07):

#include "lorawan.h"
#include "maxbotix.h"
#include "sensorcfg.h"
#include <EEPROM.h>
#include "sensorcfg.h"
#include <stdint.h>
#ifdef __asr650x__
#include "innerWdt.h"
#endif

#define LED_GREEN GPIO6
#define TIME_TO_REJOIN 10*24*60 // 10 days in minutes

#ifdef ADV_DEP_MODE
/*Sensor states*/
#define SENSING_STATE 1
#define RESET_STATE 2
#define CFG_STATE 3
char is_deployed;
char is_started;

/* EEPROM params */
const int selectionAddress = 8; // Single char (y/n) in ASCII
const int init_Address = 9;
const int newAppAddress = 12;    // 12 to 19
const int newAppKeyAddress = 21;  //21 to 37
const int newDevEUIAddress = 40;
const int defaultAppEUIAddress = 50; // 50 to 57
const int defaultAppKeyAddress = 58; // 58 to 73
const int defaultDevEUIAddress = 75; // 75 to 82
const int isDeployed = 90;
const int isStarted = 91;
/*
  Semantic Versioning 2.0.0 Format:
        MAJOR_VERSION.MINOR_VERSION.PATCH_VERSION
*/
const int MAJOR_VERSION = 4; // incompatible changes
const int MINOR_VERSION = 3; // add functionality in a backwards compatible manner
const int PATCH_VERSION = 2; // backwards compatible bug fixes
uint8_t SENSOR_STATE;
/*SYS params*/
#endif 

#ifdef EASY_DEP_MODE
#define SENSING_STATE 1
const uint8_t SENSOR_STATE = SENSING_STATE;
#endif 

/*flags*/
bool autoFeed = false;      // Watchdog timer
bool overTheAirActivation = 1;
bool loraWanAdr = false;
bool keepNet = false;
bool isTxConfirmed = 0;
unsigned int ERROR_FLAGS;


/* OTAA para*/
uint8_t devEui[] = TTN_DEVEUI;
uint8_t appEui[] = TTN_APPEUI;
uint8_t appKey[] = TTN_APPKEY;
/* ABP para*/
uint8_t nwkSKey[] = { };
uint8_t appSKey[] = { };
uint32_t devAddr =  ( uint32_t )0x0000;
/*LoraWan channelsmask, default channels 0-7*/
uint16_t userChannelsMask[6] = { 0xFF00, 0x0000, 0x0000, 0x0000, 0x0000, 0x0000 }; // 0xFF00 from 00FF
/*LoraWan region, override IDE defaults*/
LoRaMacRegion_t loraWanRegion = LORAMAC_REGION_US915;
/*LoraWan Class A*/
DeviceClass_t loraWanClass = CLASS_A;

#ifdef ADV_DEP_MODE
/*LoRaWAN application data transmission duty cycle.  value in [ms]. DEFAULT is 10 seconds*/
uint32_t appTxDutyCycle = 10 * 1000;
/*User defined variable - TX_INTERVAL, changes between states as needed. DEFAULT is 10 seconds*/
uint16_t TX_INTERVAL = 10;
#endif // DEBUG

#ifdef EASY_DEP_MODE
/*LoRaWAN application data transmission duty cycle.  value in [ms]. DEFAULT is 10 seconds*/
uint32_t appTxDutyCycle = 60 * 1000;
/*User defined variable - TX_INTERVAL, changes between states as needed. DEFAULT is 10 seconds*/
uint16_t TX_INTERVAL = 60;
#endif

uint8_t appPort = 2;
uint8_t confirmedNbTrials = 4;
uint8_t lowpower = 1;
uint32_t uplink_number = 0;

/******************************************************************************************

  Functions

*******************************************************************************************/

void ModifyDutyCycle(McpsIndication_t *mcpsIndication) {
        unsigned long dutycycle = 0;
        for (int i = 1; i < mcpsIndication->BufferSize; i++) {
                dutycycle =  (mcpsIndication->Buffer[i]) | ( dutycycle << 8 * (i - 1));
        }
        if (dutycycle != 0 && dutycycle < 1000) {
                Serial.print("Current duty cycle is: ");
                Serial.println(TX_INTERVAL);
                // Changing Duty Cycle
                TX_INTERVAL = dutycycle;
                Serial.print("Updated dutycycle is: ");
                Serial.println(TX_INTERVAL);
        } else {
                Serial.println("Dutycycle is the same.");
        }
}

void ModifySensorMode(McpsIndication_t *mcpsIndication) {
        unsigned int sensorMode_ = 0;
        sensorMode_ =  (mcpsIndication->Buffer[3]) | ( sensorMode_ );
        if (sensorMode_ > 0 && sensorMode_ <= 3 ) {
                Serial.print("Current sensorMode is: ");
                Serial.println(sensorMode);
                // Changing Sensor Mode
                sensorMode = sensorMode_;
                Serial.print("Updated sensorMode is: ");
                Serial.println(sensorMode);
        } else {
                Serial.println("Sensor Mode is the same.");
        }
}

void ModifySamplingRate(McpsIndication_t *mcpsIndication) {
        unsigned int sampling_rate = 0;
        sampling_rate =  (mcpsIndication->Buffer[4]) | ( sampling_rate );
        sampling_rate =  (mcpsIndication->Buffer[5]) | ( sampling_rate << 8);
        if (sampling_rate != 0 ) {
                Serial.print("Current sensor sampling rate is: ");
                Serial.println(sensor_sampling_rate);
                // Changing Sensor Mode
                sensor_sampling_rate = sampling_rate;
                Serial.print("Updated sensor sampling rate is: ");
                Serial.println(sensor_sampling_rate);
        } else {
                Serial.println("Sensor sampling rate is the same.");
        }
}

void ModifyNumberOfSamples(McpsIndication_t *mcpsIndication) {
        unsigned int numb_readings = 0;
        numb_readings =  (mcpsIndication->Buffer[6]) | ( numb_readings );
        if (numb_readings != 0 && numb_readings < 20) {
                Serial.print("Current number of readings per measurement: ");
                Serial.println(sensor_numberOfReadings);
                // Changing Sensor Mode
                sensor_numberOfReadings = numb_readings;
                Serial.print("Updated number of readings per measurement: ");
                Serial.println(sensor_numberOfReadings);
        } else {
                Serial.println("Sensor number of readings per measurement is the same.");
        }
}

void ModifySensorSettings(McpsIndication_t *mcpsIndication) {

        switch (mcpsIndication->BufferSize) {
        case 2:
                ModifyDutyCycle(mcpsIndication);
                break;
        case 3:
                ModifyDutyCycle(mcpsIndication);
                break;
        case 4:
                ModifyDutyCycle(mcpsIndication);
                ModifySensorMode(mcpsIndication);
                break;
        case 6:
                ModifyDutyCycle(mcpsIndication);
                ModifySensorMode(mcpsIndication);
                ModifySamplingRate(mcpsIndication);
                break;
        case 7:
                ModifyDutyCycle(mcpsIndication);
                ModifySensorMode(mcpsIndication);
                ModifySamplingRate(mcpsIndication);
                ModifyNumberOfSamples(mcpsIndication);
                break;
        default:
                //should never reach here
                Serial.println("Invalid Sensor settings received.");
                break;
        }
}
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

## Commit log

2020-10-26 maxbotix sensor modes: {1, 2, 3} : {mean, meadian, mode}
2020-10-26 fixed array length removed std::sort
    [maxbotix.cpp]
2020-10-27 addded dutycyle via downlink to sensorModes
2020-10-27 Implemented and tested changing sensor modes via downlinks.
2020-10-27 Update basic_sensormodes.ino
    updated sensor configurations
2020-11-04 Update sensorcfg.h
    description updated
2020-11-11 Update README.md
    added link to sensor_experiments
2021-01-06 added fritzing circuit
2021-01-08 added new sensor designs and data comparisons
2021-04-02 Update ttnPayloadDecoder.js
    added Temperature, Humidity, Pressure and Altitude fields in the decoded message.
2021-07-29 Revert "Update lorawan.cpp"
    This reverts commit 10888b871a0a946f61ab5a39e0e94e2c53667c3b.
    [lorawan.cpp]
2021-07-29 Revert "Vext renamed to GPIO 6"
    This reverts commit 539ec3da7dab4aec21200b827c95528bd13ebf0e.
    [lorawan.cpp, maxbotix.cpp]
2021-07-29 Vext Switch to Turn off sensor
2021-07-29 changed sensor reads to 7, Vext bug fix
    [maxbotix.cpp]
2021-07-29 fixed batterylevel bug
2021-08-11 Join Failure Debug added
    New device state DEVICE_STATE_JOIN_FAILED is added. Resources are added and these files are needed to compile the code
    [lorawan.cpp]
2021-08-18 softwareSerial added, removed unwanted Serial prints
2021-08-23 Vext pinMode added, trigger pin to GPIO5
2021-08-24 Update lorawan.cpp
    couple of typos fixed
    [lorawan.cpp]
2021-08-24 Update lorawan.cpp
    first packet is now sensor cfg
2021-09-15 sensor operation modes addes: Start, Stop and Reset
    Command format: char 'O' followed by 'start', 'stop' or 'reset'
    Actual downlinks shall be in hex bytes.
    Start downlink message format in hex bytes: 4F7374617274
    Stop downlink message format in hex bytes: 4f 73 74 6f 70 0a
    Reset downlink message format in hex bytes: 4f 72 65 73 65 74
    [lorawan.cpp]
2021-11-12 reverted back to trigger mode from free run mode
    Trigger mode operation with no internal filtering. Both uses serial data comms and hardware connection changes are required
    [maxbotix.cpp]
2021-11-12 first wrong reading bug fix
    added an extra read to exclude the wrong readings
    [maxbotix.cpp]
2021-11-15 sensor_state bug fix
    use int string instead of hex format
2021-11-15 fix appTxDutyCycle and TX_INTERVAL bug
    Duty Cycle for sensor operation is stored in
    TX_INTERVAL, this is the frequency of sensor data update. appTxDutyCycle is current duty-cycle and is 10s for CFG update
    [lorawan.cpp]
2021-11-15 duty-cycle bugs fixed
    fixed duty cycle bugs:
    1. Removed repeated variables, and duplicates.
    2. `TX_INTERVAL` can be changed only via packet_interval (argument of `setup_loarwan(unsigned int packet_interval`), and `ModifyDutyCycle(McpsIndication_t *mcpsIndication)` in lorawan.h
    [lorawan.cpp]
2021-11-16 verified Patch 4.0.1
    Tested App Change, and Modification of Sensor operation modes and states.
2022-04-13 CFG bug fix, EEPROM clear fix upon flash
    1. Upon reset after deployment, CFG state is not maintained, rather, sensor starts reading.
    2. EEPROM is cleared after every reset or flash before deployment. Once deployed, EEPROM must be cleared manually if needed.
    [lorawan.cpp]
2022-04-20 Resolution drop Bug fixed
    changed while loop to read 4 char now
    [maxbotix.cpp]
2022-04-21 update `SENSOR_STATE`
    new variable SENSOR_STATES keeps track of sensing state. Following are possible states:
    1. SENSING_STATE
    2. CFG_STATE
    3. RESET_STATE
    After deployment and starting the sensor, the sensor saves this state and upon further resets, sensor starts sending readings as uplinks. This is a fix for previous version where reset puts sensor in CFG mode.
    [lorawan.cpp, maxbotix.cpp]
2022-05-06 Bug fixes
    1. RESET state removed from lorawan loop to prevent unwanted behavior while the device is in DEVICE_STATE_CYCLE state. It has been moved to ProcessDownlik function.
    2. Delay after WDT changed from 5 sec to 10 sec.
    [lorawan.cpp]
2022-06-01 csv to mardown with links
    [BOM.csv]
2022-06-08 gerbers push
2022-06-09 added Autodesk Fusion 360 design files
    [SolarPanelMount.f3d, SolarPanelMount.stl]
2022-06-13 fix Arduino compile errors
    [firmware.ino, lorawan.cpp, maxbotix.cpp]
2023-02-09 Added LED s/w
2023-03-02 Delete ak-solar-panel-mount-v2.stl
    updated version
    [ak-solar-panel-mount-v2.stl]
2023-03-02 Delete ak-solar-panel-mount-v2.step
    updated design
    [ak-solar-panel-mount-v2.step]
2023-03-02 Delete ak-solar-panel-mount-v2.f3d
    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
    [ak-solar-panel-mount-v2.f3d]
2023-03-02 Updated V2 Solar Panel Mount
    [solar-panel-mount-v2.f3d, solar-panel-mount-v2.step, solar-panel-mount-v2.stl]
2023-03-14 Delete solar-panel-mount-v2.png
    updating design
2023-03-14 Delete solar-panel-mount-v2.f3d
    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
    [solar-panel-mount-v2.f3d]
2023-03-14 Delete solar-panel-mount-v2.step
    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
    [solar-panel-mount-v2.step]
2023-03-14 Add files via upload
    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
    [solar-panel-mount-v2.f3d, solar-panel-mount-v2.step, solar-panel-mount-v2.stl]
2023-03-16 Re-join every 10 days
    To get around connections issues with long g/w downtimes, the end-device joins every 10 days once it is deployed.
    [lorawan.cpp]
2023-04-13 added high-level sensor deployment steps
2023-05-02 Final Iteration Copies
    [solar-panel-mount-final.f3d, solar-panel-mount-final.step, solar-panel-mount-final.stl]
2023-06-13 Update flood-sensor-deployment-manual.md
    I have completed most the doc just have to add images
2023-11-01 Add files via upload
    Final version after testing solar panel out in lab/ in field
    [Solar-panel-mount-final-iteration-standoff.f3d, Solar-panel-mount-final-iteration-standoff.step, Solar-panel-mount-final-iteration-standoff.stl]
2023-11-13 add new modes - EASY_DEP_MODE, ADV_DEP_MODE
    ### ADV_DEP_MODE
    * Application change can be triggered over the air from the TTN console
    * By default the sensor is staged in the testing/lab application and is moved over to the live application up on deployment.
    * Default mode is config mode when not deployed
    * Default mode is sensing mode after deployed
    * To deploy switch to live app and start sensing.
    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

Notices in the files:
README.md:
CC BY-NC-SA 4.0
